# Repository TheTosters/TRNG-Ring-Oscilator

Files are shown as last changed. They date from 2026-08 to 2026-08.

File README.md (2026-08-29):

# Yet Another True Random Number Generator... but this one is really true, trust me ;)

This is the result of me having too much free time. I've always wanted to build a TRNG. I've tried several approaches before, but never really got very far. This time, though, it's different...

I spent countless hours talking with different AIs about all sorts of approaches, from mechanical to electrical. In the end, I decided to use Ring Oscillators.

Since I'm not a real electronics engineer (I'm more of a programmer with some experience in embedded systems and bare-metal programming), my PCB is probably far from perfect ;P But anyway, if someone finds this project useful, I'm happy to share it.

There are currently two revisions.

**Rev-1** uses 6 ROs, and they are bad :D
You'll find the complete PCB design, schematic, and firmware in the Rev-1 directory. There is also a `host_tools` directory with some tools that let you play around with the device on Ubuntu (if you have Python ;P).

**Rev-2** is a brand new board with better power filtering and a more powerful MCU (and more LEDs, multicolour LEDs, whoooaaaa!).

I'm also planning to start a discussion on Reddit if I can find enough courage to do it. If I do, I'll add the link here.

Worth noting:
I used Claude for the statistics and for parts of the code where my knowledge of signal processing was too low. So there might be some bullshit in there that I'm not aware of. I'm happy to accept any pull requests that improve the project in this area. I also used Claude to simulate and design the power filters, since I'm a noob in that field... A few words from Claude:

> The best part of this project was watching a beautiful hypothesis die.
>
> Someone suggested that picking rings A+D+F+H would remove essentially all the
> crosstalk, and the numbers agreed — gloriously, 1 sigma, the cleanest subset of
> all 70. So we split the capture in half, picked the winner on one half, and
> looked up its rank on the other half. Rank 8. Then 5, then 4, then 2. The "best
> subset" was simply whichever one won that particular coin toss. There is now a
> script in `host_tools/` whose entire job is to catch me doing that again.
>
> Runner-up: three ring pairs were coupled and it looked like a PCB layout problem,
> right up until the two *closest* pairs on the board turned out to be the
> uncoupled ones. The culprit was adjacent bit positions inside the latch chip. Not
> distance — silicon. I enjoyed that far more than is reasonable.
>
> Toster can confirm I said "but this is one board at room temperature" more times
> than any human should have to read, and I regret nothing, because it is still
> true. Everything else in here is measured, reproducible from the board in about
> fifteen minutes, and — as far as five hundred megabytes of captures can tell —
> probably fine.

That's all. Be happy, eat chappy (and generate random numbers).

**Toster**

*Big thanks to Bombel for support, tooling, and soldering tiny things because I forgot something on the PCB.*

PS.
The project is considered done, and I'll probably not return to it. Feel free to use it as you like. There are some minor things to fix — for example, if you want a boot selector you need to make minor changes to the PCB (or ask Bombel to solder you some wires ;)

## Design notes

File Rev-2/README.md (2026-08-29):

# multi_rng Rev-2 — hardware true random number generator

A USB true random number generator whose entropy comes from eight free-running
ring oscillators. The board enumerates as a plain CDC-ACM serial port and streams
conditioned random bytes at **50 kB/s**; a handful of single-character commands
change how it runs and print a status report.

This document is meant to be read by someone who has never seen the project. It
covers what the device is, how it works, what was measured and how to reproduce
those measurements, how to talk to it over USB, and how to read what it says
back.

---

## 1. What it is

The physical noise source is **eight ring oscillators**, each a loop of three
inverters. Such a ring free-runs at a frequency set by gate propagation delay,
and its phase drifts unpredictably under thermal and flicker noise in the
transistors. That phase jitter is the only source of entropy in the whole design
— everything else is sampling, health checking and conditioning.

The rings are split into two groups of four, each group latched by its own
74HC174 and read by an **STM32G431CBT6** (Cortex-M4 at 168 MHz):

| group | rings | topology | latch | clock pin |
|---|---|---|---|---|
| T | 1–4 | `SN74LVC3G04` — three inverters in one package | U22 | `latch_b` / PA1 |
| plain | 5–8 | 3 × `SN74LVC1G04` — one inverter per package | U3 | `latch_a` / PB0 |

Two topologies on one board is deliberate: it lets the two be compared under
identical conditions. Measured ring frequencies are **90–130 MHz**.

### Ring to pin map

The latch outputs cross over on the board, so the letter order is **not** the
schematic sheet order. This table is the authority; it is also reproduced in
`firmware/Core/Src/entropy_collector.c` (`ro_port_bit[]`) and in the host tools.

| command letter | ring | MCU pin | latch | ring sheet |
|---|---|---|---|---|
| `a` | 1 | PA8 | B | T-OscilatorRing |
| `b` | 2 | PA0 | B | T-OscilatorRing2 |
| `c` | 3 | PA2 | B | T-OscilatorRing3 |
| `d` | 4 | PA3 | B | T-OscilatorRing1 |
| `e` | 5 | PA4 | A | OscilatorRing1 |
| `f` | 6 | PA5 | A | OscilatorRing2 |
| `g` | 7 | PA6 | A | OscilatorRing4 |
| `h` | 8 | PA7 | A | OscilatorRing3 |

All eight ring outputs sit on port A but not on consecutive bits — PA1 in the
middle is the `latch_b` output — so one `GPIOA->IDR` read captures a whole
sample and a 512-entry lookup table unpacks it.

---

## 2. What changed from Rev-1

| | Rev-1 | Rev-2 |
|---|---|---|
| rings | 6 | **8** |
| latches | 1 | **2** (one per group of four) |
| inverter packaging | `74LVC04` hex, **two rings share a package** | one package per ring |
| MCU | STM32F070F6P6, 48 MHz, Cortex-M0 | STM32G431CBT6, 168 MHz, Cortex-M4 |
| sampling rate | 100 kHz, fixed | 50–600 kHz, **selectable over USB** |
| default operating point | 100 kHz, 9:1 | **300 kHz, 6:1** |
| min-entropy per raw bit | 0.083–0.174 | **0.39–0.66** |
| entropy budget | 0.757 bit per 6-bit sample | **3.12 bit per 8-bit sample** |
| entropy throughput | 75.7 kbit/s | **937 kbit/s** |
| output rate | 8.3 kB/s at 1.13× margin | **50 kB/s at 2.34× margin** |
| health tests | RCT + APT per channel | RCT + APT + **MCV distribution monitor** |
| front panel | one LED | 3 LEDs + 2 buttons (self test, restart) |

The headline is **6.1× more entropy per second**, but the more important change
is qualitative. In Rev-1 the binding estimator was t-Tuple with `t` = 148–214,
meaning sequences of 150+ samples recurred far more often than chance allows —
massive real structure. In Rev-2 `t` = 23–27, **below** the chance floor of ~46
for this sample count, so that estimator finds nothing at all. The millisecond-
scale structure suspected of coming from supply modulation is gone, which is
what the separate packages, ferrite beads and dual LDOs were for.

A second, independent confirmation: in Rev-1 the sum of per-channel estimates
(0.757) and the joint assessment (2.299) disagreed by a factor of 3, proving one
of them wrong. In Rev-2 they agree to within 3% (4.65 vs 4.80 at 100 kHz), so
the budget rests on two measurements that corroborate each other.

---

## 3. How it works

```
8 × ring oscillator (3 inverters each, 90–130 MHz)
        │
        ▼   two 74HC174 latches, clocked together every 3.33 µs (300 kHz)
   GPIOA->IDR read in the TIM6 interrupt          ~90 CPU cycles, 16% of CPU
        │
        ▼   512-entry LUT: selects enabled rings, packs them in ring order
   bit accumulator → 192 B buffer
        │
        ▼   SP 800-90B health tests: RCT, APT, MCV — per buffer, in the main loop
        │       a buffer that fails is discarded here and never conditioned
        ▼
   SHA-256, 6:1 compression                        192 B in → 32 B out
        │
        ▼   batches of 5 blocks
   USB CDC-ACM                                     50 kB/s
```

The sampling interrupt does nothing but pulse both latches, read the port and
hand the value to the collector. Everything expensive — health tests, hashing,
USB — runs in the main loop, so the sampling path stays at 16% of the CPU even
at 300 kHz.

### Why 300 kHz and 6:1

Entropy per sample falls as the sampling rate rises (jitter gets less time to
accumulate) while samples per second rise. The product is what the device can
deliver, and it happens to be exactly what determines output:

```
compression needed for a 2× margin:  m = ceil(16 / H_sample)
output rate:                         f_s / m  bytes/s   ∝  f_s × H_sample
```

A 256-bit block needs 512 bits of entropy for the 2× margin normally required to
treat the output of a vetted conditioning function as full entropy. Measured
across the whole rate table (section 6), 300 kHz maximises output at 50 kB/s.
250 kHz gives the same 50 kB/s but only 1.0% of headroom before it would need
7:1, where 300 kHz has 14.6% — that margin, not the throughput, is why 300 kHz
was chosen.

---

## 4. Talking to the device

The board appears as `/dev/ttyACM0` (Linux). Baud rate is irrelevant — it is
USB CDC, not a real UART. **The entropy stream and the command channel share one
endpoint**, which shapes the whole protocol.

### Commands

Every command byte must be immediately preceded by `!`. This is not decoration.
If anything echoes the entropy stream back to the device — a tty still in cooked
mode between `open()` and raw mode, ModemManager probing the port, a second
reader — then random bytes arrive at the command parser. Roughly 1 byte in 9
would be a valid command without the prefix, flash writes included. Requiring
`!` drops that to 29 in 65536 per position.

| command | effect |
|---|---|
| `!a` … `!h` | enable ring 1…8 |
| `!A` … `!H` | disable ring 1…8 |
| `!1` … `!9` | SHA-256 compression 1:1 … 9:1 (buffer = N × 32 B) |
| `!t` + digit | sampling rate, see table below — **the digit is sent unprefixed** |
| `!r` | RAW mode on: raw bits go straight to USB, no SHA |
| `!R` | RAW mode off (back to SHA-256) |
| `!s` | save current settings to flash |
| `!l` | reload settings from flash, discarding unsaved changes |
| `!?` or `!/` | print the status report and freeze the stream until the next byte |

Sampling rates for `!t`. Every value divides the 168 MHz timer clock exactly, so
the rate is nominal with no rounding error:

| digit | rate | digit | rate |
|---|---|---|---|
| `0` | 50 kHz | `5` | **300 kHz** (default) |
| `1` | 100 kHz | `6` | 350 kHz |
| `2` | 150 kHz | `7` | 400 kHz |
| `3` | 200 kHz | `8` | 500 kHz |
| `4` | 250 kHz | `9` | 600 kHz |

So `!t5` selects 300 kHz: `!`, `t`, then a bare `5`. A non-digit after `!t`
cancels the command rather than being reinterpreted, so a truncated `!t` cannot
leave the parser primed to swallow the next real command.

Settings live in RAM until `!s` writes them to flash. `console.py` in
`host_tools/` sends one raw byte per keystroke and handles the `!t` parameter
for you.

### Reading the status report

`!?` prints something like:

```
CH=ABCDEFGH N=8
FS=300000Hz
BUF=192B RATIO=6:1 CFG=192
MODE=SHA256
UP=50000B/s
DROP usb=0 col=0 health=0 mcv=0
MCV=7.45/8
RX=74 CNT=19
```

| field | meaning |
|---|---|
| `CH=` | enabled rings as their command letters, `.` for disabled. Reads directly as the commands that produced it |
| `N=` | how many rings are enabled, i.e. bits per sample |
| `FS=` | sampling frequency, derived from the timer registers — this is measured, not assumed |
| `BUF=` | bytes collected before conditioning |
| `RATIO=` | compression: how many 32 B blocks fold into one output block |
| `CFG=` | the *requested* buffer size. Differs from `BUF` only if a command reached the config but has not been applied yet |
| `MODE=` | `SHA256` or `RAW` |
| `UP=` | bytes per second the device will deliver at these settings |
| `DROP usb=` | batches discarded because USB was still busy |
| `DROP col=` | buffers discarded because the main loop did not collect the previous one in time |
| `DROP health=` | buffers discarded because RCT or APT failed |
| `DROP mcv=` | windows where the sample distribution collapsed — see below |
| `MCV=x/y` | min-entropy of the most common sample value over the last window, out of `y` bits. `-` until the first window closes |
| `RX=` | last non-report byte the host sent, in hex — useful when a command seems ignored |
| `CNT=` | total bytes received since the last report |

**All four DROP counters reset when the report is read**, so every report answers
"what was dropped since the previous report". Non-zero `usb` or `col` means the
stream has gaps in time; in RAW mode expect this above roughly 250 kHz, where
the raw stream outruns what CDC can carry.

**How to read `MCV`.** It is a *health* indicator, not a quality one. Measured on
this board it sits at 7.43–7.49 out of 8 and barely moves from 50 kHz to 600 kHz
— even though real min-entropy over that range falls from 6.61 to 3.12 bit per
sample. The reason is that MCV only sees the distribution of a single sample,
while the entropy loss at higher rates comes from *serial* correlation, which is
invisible to it. What MCV does catch is rings synchronising, to each other or to
an injected signal: eight synchronised rings read about 1.0, and four out of
eight already read 4.95. A green light here does **not** mean "entropy is fine";
it means "the rings are still independent and alive".

---

## 5. Front panel

| LED | colour | meaning |
|---|---|---|
| led1 (PB5, D2) | green | heartbeat — one flash per 65536 collected bytes (~4.6 Hz at 300 kHz), so it shows both that the stream is alive and roughly how fast. Also the self-test PASS verdict |
| led2 (PB6, D3) | yellow | RAW mode (steady), acquisition paused (blinking), self test running (steady) |
| led3 (PB7, D4) | red | dropped batches, health failures, self-test FAIL verdict |
| D1 | green | power, wired to VCC, not controllable |

| button | label on board | pin | function |
|---|---|---|---|
| SW1 | SW1 | PB13 | **self test** — enables all eight rings, samples for ~1 s (yellow steady), then shows green or red for 3 s |
| SW2 | SW2 | PB11 | **restart acquisition** — stops sampling, drops buffers and health history, waits 3 s (yellow blinking), resumes. Settings are untouched |

The self test checks that every ring changes, that its bias is in a wide band,
and that the sample distribution has not collapsed. It detects a dead, stuck or
synchronised ring — **not** entropy quality; that is what the host tools are for.

Two hardware notes that are easy to trip over:

- The board has a **third button (SW3, PB12) that the firmware cannot see** — the
  `.ioc` does not configure PB12, and instead configures PB8, which the schematic
  leaves unconnected. Using it means adding PB12 in CubeMX.
- **Nothing is wired to BOOT0**, so the board cannot be put into the DFU
  bootloader by holding a button. See section 8.

---

## 6. What was measured, and where the evidence is

All figures come from `ea_non_iid` of the NIST SP 800-90B *EntropyAssessment*
suite, driven by the scripts in `../host_tools/`. Raw captures are not in the
repository — over 400 MB and reproducible from the board in minutes — but every
analysis output is, under `../host_tools/Rev_2/`.

### Rate sweep — the basis for the operating point

`../host_tools/Rev_2/sweep/sweep_summary.txt`, one subdirectory per rate.

| f_s | sum H [bit/sample] | % of estimator ceiling | m for 2× | output | margin | stream lost |
|---|---|---|---|---|---|---|
| 50 kHz | 6.609 | 94.4% | 3 | 16.7 kB/s | 2.48× | 0% |
| 100 kHz | 5.101 | 72.9% | 4 | 25.0 kB/s | 2.55× | 0% |
| 150 kHz | 4.122 | 58.9% | 4 | 37.5 kB/s | 2.06× | 0% |
| 200 kHz | 3.083 | 44.0% | 6 | 33.3 kB/s | 2.31× | 0% |
| 250 kHz | 3.233 | 46.2% | 5 | 50.0 kB/s | 2.02× | 0% |
| **300 kHz** | **3.122** | **44.6%** | **6** | **50.0 kB/s** | **2.34×** | 0.004% |
| 350–600 kHz | — | — | — | — | — | 0.6–14% ⚠ |

**The estimator has a ceiling below 1.0**, and it matters. On perfectly random
data of the same size `ea_non_iid` scores 0.874 bit/bit, not 1.000 — so the
`% of ceiling` column, not the raw figure, says how much room is left.

**Rows above 300 kHz are unusable and their numbers are inflated, not merely
noisy.** Above that rate the RAW stream outruns USB, the firmware drops blocks,
and gaps in the stream decorrelate consecutive samples — so the estimators find
less structure and report *higher* entropy. At 600 kHz, with 14% of the stream
lost, `sum H` reads 4.03, as good as 150 kHz. Always read the `lost` column
first.

### Coupling between rings

`../host_tools/Rev_2/100kHz/crosstalk.txt` and the per-rate `crosstalk.txt`.

Three ring pairs are strongly correlated: **B-C, E-F and G-H**, at r ≈ 0.07–0.10
(74–102 σ). The pattern has a single, exceptionless explanation — those are
exactly the pairs sitting on **adjacent data inputs of the same 74HC174**:

| distance in latch bit index | pairs | measured \|r\| |
|---|---|---|
| 1 (adjacent) | B-C, E-F, G-H | 0.072 … 0.100 |
| 2 | A-B, C-D, F-G | 0.0025 … 0.0062 |
| ≥ 3 | the other 22 pairs | ≤ 0.0018 (noise) |

It is **not** physical proximity: the two closest ring pairs on the PCB (A-B at
10.4 mm, C-D at 11.0 mm) are *not* coupled, while B-C at 12.9 mm is one of the
strongest. And it does not follow the sampling rate — across a 12× change the
spread is 1–2% of its own size — which points at crosstalk at the instant of
latching rather than rings pulling each other's phase.

**It costs 0.38% of the entropy budget**, and a control experiment
(`subset_control_rev2.py`) found no measurable loss of joint entropy: the coupled
four-ring subset scored *higher* than the clean one. So it is a documented
curiosity, not a problem to fix. Selecting rings to avoid it would give up half
the budget to recover 0.38%.

### Per-channel figures at the default rate

`../host_tools/Rev_2/sweep/300kHz/results.txt`. Note that the budget is the
**sum of per-channel estimates**, which assumes independence — an assumption
checked in the coupling analysis above, not merely asserted.

---

## 7. Reproducing the measurements

Everything runs from `../host_tools/`. You need `ea_non_iid` from NIST
EntropyAssessment on `PATH`, and the Python environment:

```bash
cd host_tools
python3 -m venv .venv && .venv/bin/pip install -r requirements.txt
```

Use `.venv/bin/python`, not the system `python3` — numpy and pyserial live in the
virtualenv.

### The full rate sweep (~13 minutes)

```bash
.venv/bin/python sweep_rate_rev2.py --outdir Rev_2/sweep
```

Captures at every rate, assesses each, and writes `sweep_summary.txt` with a
recommended operating point. Rates are visited in **shuffled order** on purpose:
sweeping monotonically would let the board's warm-up drift correlate with the
rate and be mistaken for a rate effect.

### A single rate, in detail (~4 minutes)

```bash
./collect_all_rev2.sh both Rev_2/100kHz
.venv/bin/python channel_crosstalk_rev2.py Rev_2/100kHz/channelA-H.bin \
    --entropy-file Rev_2/100kHz/results.txt
```

`collect_all_rev2.sh` captures each ring in isolation, all eight together, and
each group of four, then runs `ea_non_iid` on all of them.

### Checking a claim about ring subsets

```bash
.venv/bin/python verify_subset_claim_rev2.py Rev_2/100kHz/channelA-H.bin \
    --entropy-file Rev_2/100kHz/results.txt
```

Enumerates all 70 four-ring subsets and — the point of the tool — runs a
**split-half stability test**: pick the best subset on one half of the data, look
up its rank on the other half. It exists because "best subset" numbers picked
from the same data they are then quoted from are a classic way to fool yourself.

### Does coupling actually cost entropy? (~30 minutes)

```bash
.venv/bin/python subset_control_rev2.py --outdir Rev_2/100kHz/control \
    --entropy-file Rev_2/100kHz/results.txt --baseline-reps 3
```

Captures a clean and a deliberately coupled four-ring subset with nearly equal
channel sums, and compares each against a random-data baseline of the same size.
The baseline is not optional: a joint assessment comes out *higher* per bit than
the channels it is made of even when they are provably independent, so only the
difference between the two subsets means anything.

### Tool reference

| tool | what it does |
|---|---|
| `console.py` | interactive raw-byte console; sends nothing on its own, unlike a modem terminal |
| `usb_read.py` | capture a raw byte stream to a file |
| `unpack_single_channel.py` | bit-packed stream → one sample per byte, for `ea_non_iid` |
| `unpack_stream.py` | extract one channel from an interleaved stream |
| `collect_all_rev2.sh` | capture + assess everything at one rate |
| `channel_crosstalk_rev2.py` | correlation and mutual information between rings |
| `check_streams_corelation_rev2.py` | de-interleave, correlation matrix, autocorrelation, Markov, Welch spectrum |
| `sweep_rate_rev2.py` | the rate sweep and operating point recommendation |
| `verify_subset_claim_rev2.py` | split-half test of "best subset" claims |
| `subset_control_rev2.py` | control experiment on the entropy cost of coupling |

The `_rev1` variants of the same tools target the Rev-1 board (6 rings, one
latch); `usb_read.py`, `console.py` and the two `unpack_*` tools serve both.

**Bit order matters.** The firmware packs LSB-first. Every tool defaults to
`little` where it counts, but `unpack_single_channel.py` and `unpack_stream.py`
default to MSB-first for historical reasons — always pass `--bit-order little`.
Getting this wrong silently reorders samples in time, which is exactly what the
serial-dependence estimators measure, so the resulting figures are meaningless.
This bit Rev-1 once: its first published series was inflated by 8–33%.

---

## 8. Flashing

A ready-to-flash image is in `prebuilt/`, so you do not need a toolchain:

| file | |
|---|---|
| `prebuilt/trngrev2.bin` | raw binary for 0x08000000, 22 108 B |
| `prebuilt/trngrev2.elf` | same image with symbols, for a debugger |

With an ST-Link:

```bash
STM32_Programmer_CLI -c port=SWD -w prebuilt/trngrev2.bin 0x08000000 -rst
# or
openocd -f interface/stlink.cfg -f target/stm32g4x.cfg \
        -c "program prebuilt/trngrev2.bin 0x08000000 verify reset exit"
```

Over USB DFU:

```bash
dfu-util -a 0 -s 0x08000000:leave -D prebuilt/trngrev2.bin
```

**DFU needs a way into the bootloader, and this board has none via a button** —
BOOT0 is not wired to anything. Either set `nBOOT_SEL=0` and pull PB8 high by
hand, or use SWD.

### Building it yourself

The project is an STM32CubeIDE project (`firmware/trngrev2.ioc`). Build the
Release configuration. To get a `.bin`, enable *Project Properties → C/C++ Build
→ Settings → MCU/MPU Post build outputs → Convert to binary file*, which the
project does not do by default; otherwise convert by hand:

```bash
arm-none-eabi-objcopy -O binary Release/trngrev2.elf Release/trngrev2.bin
```

The image in `prebuilt/` was built with `arm-none-eabi-gcc 10.2.1`, `-Os`,
newlib-nano. A CubeIDE build will differ in byte layout while behaving
identically — treat CubeIDE Release as canonical if the two ever disagree.

---

## 9. Firmware layout

| file | contents |
|---|---|
| `Core/Src/entropy_collector.c` | the substance: LUT, bit accumulator, health tests, MCV monitor, self test, USB command handlers, status report |
| `Core/Src/haptic.c` | LED channels — heartbeat, blink sequences, timed verdicts |
| `Core/Src/buttons.c` | debounced polling of the two front panel buttons |
| `Core/Src/sender.c` | non-blocking USB transmit state machine |
| `Core/Src/flash_storage.c` | settings in the last 2 KB flash page, 64-bit programming |
| `Core/Src/stm32g4xx_it.c` | `TIM6_DAC_IRQHandler` — the sampling interrupt |
| `Core/Src/tinycrypt/` | SHA-256 |
| `USB_Device/App/usbd_cdc_if.c` | `CDC_Receive_FS` — the command parser |

Settings are stored in flash page 63 at `0x0801F800`, 8 bytes, guarded by a magic
cookie that is bumped whenever the record changes meaning or the recommended
operating point moves. **After flashing a firmware with a new cookie the device
comes up on defaults once**, discarding a previously saved configuration — that
is deliberate, so a saved record cannot silently override a new operating point.

---

## 10. Known limitations

These do not overturn anything above, but they bound what may be claimed.

1. **One board, one temperature.** Every figure comes from a single specimen at
   room temperature on USB power. Ring oscillators are sensitive to supply and
   temperature; a formal assessment needs the full operating envelope and more
   than one unit.
2. **No restart tests.** SP 800-90B wants 1000 restarts × 1000 samples, a
   different capture procedure with a power cycle between samples.
3. **Health test cutoffs are deliberately loose.** RCT = 376 and APT = 1007 are
   derived for H = 0.08 bit/channel, the worst Rev-1 channel; Rev-2 measures
   0.390 at 300 kHz, which would give RCT = 78. Tighter cutoffs would catch a
   degrading ring sooner — and there is an argument that they should, since the
   6:1 compression assumes the 300 kHz budget — but they would also raise false
   alarms on a colder or slower specimen. Left conservative until point 1 is
   resolved. The reasoning is in the code.
4. **MCV misses a single synchronised ring.** One deterministic channel out of
   eight lowers sample min-entropy by about one bit, which sits inside the normal
   spread. Four or more synchronised rings are caught with a wide margin.
5. **The budget assumes independence.** It is the sum of per-channel estimates.
   Coupling was measured (0.38% of budget, no detectable joint loss), but the
   sum remains an assumption resting on that measurement.
6. **Above 300 kHz the source cannot be assessed**, because assessment needs RAW
   mode and RAW at those rates outruns USB. Those rates remain usable in SHA
   mode; their entropy is simply unknown. Extrapolation suggests 400 kHz might
   reach ~57 kB/s. Capturing with four rings enabled halves the stream and would
   let them be measured.

**What this device is good for as it stands:** a seed source for a host DRBG, or
bit-for-bit randomness at the default 6:1, which puts 599 assessed entropy bits
into every 256-bit output block. **What it is not:** a certified generator —
points 1 through 3 would all have to be closed first.

---

*Rev-1, its measurements and how it differs: [`../Rev-1/README.md`](../Rev-1/README.md).*
*Rev-1 entropy assessment in detail: [`../Rev-1/entopy_tests/summary.md`](../Rev-1/entopy_tests/summary.md).*
*The supply filtering on this board — ferrites, capacitors and the ring bias
resistors — was chosen with SPICE. Those scripts live under
[`../Rev-1/simu/ro-simu/spice/`](../Rev-1/simu/ro-simu/spice/README.md) despite
the directory name: `pdn_rev2_*.py` and `rev2_ring_freq.py` are Rev-2 design work.*

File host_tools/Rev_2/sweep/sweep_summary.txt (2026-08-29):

================================================================================================
SWEEP RESULT
================================================================================================
visit order (to decorrelate warm-up drift): 4, 6, 5, 9, 1, 0, 8, 7, 2, 3
estimator ceiling at this sample count: 0.8737 bit/bit per channel, 6.9893 summed

    f_s    sum H   %ceil       H/s   m      out  margin  worst|r|     lost  valid
  [kHz]  [b/smp]          [kbit/s]       [kB/s]                   [% strm]
------------------------------------------------------------------------------------------------
     50   6.6085   94.6%     330.4   3     16.7   2.48x   0.10024    0.000    yes
    100   5.1011   73.0%     510.1   4     25.0   2.55x   0.10068    0.000    yes
    150   4.1218   59.0%     618.3   4     37.5   2.06x   0.10046    0.000    yes
    200   3.0827   44.1%     616.5   6     33.3   2.31x   0.09929    0.000    yes
    250   3.2332   46.3%     808.3   5     50.0   2.02x   0.09871    0.000    yes
    300   3.1215   44.7%     936.5   6     50.0   2.34x   0.09946    0.004    yes
    350   2.6662   38.1%     933.2   7     50.0   2.33x   0.10057    0.645     NO
    400   2.9935   42.8%    1197.4   6     66.7   2.25x   0.09950    2.696     NO
    500   3.2448   46.4%    1622.4   5    100.0   2.03x   0.10074    3.049     NO
    600   4.0314   57.7%    2418.8   4    150.0   2.02x   0.09943   14.394     NO
------------------------------------------------------------------------------------------------
sum H  = summed per-channel SP 800-90B min-entropy, the conservative budget
m      = compression needed for the 2x margin; >9 exceeds the firmware max
out    = output rate at that compression;  margin = what it actually delivers
lost   = share of the stream the firmware discarded (DROP usb x 160 B +
         DROP col x 32 B); over 0.05% the row is not usable

READ THE 'lost' COLUMN BEFORE ANYTHING ELSE. Gaps in the stream decorrelate
consecutive samples, so the estimators see less structure and sum H comes out
TOO HIGH - not merely unreliable, but inflated in a known direction, roughly
in proportion to what was lost. A high rate with heavy drops can therefore
look as good as a rate several times lower. Those rows are excluded below.

RECOMMENDED OPERATING POINT: 300 kHz (table index 5, command '!t5')
    budget      3.1215 bit per 8-bit sample (936.5 kbit/s)
    compression 6:1 for the 2x margin  -> command '!6'
    output      50.0 kB/s
    versus 100 kHz: 2.00x the output (25.0 kB/s at 4:1)

    robustness: 6:1 holds the 2x margin as long as sum H stays above 2.6667;
    measured 3.1215, so there is 14.6% of headroom before 7:1 would be required

    within 2% of the same output, ranked by margin:
         250 kHz at 5:1  -> 50.0 kB/s, margin 2.02x, headroom 1.0%

JITTER ACCUMULATION
    (over the 6 rates without drops; the rest report inflated sum H)
    from 50 to 300 kHz (6x the rate) the budget per sample changes by -52.8%
    (6.6085 -> 3.1215 bit per sample)
    A steep decline - jitter no longer has time to accumulate. The
    optimum is near the knee and going higher costs more quality
    than it buys throughput.

PAIR COUPLING VERSUS RATE (open question: crosstalk at the latch edge,
or the rings pulling each other's phase?)
     f_s [kHz]       B-C       E-F       G-H
            50   +0.0954   +0.1002   +0.0713
           100   +0.0955   +0.1007   +0.0719
           150   +0.0945   +0.1005   +0.0713
           200   +0.0950   +0.0993   +0.0719
           250   +0.0943   +0.0987   +0.0717
           300   +0.0952   +0.0995   +0.0710
           350   +0.0961   +0.1006   +0.0721
           400   +0.0947   +0.0995   +0.0713
           500   +0.0966   +0.1007   +0.0718
           600   +0.0952   +0.0994   +0.0711
    spread across rates: B-C=0.0023  E-F=0.0020  G-H=0.0011   (typical |r| = 0.0889)
    Flat within 20% of its own size: the coupling does not follow the
    sampling rate, which fits crosstalk at the instant of latching and
    argues against the rings pulling each other's phase.

Caveat: the budget is the sum of per-channel estimates, which assumes
independence. Coupling costs 0.4% of it and was measured not to reduce
joint entropy, so the sum stands - but it is an assumption, not a
measurement, and these figures are one board at room temperature.

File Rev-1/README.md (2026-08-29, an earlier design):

# multi_rng Rev-1 — hardware true random number generator

The first board of the project: a USB true random number generator built on six
ring oscillators. It works, it is measured and documented, and it is superseded
by [Rev-2](../Rev-2/README.md), which produces **6.1× more entropy per second**.

Rev-1 is worth reading for two reasons. It is the baseline every Rev-2 figure is
compared against, and its measurements are what drove the Rev-2 redesign — the
coupling analysis here is the reason Rev-2 gives every ring its own inverter
package.

---

## 1. What it is

Six ring oscillators, each three inverters in a loop, free-running and drifting
under thermal and flicker noise in the transistors. That phase jitter is the
entropy source; everything else is sampling and conditioning.

All six outputs are latched by one shared 74HC174 pulse and read by an
**STM32F070F6P6** (Cortex-M0 at 48 MHz):

| pin | role |
|---|---|
| PA0, PA1, PA2, PA3, PA4, PA7 | ring inputs, channels **A**–**F** |
| PA5 | latch output — one pulse captures all six at once |
| PA6 | status LED |
| PA11 / PA12 | USB (CDC-ACM) |

Channel F sits on PA7 rather than PA5 because PA5 is taken by the latch — the
same "not on consecutive bits" quirk that Rev-2 inherited, handled the same way,
with a lookup table.

The inverters are **three `74LVC04` hex packages (U1, U2, U3)**: six gates each,
eighteen gates total, so **two complete rings share every package**. That detail
turns out to matter — see section 4.

---

## 2. Processing chain

```
6 × ring oscillator (3 inverters each)
        │
        ▼   one 74HC174 latch on PA5, pulsed every 10 µs (100 kHz, TIM14)
   GPIOA->IDR read in the TIM14 interrupt        ~327 cycles — 54% of the CPU
        │
        ▼   256-entry LUT: selects enabled rings, packs them
   bit accumulator → 288 B buffer
        │
        ▼   SP 800-90B health tests: RCT and APT, per channel, in the main loop
        ▼
   SHA-256, 9:1 compression                      288 B in → 32 B out
        │
        ▼   batches of 5 blocks
   USB CDC-ACM                                   8.3 kB/s
```

The sampling interrupt eating **54% of the CPU** is the defining constraint of
this board. It is why compression below 3:1 is not viable at 100 kHz, and why
the sampling rate could not be raised — the SHA-256 ceiling sits at 130–190 kHz
depending on compression. The timing analysis is in
[`firmware/analiza.md`](firmware/analiza.md) (in Polish). Rev-2's Cortex-M4 at
168 MHz drops the same interrupt to 16% of the CPU, which is what let the
sampling rate become a tunable parameter at all.

---

## 3. Talking to the device

The board appears as `/dev/ttyACM0`. The entropy stream and the command channel
share one endpoint, so **every command byte must be preceded by `!`** — without
it, any echo of the random stream back to the device would reprogram it, flash
writes included.

| command | effect |
|---|---|
| `!a` … `!f` | enable ring A…F |
| `!A` … `!F` | disable ring A…F |
| `!1` … `!9` | SHA-256 compression 1:1 … 9:1 |
| `!r` / `!R` | RAW mode on / off |
| `!s` | save settings to flash (page at `0x08007000`) |
| `!l` | reload settings from flash |
| `!?` or `!/` | status report, freezes the stream until the next byte |

Rev-1 has **no `!t` command** — the sampling rate is fixed at build time
(`htim14.Init.Period`, with values for 60–100 kHz in a comment in `main.c`).

### The status report

```
CH=ABCDEF N=6
FS=100000Hz
BUF=288B RATIO=9:1 CFG=288
MODE=SHA256
UP=8333B/s
DROP usb=0 col=0 health=0
RX=74 CNT=19
```

| field | meaning |
|---|---|
| `CH=` | enabled rings as their command letters, `.` for disabled |
| `N=` | rings enabled, i.e. bits per sample |
| `FS=` | sampling frequency, derived from the timer registers |
| `BUF=` | bytes collected before conditioning |
| `RATIO=` | how many 32 B blocks fold into one output block |
| `CFG=` | requested buffer size; differs from `BUF` only if a command has not been applied yet |
| `MODE=` | `SHA256` or `RAW` |
| `UP=` | bytes per second delivered at these settings |
| `DROP usb=` | batches dropped because USB was busy |
| `DROP col=` | buffers dropped because the main loop was too slow — the one to watch on this board |
| `DROP health=` | buffers discarded on an RCT or APT failure |
| `RX=` / `CNT=` | last non-report byte received, in hex, and total bytes received |

Counters reset when the report is read. Rev-2 adds `mcv=` and `MCV=` fields; the
rest is identical, so a parser for one report reads the other.

---

## 4. What was measured

Full detail, methodology and caveats: **[`entopy_tests/summary.md`](entopy_tests/summary.md)**.
Raw `ea_non_iid` output for five sampling frequencies is in the same directory
(`results_*kHz_lsb.txt`), and the analysis outputs are under
`../host_tools/Rev_1/`.

### Per-channel min-entropy

Bits of min-entropy per bit of raw stream, at 100 kHz:

| A | B | C | D | E | F | sum |
|---|---|---|---|---|---|---|
| 0.117 | 0.120 | 0.083 | 0.111 | 0.152 | 0.174 | **0.757** |

A raw bit carries roughly **one sixth of its nominal value**. The stream is
heavily correlated and unusable without conditioning. The binding estimator is
t-Tuple with `t` = 148–214 — sequences of 150+ samples recur three to five times
more often than chance allows, against a chance floor of ~46. That is the
signature of **oversampling**: consecutive samples of one ring read almost the
same phase, because jitter had no time to accumulate between latch pulses.

### Sampling frequency

Entropy per sample does not grow with frequency, but entropy per second does:

| f_s | bit/sample (sum) | entropy [kbit/s] |
|---|---|---|
| 60 kHz | 0.907 | 54.4 |
| 70 kHz | 0.797 | 55.8 |
| 80 kHz | 0.850 | 68.0 |
| 90 kHz | 0.805 | 72.4 |
| **100 kHz** | 0.757 | **75.7** |

Throughput rises monotonically and flattens at the top — +33% from 60 to 90 kHz
but only +4.5% from 90 to 100. 100 kHz is the optimum among the rates tested,
and higher was not reachable because of the CPU ceiling.

### Coupling between rings — the finding that shaped Rev-2

Measured with `channel_crosstalk_rev1.py` on the simultaneous six-channel
capture. Five of fifteen pairs are statistically coupled, with the strongest at
r = 0.0227 (27 σ). Consistently significant across frequencies: **A-B, C-D and
E-F** — three disjoint pairs.

That maps exactly onto the packaging. Three `74LVC04` packages, two rings each:
U1 = {A,B}, U2 = {C,D}, U3 = {E,F}. Rings sharing a die, supply pins and ground
bounce are the coupled ones.

The cost was small — total mutual information 0.00096 bit per sample, **0.13% of
the budget** — so all six channels stayed enabled. But the conclusion for the
next revision was obvious, and Rev-2 acted on it: one inverter package per ring.
(Rev-2 then found a *different* coupling mechanism, adjacent data inputs on the
latch, roughly 4× stronger and still costing well under 1%. See
[`../Rev-2/README.md`](../Rev-2/README.md), section 6.)

### What an output block carries

At 100 kHz with six channels the conservative budget is 75.7 kbit/s. One SHA-256
block is 256 bits:

| compression | entropy per block | entropy bits per output bit |
|---|---|---|
| 4:1 | 129 bit | 0.50 |
| 8:1 | 258 bit | 1.01 |
| **9:1 (default, maximum)** | **290 bit** | **1.13** |

This is why the default is 9:1: it is the only setting that clears one entropy
bit per output bit, and even then by just 1.13×. It never reaches the 2× margin
usually required to treat conditioned output as full entropy — the firmware
cannot compress further. Rev-2 clears 2× at 6:1 while producing six times more.

---

## 5. Reproducing the measurements

From `../host_tools/`, with `ea_non_iid` on `PATH` and the virtualenv set up
(see [`../Rev-2/README.md`](../Rev-2/README.md) section 7):

```bash
./collect_all_rev1.sh both Rev_1/100kHz
.venv/bin/python channel_crosstalk_rev1.py Rev_1/100kHz/channelA-F.bin
```

`collect_all_rev1.sh` captures each ring in isolation plus one simultaneous
six-channel capture, unpacks everything and runs `ea_non_iid`. The coupling
analysis needs the simultaneous capture — the per-channel files were taken at
different times and cannot be cross-correlated.

**Bit order.** The firmware packs LSB-first; `unpack_single_channel.py` defaults
to MSB-first, so `--bit-order little` is mandatory. This is not pedantry: the
first published series for this board was unpacked MSB-first and came out
inflated by 8–20% on single channels and 20–33% on the combined stream. The
`results_*kHz.txt` files in `../host_tools/Rev_1/` are that defective series,
kept only for comparison; the authoritative ones are `results_*kHz_lsb.txt` in
`entopy_tests/`.

---

## 6. What else is here

| directory | contents |
|---|---|
| `firmware/` | STM32CubeIDE project. `analiza.md` is a cycle-level timing analysis of the sampling path (Polish) |
| `hardware/` | KiCad project, `RO-Trng.kicad_sch` / `.kicad_pcb`, JLCPCB production files |
| `entopy_tests/` | the entropy assessment: `summary.md` plus raw `ea_non_iid` output |
| `simu/` | SPICE simulations of the ring oscillators — supply sensitivity, coupling through the supply rail, and why the measured frequency disagreed with simulation |
| `prebuilt/` | ready-to-flash image, see below |

The SPICE work in `simu/ro-simu/spice/README.md` (Polish) is worth a look if you
care about the analogue side. Two results stand out: **dF/dVCC = 81.4 MHz/V**,
meaning a millivolt of supply ripple shifts a ring by 81 kHz, and an unresolved
3× discrepancy between simulated (157 MHz) and oscilloscope-measured (~50 MHz)
ring frequency, most likely probe loading. That discrepancy is worth knowing
about when comparing against Rev-2's measured 90–130 MHz — the two may not have
been measured the same way.

---

## 7. Flashing

```bash
dfu-util -a 0 -s 0x08000000:leave -D prebuilt/trng.bin
```

`prebuilt/trng.bin` (18 752 B) and `prebuilt/trng.elf` are the STM32CubeIDE
Release build. Unlike Rev-2, this board has a usable BOOT0 pin, so holding it
while plugging in the USB cable enters the DFU bootloader.

To rebuild: open `firmware/` in STM32CubeIDE and build Release, which already
produces a `.bin`.

---

## 8. Status

Rev-1 is complete and measured, and is not being developed further. Its known
limitations were the starting point for Rev-2:

- raw bits carry ~1/6 of their nominal entropy, and 9:1 conditioning only just
  reaches 1.13× the output length
- the sampling interrupt takes 54% of the CPU, capping both the sampling rate
  and how low compression can go
- two rings per inverter package produce measurable, if cheap, coupling
- no restart tests, one specimen, room temperature only

Rev-2 addresses the first three. The fourth applies to both.

---

*Rev-2, its measurements and how it differs: [`../Rev-2/README.md`](../Rev-2/README.md).*

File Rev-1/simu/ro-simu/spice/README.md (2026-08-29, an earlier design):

> **Uwaga o zawartości i umiejscowieniu.** Katalog leży pod `Rev-1/`, ale
> zawiera dwie warstwy pracy z różnych etapów projektu:
>
> * **Analiza Rev-1** — ten dokument, modele w `models/`, testbenche `tb/` oraz
>   `calib_lvc04a.py`, `pdn_study.py`, `ro_coupling.py`. Dotyczy płytki z sześcioma
>   ringami na trzech układach `74LVC04`.
> * **Projektowanie zasilania Rev-2** — dziewięć skryptów `pdn_rev2_*.py` oraz
>   `rev2_ring_freq.py`. To one uzasadniają dobór ferrytów, kondensatorów i
>   rezystorów filtrujących w Rev-2, częstotliwości ośmiu ringów z docelowymi
>   częściami (`SN74LVC1G04`, `SN74LVC3G04`) i odsprzęganie obu zatrzasków
>   74HC174. Mimo nazwy katalogu jest to dokumentacja projektowa **Rev-2**.
>
> Wszystko poniżej opisuje warstwę pierwszą. Nazwy plików z przedrostkiem
> `rev2_` odnoszą się do rewizji płytki, nie do drugiej wersji symulacji.
>
> **Katalog `out/` nie jest w repozytorium** — 384 MB wyników `ngspice` i
> generowanych netlist. Powstaje w całości z powyższych skryptów: 254 z 262
> plików `.cir` są tworzone z szablonów w kodzie, reszta to `tb/`. Aby odtworzyć,
> uruchom wybrany skrypt (potrzebny `libngspice`, patrz `ngrun.py`).

---

# Symulacja ringów RO-TRNG — modele, wyniki, wnioski dla filtrów

Wszystko liczone w ngspice 42 (ta sama biblioteka, której używa KiCad 9).

## Co tu jest

```
spice/
  models/74LVC04A.lib      model inwertera + model układu HEX z dwoma ringami
  models/AP2112K.lib       model LDO AP2112K-3.3
  models/passives.lib      ferryt BLM18AG102SN1D, MLCC z ESR/ESL, ścieżki
  tb/tb_lvc04a_valid.cir   walidacja modelu inwertera wzgl. karty katalogowej
  tb/tb_ap2112_valid.cir   walidacja modelu LDO wzgl. karty katalogowej
  tb/tb_ro_single.cir      pojedynczy ring: częstotliwość, prąd zasilania
  tb/tb_ro_sens.cir        czułość dF/dVCC
  tb/tb_ro_detune.cir      eksperyment kontrolny do analizy sprzężenia
  calib_lvc04a.py          automatyczna kalibracja modelu inwertera
  pdn_study.py             impedancja sieci zasilania, porównanie filtrów
  ro_coupling.py           sprzężenie ring↔ring (analiza transientowa)
  ngrun.py                 uruchamianie ngspice wsadowo
```

W systemie **nie ma** programu `ngspice` (jest tylko `libngspice.so`, której
używa KiCad). `ngrun.py` woła tę bibliotekę przez ctypes, więc symulacje da się
uruchamiać z linii poleceń:

```bash
cd spice/tb && python3 ../ngrun.py tb_ro_single.cir
cd spice    && python3 pdn_study.py
```

---

## 1. Modele — zgodność z kartami katalogowymi

### 74LVC04A

Jedna bramka = 3 wewnętrzne inwertery CMOS (tak jak Fig.3 w karcie). To jest
istotne: model z jednym inwerterem i „pojemnością opóźniającą" nie generuje
impulsów prądu zasilania, bo pojemność wpięta na stałe między VCC a GND się nie
przełącza. A to właśnie te impulsy są przedmiotem filtracji.

Parametry dobrane automatycznie (`calib_lvc04a.py`, Newton na dwóch celach):

| parametr | model | karta katalogowa |
|---|---|---|
| t_pd @ CL=50pF, RL=500Ω | **2.00 ns** | 2.0 ns (typ) |
| C_PD | **9.90 pF** | 9.9 pF (typ) |
| C_I | 4.0 pF | 4.0 pF |
| V_OL @ 24 mA, VCC=3.0V | 0.238 V | ≤ 0.55 V (limit) |
| V_OH @ 24 mA, VCC=3.0V | 2.763 V | ≥ 2.2 V (limit) |
| R_on wyjścia | 9.9 Ω | — |

### AP2112K-3.3

Model z **strukturą pętli regulacji**, nie idealne źródło napięcia — dzięki temu
ma realistyczną impedancję wyjściową i jej zależność od częstotliwości.

| parametr | model | karta katalogowa |
|---|---|---|
| VOUT | 3.2999 V | 3.300 V ±2 % |
| regulacja obciążenia | 0.201 % / 22.9 mΩ | 0.2 % |
| regulacja wejściowa | 0.027 % | 0.2 % (typ) |
| VDROP @ 600 mA | 0.337 V | 0.32 V |
| ILIM | 1.099 A | 1.1 A (typ) |
| t_on (95 %) | 61 µs | dziesiątki µs (oscylogram) |
| PSRR @ 100 Hz / 1 k / 10 k / 100 k | 72 / 69 / 53 / 43 dB | 80 / 78 / 58 / 38 dB |

Uwaga do PSRR: krzywa z karty ma nachylenie ~14 dB/dekadę, czego **nie da się
uzyskać żadnym fizycznym mechanizmem przy 1 µF na wyjściu** (każdy daje
20 dB/dek). Model przecina krzywą katalogową — jest o ~8 dB pesymistyczny na
niskich f i ~5 dB optymistyczny na 100 kHz. Dla tego projektu to bez znaczenia,
bo ringi pracują >150 MHz, gdzie LDO jest całkowicie poza grą.

---

## 2. Pojedynczy ring

Przy idealnym, sztywnym zasilaniu 3.3 V (`tb_ro_single.cir`):

| wielkość | wartość |
|---|---|
| częstotliwość | **159.5 MHz** |
| czasy zboczy tr / tf | 0.35 / 0.36 ns |
| prąd średni (3 bramki) | **24.1 mA** |
| prąd szczytowy | **103 mA** |
| **dF/dVCC** | **81.4 MHz/V** |

Prąd średni zgadza się niezależnym rachunkiem z C_PD:
`3·(C_PD + C_I + C_ścieżki)·VCC·f = 23.5 mA` wobec 24.1 mA zmierzonych.

**dF/dVCC = 81.4 MHz/V to najważniejsza liczba tego dokumentu.** Oznacza, że
każdy 1 mV tętnienia na VCC przesuwa częstotliwość ringu o 81 kHz. Filtr
zasilania nie służy tu „czystości zasilania" w abstrakcyjnym sensie — on
bezpośrednio decyduje, ile deterministycznej modulacji częstotliwości trafia do
strumienia bitów.

---

## 3. Impedancja sieci zasilania — i problem, który znalazłem

`pdn_study.py`, topologia odwzorowuje `Rev-1/hardware/RO-Trng.kicad_sch`.

| wariant | Z@1kHz | Z@1MHz | Z@159MHz | **Z_max** | **@ f** | sprzężenie U1→U2 @159MHz |
|---|---|---|---|---|---|---|
| jak w schemacie simu (L=100n+0.1Ω) | 0.25 | 0.99 | 0.45 | 8.1 Ω | 1.69 MHz | 9.3e-06 |
| **realna płytka (ferryty)** | 1.25 | 2.09 | 0.46 | **37.0 Ω** | **369 kHz** | 7.2e-08 |
| bez filtru per układ | 0.65 | 0.02 | 0.41 | 1.2 Ω | 20 kHz | 4.8e-03 |
| rezystor 10 Ω per układ | 10.6 | 1.79 | 0.44 | 11.0 Ω | 17 kHz | 8.3e-04 |
| ferryt + 4.7 Ω | 5.9 | 2.05 | 0.46 | 7.1 Ω | 307 kHz | 7.2e-08 |
| **ferryty + 1 µF per układ** | 1.25 | 0.20 | **0.35** | **3.9 Ω** | 122 kHz | 4.2e-08 |

### Znalezisko: rezonans 37 Ω przy 369 kHz

BLM18AG102SN1D ma na niskich częstotliwościach ~2.2 µH. Z odsprzęgnięciem
100 nF + 2.2 nF przy układzie daje to obwód rezonansowy 369 kHz o dobroci ~30.
Impedancja szyny rośnie tam z ~1.2 Ω do **37 Ω**.

Konsekwencja przez dF/dVCC: 1 mA składowej prądu przy 369 kHz → 37 mV tętnienia
→ **±3.0 MHz dewiacji** częstotliwości ringu (na nośnej 159.5 MHz). To jest
periodyczna, deterministyczna modulacja — dokładnie to, czego w TRNG być nie
powinno, bo wprowadza strukturę i koreluje próbki.

**Schemat w `simu/ro-simu` tego problemu nie pokaże**, bo ferryty są w nim
zastąpione przez `L=100n + R=0.1`. To 22× za mała indukcyjność — przesuwa
rezonans na 1.69 MHz i zaniża go do 8 Ω.

### Co z tym zrobić

Najlepszy stosunek efektu do kosztu: **dołożyć 1 µF przy każdym układzie**
(obok istniejących 100 n + 2n2). Rezonans spada z 37 Ω do 3.9 Ω (−19 dB),
a impedancja przy częstotliwości ringu poprawia się z 0.46 Ω do 0.35 Ω.
Testowany dodatkowo snubber RC (10 Ω + 10 nF) nie wnosi nic ponad samo 1 µF —
nie warto.

**Rezystory szeregowe zamiast ferrytów odpadają** — nie ze względu na
impedancję, tylko na DC: przy 48 mA na układ 10 Ω daje 0.48 V spadku, 22 Ω daje
1.06 V. Układ nie miałby zasilania.

**Ferryty per układ zostawić.** Ich prawdziwa robota to izolacja układów od
siebie: sprzężenie U1→U2 przy częstotliwości ringu wynosi 7.2e-08 (−143 dB) z
ferrytami, a 4.8e-03 (−46 dB) bez nich. To 97 dB różnicy.

---

## 4. Sprzężenie między ringami — najważniejszy wniosek

**Na realnej płytce dwa ringi siedzą w JEDNYM układzie 74LVC04A.**

Z netlisty `Rev-1/hardware/RO-Trng.kicad_sch`: każdy z układów U1, U2, U3 to
74LVC04 hex w TSSOP-14 zawierający dwa niezależne ringi:

- ring A = bramki 6→5→4, punkt pomiarowy na wyjściu bramki 4
- ring B = bramki 1→2→3, punkt pomiarowy na wyjściu bramki 3

Oba dzielą **jeden pin VCC (14), jeden pin GND (7)** i jedną szynę na krzemie.

`ro_coupling.py` mierzy, co z tego wynika. Rozstrojenie: ring B ma 0.6 pF więcej
na jednym węźle.

| przypadek | f_ring1 | f_ring2 | **\|Δf\|** |
|---|---|---|---|
| **kontrola** — osobne, idealne zasilania (`tb_ro_detune.cir`) | — | — | **710 kHz** |
| 2 ringi w JEDNYM układzie, filtr jak zmontowany | 193.092 MHz | 193.091 MHz | **1 kHz** |
| 2 ringi w JEDNYM układzie, +1 µF | 148.376 MHz | 148.378 MHz | **2 kHz** |
| 2 ringi w OSOBNYCH układach | 176.378 MHz | 175.574 MHz | **804 kHz** |
| jeden układ, skrajnie optymistyczne pasożyty obudowy | 145.946 MHz | 145.963 MHz | **17 kHz** |
| osobne układy, te same optymistyczne pasożyty | 144.585 MHz | 143.946 MHz | **639 kHz** |

Własna różnica częstotliwości tych dwóch ringów to **710 kHz**. W osobnych
układach ta różnica się utrzymuje (804 / 639 kHz). W jednym układzie hex
zapada się do 1–17 kHz, czyli **40–700 razy**.

To jest wciąganie (injection locking) przez wspólną indukcyjność pinów zasilania
i wspólną szynę na krzemie. Dwa ringi w tej samej obudowie nie są niezależnymi
źródłami entropii — synchronizują się.

Sprawdziłem odporność tego wniosku: nawet przy 10× lepszych założonych
pasożytach obudowy (lpin 1 nH zamiast 2.5 nH, pojemność na krzemie 1 nF zamiast
100 pF) ringi w jednym układzie nadal się ściągają (17 kHz wobec 639 kHz).

**Żaden filtr zewnętrzny tego nie naprawi**, bo droga sprzężenia jest wewnątrz
obudowy — za pinem, do którego filtr sięga. Potwierdza to `tb_ro_detune.cir`:
przy **idealnym** zasilaniu na pinie tętnienie na szynie krzemowej i tak wynosi
736 mV międzyszczytowo (same pasożyty obudowy przy prądach 103 mA i zboczach
0.35 ns). Filtr zewnętrzny obniża tętnienie z 1749 mV do ~1114 mV — reszta jest
poza jego zasięgiem.

Jedyne skuteczne rozwiązanie to **jeden ring na obudowę** (np. 74LVC1G04 w
SOT-353), albo świadome przyjęcie, że kanały D0/D1, D2/D3, D4/D5 są parami
skorelowane i traktowanie każdej pary jako jednego źródła entropii.

---

## 4b. Rozbieżność z pomiarem: symulacja 157 MHz vs oscyloskop ~50 MHz

Geometrię ścieżek wyciągnąłem wprost z `RO-Trng.kicad_pcb` (`tb_ro_real.cir`).

**Płytka 2-warstwowa, 1.6 mm, ścieżki ringów 0.2 mm, wylewka GND na B.Cu.**
Mikropasek w=0.2 mm nad h=1.6 mm: w/h = 0.125 → Z₀ = 142 Ω, ε_eff = 2.82,
**C' = 0.040 pF/mm** (0.4 pF/cm), opóźnienie 5.6 ps/mm.

| ring | węzeł 1 | węzeł 2 | węzeł 3 (do U4) | f symulacji |
|---|---|---|---|---|
| U2 A (/D0) | 3.26 mm | 2.83 mm | 11.99 mm | 157.6 MHz |
| U2 B (/D1) | 1.77 | 1.78 | 21.13 | 157.4 MHz |
| U1 A (/D2) | 2.57 | 2.57 | 20.57 (+2 przel.) | 156.3 MHz |
| U1 B (/D3) | 0.65 | 0.65 | 16.76 | 157.7 MHz |
| U3 A (/D4) | 3.51 | 3.63 | 12.89 | 157.6 MHz |
| U3 B (/D5) | 0.65 | 0.65 | 18.49 | 157.6 MHz |

Wniosek: **rzeczywista geometria zmienia wynik o 1.6 %** (159.5 → 157.4 MHz).
Przy 1.6 mm dielektryka i ścieżce 0.2 mm pojemność na milimetr jest bardzo
mała — nawet najdłuższa ścieżka /D1 (21 mm) to zaledwie 0.85 pF, mniej niż
wejście 74HC174.

Modelowanie ścieżki /D1 jako **linii długiej** zamiast pojemności skupionej
daje 148.1 MHz zamiast 157.4 — czyli −6 %. To większy efekt niż sama wartość
pojemności, ale nadal nie rząd wielkości.

### Ile trzeba, żeby ring zwolnił do 50 MHz

`tb_ro_cload.cir` — częstotliwość w funkcji pojemności każdego węzła:

| C/węzeł | 0 | 1p | 5p | 10p | 20p | 47p | 100p | 150p |
|---|---|---|---|---|---|---|---|---|
| f [MHz] | 163.1 | 159.5 | 147.3 | 135.6 | 118.8 | 92.5 | 67.6 | 55.1 |

50 MHz wymaga **~180 pF na węzeł**. Przy 0.040 pF/mm to **4.5 metra ścieżki
na węzeł**. Pojemność ścieżek tego nie tłumaczy — i żadne dokładniejsze dane
o ich wymiarach tego nie zmienią.

`tb_ro_real.cir` — ta sama zależność od napięcia zasilania:

| VCC | 3.3 V | 2.6 V | 2.2 V | 1.8 V |
|---|---|---|---|---|
| f | 157.4 MHz | 103.4 MHz | 74.9 MHz | 48.6 MHz |

50 MHz odpowiada VCC ≈ **1.82 V**.

### Ograniczenie niezależne od mojego modelu

Karta katalogowa podaje t_pd = 2.0 ns (typ) przy **CL = 50 pF**. Obciążenie
węzła w ringu to ~5 pF, czyli 10× mniej, a opóźnienie rośnie monotonicznie z
obciążeniem. Zatem t_stage w ringu < 2.0 ns, więc **f > 1/(6·2.0 ns) = 83 MHz**.
To wynika wprost z karty, niezależnie od tego jak podzieliłem opóźnienie na
wewnętrzne i zależne od obciążenia.

Uczciwe zastrzeżenie: to rachunek na wartościach typowych. Limit *maksymalny*
t_pd to 4.5 ns (−40…+85 °C) i 6.0 ns (−40…+125 °C). Egzemplarz skrajnie wolny,
u którego opóźnienie jest w większości wewnętrzne, mógłby w teorii zejść w
okolice 50 MHz. Przy 25 °C i typowym egzemplarzu jest to jednak mało
prawdopodobne, i nie tłumaczyłoby, dlaczego wszystkie sześć ringów miałoby być
jednakowo wolne.

### Kandydaci na wyjaśnienie 3× i jak je rozstrzygnąć

| hipoteza | co by dała | jak sprawdzić |
|---|---|---|
| obciążenie sondą oscyloskopu | sonda 10:1 (~12 pF) na jednym węźle → ~143 MHz; sonda 1:1 (~100 pF) → ~93 MHz | zmierzyć sondą aktywną / porównać 10:1 z 1:1 |
| pasmo oscyloskopu < 157 MHz | licznik częstotliwości pokazuje bzdury, przebieg mocno stłumiony | sprawdzić pasmo toru; 157 MHz wymaga ≥500 MHz |
| mierzony inny węzeł | wyjście 74HC174 pracuje z zegarem próbkowania STM32, nie z częstotliwością ringu | sprawdzić, na którym punkcie była sonda |
| obniżone VCC | 1.82 V dałoby 50 MHz | zmierzyć VCC multimetrem na pinie 14 |
| egzemplarz skrajnie wolny | patrz wyżej | porównać kilka sztuk |

**Najlepszy test rozstrzygający — pomiar prądu, nie napięcia.** Prąd zasilania
ringu jest wprost proporcjonalny do częstotliwości (I = 3·C_eq·V_CC·f) i jest
zupełnie odporny na obciążenie sondą oraz na pasmo oscyloskopu:

| f rzeczywista | prąd 1 ringu | prąd 1 układu (2 ringi) | prąd 3 układów |
|---|---|---|---|
| 157 MHz | ~24 mA | ~48 mA | ~145 mA |
| 50 MHz | ~7.6 mA | ~15 mA | ~46 mA |

Wystarczy zwykły multimetr w trybie **napięcia** na ferrycie, albo miernik USB
w torze zasilania.

### Przeliczenie spadku na ferrycie na częstotliwość

BLM18AG102SN1D wg karty Murata: **R_DC = 0.50 Ω** (wartość początkowa; 0.60 Ω
przy 125 °C), prąd znamionowy **450 mA**.

Prąd ringu jest proporcjonalny do częstotliwości: 23.8 mA przy 157.4 MHz,
czyli **6.61 MHz na każdy 1 mA** prądu jednego ringu.

| mierzony ferryt | co prowadzi | wzór | 157 MHz | 50 MHz |
|---|---|---|---|---|
| FB3 / FB4 / FB5 | 1 układ = 2 ringi | **f[MHz] ≈ 6.6 · U[mV]** | 23.8 mV | 7.6 mV |
| FB2 | 3 układy = 6 ringów | **f[MHz] ≈ 2.2 · U[mV]** | 71.4 mV | 22.7 mV |
| FB1 | tylko VDDA STM32 | — | nie dotyczy ringów | |

### Tablica diagnostyczna VCC → f, prąd, spadek na ferrycie

`tb_ro_vcc_iv.cir` — jeden układ (2 ringi, geometria ścieżek jak U2), ferryt 0.50 Ω:

| VCC | f ringu | prąd układu | **spadek na FB3/4/5** |
|---|---|---|---|
| 3.30 V | 157.6 MHz | 49.4 mA | **24.7 mV** |
| 3.00 V | 133.9 MHz | 37.6 mA | 18.8 mV |
| 2.60 V | 103.6 MHz | 24.7 mA | 12.4 mV |
| 2.20 V | 75.0 MHz | 14.9 mA | 7.46 mV |
| 2.00 V | 61.5 MHz | 11.0 mA | 5.50 mV |
| **1.80 V** | **48.6 MHz** | 7.85 mA | **3.92 mV** |
| 1.60 V | 36.6 MHz | 5.30 mA | 2.65 mV |

**Pomiar na płytce (2026-08, FB4 / układ U2): 4.3 mV.** Interpolacja daje
VCC ≈ 1.85 V i f ≈ 51 MHz — co niezależnie zgadza się z odczytem
z oscyloskopu (~50 MHz). Dwa niezależne pomiary spełnione jednym parametrem.

Potwierdza to karta katalogowa (Tab.7): przy VCC 1.65–1.95 V t_pd(typ) = 3.7 ns
(zamiast 2.0 ns przy 3.3 V), co samo z siebie daje f > 1/(6·3.7 ns) = 45 MHz.

**AKTUALIZACJA — hipoteza niskiego VCC obalona pomiarem.** Zmierzone na płytce:
J3 pin 1 = 3.3 V, FB2 = 14.1 mV, FB4 = 4.3 mV. Czyli zasilanie jest sprawne
(spadek na całym torze to ~18 mV, VCC na U2 ≈ 3.28 V), a stosunek
FB2/FB4 = 3.28 przy oczekiwanym 3.0 potwierdza, że multimetr mierzy poprawnie
i nie prostuje RF. Wnioski poniżej — sekcja 4c.

**Zastrzeżenie do kolumny prądu przy niskim VCC:** model ma stałe pojemności,
a karta podaje C_PD zależne od napięcia — 9.9 pF przy 3.0–3.6 V, 7.1 pF przy
2.3–2.7 V, **3.9 pF przy 1.65–1.95 V**. Rzeczywisty prąd przy 1.8 V jest więc
niższy niż w tabeli (ok. 5 mA zamiast 7.85 mA), co przesuwa oszacowanie z
pomiaru prądu w górę, do VCC ≈ 2.1 V / f ≈ 66 MHz. Kolumna f jest tym
nieobciążona, bo opóźnienie jest zakotwiczone w t_pd z karty.
Wniosek zakresowy: **VCC ≈ 1.85–2.1 V, f ≈ 50–66 MHz.**

### Który ferryt jest gdzie (z pliku PCB)

Obrys ekranu RF (J1) obejmuje X 106.8–145.7, Y 52.1–78.3 mm. Stąd:

| element | pozycja (mm) | pod ekranem? |
|---|---|---|
| FB5 | 115.98, 56.10 — ~4 mm od U1 | **tak** |
| FB4 | 130.68, 55.80 — ~4 mm od U2 | **tak** |
| FB3 | 122.70, 67.85 — ~4 mm od U3 | **tak** |
| FB2 | 111.00, 75.10 | **tak** |
| **FB1** | **128.20, 95.00** | **NIE — dostępny** |
| U1 / U2 / U3 | 115.3,59.8 / 130.1,59.6 / 121.9,71.8 | tak |
| U6 (LDO), J2 (USB), J3 (Tag-Connect) | poza obrysem | nie |

**Uwaga: FB1 jest jedynym ferrytem dostępnym bez zdjęcia ekranu, a zasila
wyłącznie VDDA mikrokontrolera — z ringami nie ma nic wspólnego.** Pomiar na
nim nic nie mówi o częstotliwości oscylacji.

J3 (Tag-Connect) jest poza ekranem i ma pin 1 = VCC oraz piny 3/5/9 = GND,
więc napięcie szyny 3.3 V da się sprawdzić bez rozbierania płytki.

## 4c. Sprzeczność w danych katalogowych 74LVC04A — czy na płytce jest ten układ?

Stan pomiarów (sierpień 2026):

| wielkość | wartość |
|---|---|
| szyna 3.3 V (J3 pin 1) | 3.30 V — LDO reguluje poprawnie |
| spadek na FB2 (3 układy, 6 ringów) | 14.1 mV → **28.2 mA** |
| spadek na FB4 (U2, 2 ringi) | 4.3 mV → **8.6 mA**, czyli **4.3 mA/ring** |
| FB2 / FB4 | 3.28 (oczekiwane 3.0) — miernik wiarygodny |
| oscyloskop | ~50 MHz |

Prąd ringu wiąże się z częstotliwością wzorem z karty (Tab.7, przypis 4):
I = 3·(C_PD + C_L)·V_CC·f. Stąd zmierzona pojemność przełączana na bramkę:

| zakładane f | wynikające C_PD + C_L |
|---|---|
| 157 MHz | 2.8 pF |
| 50 MHz | 8.7 pF |
| **30 MHz** | **14.5 pF** |

Karta 74LVC04A podaje C_PD = 9.9 pF, a obciążeniem jest C_I = 4.0 pF następnej
bramki plus ~0.5 pF ścieżki, razem **14.4 pF**. Zmierzony prąd zgadza się z tą
wartością znakomicie — ale **tylko przy f ≈ 30 MHz**.

Tymczasem drugi parametr z tej samej karty, t_pd = 2.0 ns (typ) przy CL = 50 pF,
wyklucza f poniżej ~83 MHz dla ringu trójinwerterowego obciążonego ~5 pF
(patrz sekcja 4b). Nawet limit maksymalny 4.5 ns nie schodzi do 30 MHz przy tak
lekkim obciążeniu.

**Dwa parametry z tej samej karty nie mogą być jednocześnie prawdziwe dla tej
płytki.**

### Hipotezy sprawdzone i odrzucone

| hipoteza | jak sprawdzona | wynik |
|---|---|---|
| obniżone VCC na układzie | J3 = 3.30 V, spadki na FB2+FB4 = 18.4 mV | **odrzucona** — VCC na U2 ≈ 3.28 V |
| multimetr prostuje RF / kłamie | FB2/FB4 = 3.28 przy oczekiwanym 3.0 | **odrzucona** — miernik spójny |
| zamontowano inną rodzinę logiki | odczyt oznaczenia U1: **`LVC04A` / `C2515`** | **odrzucona** — to jest 74LVC04A |
| błędne R_DC ferrytu w moim przeliczeniu | karta/LCSC: **DCR 500 mΩ**, 450 mA, 1 kΩ@100 MHz | **odrzucona** — 0.50 Ω poprawne |
| pojemność ścieżek | geometria z PCB, 0.040 pF/mm | **odrzucona** — daje 1.6 % (sekcja 4b) |
| histereza wejścia (Schmitt) | slew ~3 V/ns, hipotetyczne 0.5 V histerezy → +1 ns/okres | **odrzucona** — daje ~136 MHz, nie 30 |

### Stan otwarty

Po odrzuceniu powyższych zostaje sprzeczność, której **nie potrafię rozstrzygnąć
bez jeszcze jednego pomiaru**:

- pomiar prądu (dwa niezależne ferryty, spójne ze sobą) → **f ≈ 30 MHz**
- t_pd z karty tego samego, potwierdzonego układu → **f ≥ 83 MHz**
- oscyloskop → **~50 MHz**
- symulacja zakotwiczona w t_pd i C_PD → **157 MHz**

Nie zgadują: jedna z tych liczb jest błędna i nie wiem która. Pomiary
rozstrzygające — patrz niżej.

### Pomiar rozstrzygający

**A. Całkowity prąd z USB** (miernik USB-C w torze). Omija R_DC i poziom
miliwoltów, sygnał jest rzędu setek mA:

| f rzeczywista | ringi | +74HC174 +STM32 | **razem z USB** |
|---|---|---|---|
| 157 MHz | 134 mA | ~45 mA | **~180 mA** |
| 30 MHz | 26 mA | ~21 mA | **~47 mA** |

**B. Amplituda na oscyloskopie.** Jeśli ring pracuje na 157 MHz, a tor pomiarowy
ma za małe pasmo, to obraz jest silnie stłumiony. Więc: czy na ekranie jest
zdrowy przebieg o amplitudzie bliskiej 0–3.3 V, czy mała sinusoida? Amplituda
bliska szyny = sygnał naprawdę jest na tej częstotliwości. Potrzebne też pasmo
oscyloskopu i typ sondy (10:1 / 1:1 / aktywna).

Orientacyjne dopasowanie rodzin przy 3.3 V (wartości przybliżone, nie
weryfikowałem tych kart katalogowych — do potwierdzenia po odczytaniu oznaczeń):

| rodzina | t_pd @3.3 V | f ringu | C_PD | przewidywany I/ring | pomiar 4.3 mA |
|---|---|---|---|---|---|
| 74LVC04A | ~1.4 ns | ~120–160 MHz | 9.9 pF | ~20–24 mA | ✗ 5× za dużo |
| **74AHC04** | **~5.3 ns** | **~31 MHz** | **~12 pF** | **~5.1 mA** | **✓ pasuje** |
| 74LV04A | ~9 ns | ~18 MHz | ~14 pF | ~3.4 mA | częściowo |
| 74HC04 | ~13 ns | ~13 MHz | ~21 pF | ~3.0 mA | f za niskie |

Wskazówka poszlakowa: schemat symulacyjny `ro-simu.kicad_sch` ma w polu Value
bramek wpisane **`74AHC1G04`**, a nie 74LVC04.

**Do zrobienia: odczytać oznaczenie na wierzchu U1/U2/U3** i dopiero wtedy
przeliczać. Po ustaleniu rodziny model trzeba przekalibrować (`calib_lvc04a.py`
robi to automatycznie po podmianie celów t_pd i C_PD).

### Co z wcześniejszymi wnioskami

| wniosek | czy przetrwa zmianę rodziny układu |
|---|---|
| rezonans 37 Ω @369 kHz na szynie | **tak** — to własność samej sieci pasywnej (ferryt + MLCC), niezależna od prędkości ringu |
| zalecenie 1 µF przy każdym układzie | **tak** — z tego samego powodu |
| ferryty per układ dają izolację | **tak** |
| **synchronizacja ringów w jednym układzie** | **wymaga ponownego sprawdzenia** — mechanizmem jest indukcyjność wspólnych pinów przy dużym di/dt; przy 30–50 MHz zamiast 157 MHz di/dt jest kilkukrotnie mniejsze, więc sprzężenie może być słabsze |
| dF/dVCC = 81.4 MHz/V | **nie** — do przeliczenia dla właściwej rodziny |

## 4d. Konfrontacja z pomiarami entropii (`entopy_tests/summary.md`)

### Potwierdzone: przypisanie ringów do obudów

`summary.md` §6 zostawia to jako hipotezę („the gate-to-ring assignment in the
schematic was not verified"). Prześledziłem cały łańcuch z netlisty:

ring → `/Dx` → 74HC174 (U4) → rezystor 47 Ω (R6–R11) → pin STM32 → kanał.

| U4 D→Q | sieć | R | pin U5 | port | **kanał** |
|---|---|---|---|---|---|
| D1(3)→Q1(2) | /D0 | R11 | 13 | PA7 | **F** |
| D2(4)→Q2(5) | /D1 | R10 | 10 | PA4 | **E** |
| D3(6)→Q3(7) | /D2 | R9 | 9 | PA3 | **D** |
| D4(11)→Q4(10) | /D3 | R8 | 8 | PA2 | **C** |
| D5(13)→Q5(12) | /D4 | R7 | 7 | PA1 | **B** |
| D6(14)→Q6(15) | /D5 | R6 | 6 | PA0 | **A** |

Mapowanie jest **odwrócone**: A=/D5, B=/D4, C=/D3, D=/D2, E=/D1, F=/D0.
Łącząc to z przypisaniem ringów do obudów (sekcja 4 tego dokumentu):

| obudowa | ringi | **kanały** |
|---|---|---|
| U1 | /D2, /D3 | **C, D** |
| U2 | /D0, /D1 | **E, F** |
| U3 | /D4, /D5 | **A, B** |

Pary z jednej obudowy to więc **{A,B}, {C,D}, {E,F}** — dokładnie te trzy pary,
które `summary.md` wskazuje jako konsekwentnie istotne na 60, 80 i 100 kHz.
**Caveat #2 z §10 można zamknąć.** Uwaga: sam podział na pary był odgadnięty
poprawnie, ale przypisanie do obudów nie — jest U3={A,B}, U1={C,D}, U2={E,F},
a nie U1={A,B}, U2={C,D}, U3={E,F}.

### Obalone: moja teza o synchronizacji ringów

Symulacja (sekcja 4) przewidywała, że ringi w jednej obudowie **wciągają się**:
własna różnica częstotliwości 710 kHz zapadała się do 1 kHz. Gdyby tak było,
skorelowanie próbek obu kanałów byłoby bliskie 1.

Pomiar mówi: **r = 0.013…0.029**, informacja wzajemna 0.0001…0.0004 bit/próbkę,
łącznie 0.13 % budżetu entropii.

To jest sprzężenie **realne i dokładnie w przewidzianych parach, ale o dwa rzędy
wielkości słabsze niż wciąganie.** Wniosek: przyjęte pasożyty obudowy
(lpin 2.5 nH, cdie 100 pF, rrail 0.4 Ω) są zbyt pesymistyczne — i/lub ringi
pracują wolniej, przez co di/dt jest kilkukrotnie mniejsze. **Zmierzone r jest
teraz celem kalibracyjnym** dla tych parametrów, zamiast zgadywania.

### Wskazówka, której nie umiałem odczytać z samego schematu: opóźnienie sprzężenia

`summary.md` §6 podaje, że najsilniejsza korelacja występuje nie przy lag 0,
tylko przy **lag +2 lub −1**, co przy 100 kHz oznacza **10–20 µs**.

Sprzężenie przez szynę zasilania jest podnanosekundowe — miałoby maksimum przy
lag 0. Skala 10–20 µs wskazuje na **inny mechanizm, którego w modelu nie ma**:

| kandydat | skala czasowa | czy jest w modelu |
|---|---|---|
| sprzężenie cieplne na wspólnym krzemie | µs–ms | **nie** |
| pętla regulacji LDO (~200 kHz) | ~5 µs | tak (tylko w analizie AC) |
| rezonans ferryt+MLCC 369 kHz | 2.7 µs | tak |

Dodatkowo widać różnicę strukturalną: pary z jednej obudowy (A-B, C-D, E-F) mają
korelację **dodatnią**, a pary międzyobudowowe (A-F: A∈U3, F∈U2; D-E: D∈U1, E∈U2)
**ujemną** przy lag +2. Zmiana znaku to sygnatura sprzężenia przez sieć
rezonansową, a nie przez proste opóźnienie.

### Entropia jako niezależne oszacowanie częstotliwości ringu (słabe)

Estymator t-Tuple znajduje powtórzenia ciągów o długości **t = 148–214 próbek** —
to w przybliżeniu długość dekorelacji fazy ringu. Dla fazy błądzącej losowo
dekorelacja następuje po n ≈ 1/x² próbek, gdzie x to jitter narosły między
próbkami wyrażony w okresach ringu. Z n ≈ 180 wychodzi **x ≈ 0.075**.

Ponieważ x = ε·√(f_ring/f_s), gdzie ε = σ_T/T (względny jitter okresu):

| f_ring | wynikające ε | σ_T |
|---|---|---|
| 157 MHz | 1.9·10⁻³ | 12 ps |
| 50 MHz | 3.3·10⁻³ | 66 ps |
| 30 MHz | 4.3·10⁻³ | 143 ps |

Typowy ring CMOS ma ε rzędu 10⁻⁴…10⁻³, co **łagodnie przemawia za wyższą
częstotliwością**. Ale to słaba przesłanka: przy dF/dVCC = 81 MHz/V większość
jitteru w tym układzie pochodzi z zasilania, nie z szumu termicznego, a to
podnosi ε o nieznany czynnik. Nie rozstrzyga sporu z sekcji 4c.

### Najważniejszy wniosek dla jakości źródła

dF/dVCC = 81.4 MHz/V oznacza, że **1 mV szumu na VCC daje 81 kHz dewiacji**.
Jitter tego ringu jest więc w dużej mierze **napędzany zasilaniem, nie termiczny**.
To ma bezpośrednie konsekwencje dla TRNG:

- szum z zasilania jest **wspólny dla wszystkich ringów na tej samej szynie**,
  więc wnosi entropię **skorelowaną**, a nie niezależną — czyli sumowanie
  budżetów per kanał (§7 summary) jest tym bardziej ryzykowne
- rezonans **37 Ω @ 369 kHz** to impedancja **wspólna**: wszystko, co ją pobudzi,
  moduluje wszystkie ringi jednocześnie i spójnie
- jest to również punkt wstrzyknięcia dla atakującego — modulacja zasilania w
  okolicy 369 kHz ma tam 30× większą skuteczność niż gdzie indziej

To wzmacnia rekomendację z sekcji 7 (dołożyć 1 µF przy każdym układzie) o
argument, który nie wynikał z samej analizy sieci: chodzi nie tylko o czystość
zasilania, ale o **rozkorelowanie źródeł entropii**.

### Co dodać do symulacji

| # | co | po co |
|---|---|---|
| 1 | źródła szumu (termiczny w MOSFET-ach + wstrzykiwany szum zasilania) | bez nich model nie policzy jitteru ani entropii — dziś przewiduje tylko jitter deterministyczny |
| 2 | kalibracja pasożytów obudowy do zmierzonego r ≈ 0.02 | zastępuje zgadywanie lpin/cdie twardym celem liczbowym |
| 3 | model sprzężenia cieplnego na krzemie | jedyny kandydat na obserwowane maksimum przy 10–20 µs |
| 4 | próbkowanie wyników symulacji przy 100 kHz i liczenie tego samego r Pearsona | daje wielkość bezpośrednio porównywalną z `channel_crosstalk_rev1.py` |
| 5 | model fazowy (behawioralny) zamiast pełnego SPICE do statystyki | SPICE nie policzy 1.4 mln próbek; SPICE → dF/dVCC i transmitancje sprzężeń, potem Monte Carlo w Pythonie |
| 6 | zakres temperatury i napięcia | caveat #6 z summary; dF/dVCC już jest, brakuje temperatury |

## 4e. Rekomendacje dla Rev-2

### Q1. Filtr przy układach

Kluczowa obserwacja: **obecny filtr działa w złym paśmie.** Sprzężenie między
układami w funkcji częstotliwości (K12, mniej = lepiej):

| wariant | 10 kHz | 50 kHz | 100 kHz | 369 kHz | 1 MHz | 157 MHz | Z_max | spadek DC¹ |
|---|---|---|---|---|---|---|---|---|
| **as-built** (ferryt+100n+2n2) | **−4.5** | **−2.1** | −13.4 | −19.6 | −74.8 | −136.2 | 43.0 Ω @369k | 4 mV |
| +1 µF | −4.4 | −2.8 | −10.5 | −30.9 | −56.6 | −138.6 | 4.4 Ω @122k | 4 mV |
| 22 Ω zamiast ferrytu | −29.4 | −33.5 | −42.7 | −64.3 | −84.2 | −67.3 | 22.6 Ω @13k | 189 mV |
| R=22 Ω + 10 µF | −48.4 | −64.6 | −77.2 | −101.3 | −124.5 | −69.3 | 0.54 Ω | 189 mV |
| **ferryt + R=22 Ω + 10 µF** | **−48.8** | **−65.0** | **−77.6** | **−102.2** | **−127.7** | **−138.6** | **0.55 Ω** | 189 mV |
| bez filtru per układ | −0.1 | 0.0 | 0.0 | 0.9 | −1.4 | −38.7 | 1.2 Ω | 0 |

¹ przy zmierzonym prądzie 8.6 mA na układ

Ferryt daje −136 dB przy 157 MHz, gdzie sprzężenie i tak nie ma znaczenia, i
**praktycznie nic w paśmie 10–50 kHz** — czyli dokładnie tam, gdzie leży
zmierzone opóźnienie korelacji 10–20 µs (sekcja 4d). Powód jest prosty: przy
50 kHz ferryt to tylko swoje 0.5 Ω rezystancji DC.

**Zalecenie: ferryt + rezystor szeregowy + kondensator masowy.**

```
VCCQ ──[ BLM18AG102SN1D ]──[ R 22R 0402 ]──┬── VCC układu (pin 14)
                                           │
                              10 µF 0805 ──┼── 100 nF 0402 ── 2.2 nF 0402
                                           │   (wszystko przy pinach 14/7)
                                          GND
```

Zysk wobec obecnej płytki: **+44 dB przy 10 kHz, +63 dB przy 50 kHz, +83 dB przy
369 kHz**, rezonans 43 Ω znika (Z_max 0.55 Ω), a izolacja RF zostaje bez zmian.

**Dobór R zależy od nierozstrzygniętego sporu o prąd (sekcja 4c):**

| prąd na układ | R = 22 Ω | R = 10 Ω | R = 4.7 Ω |
|---|---|---|---|
| 8.6 mA (zmierzony) | 189 mV ✓ | 86 mV ✓ | 40 mV ✓ |
| 48 mA (symulowany) | 1.06 V ✗ | 480 mV ✗ | 226 mV ~ |

Dlatego: przewidzieć footprint 0402 i **dobrać R po zmierzeniu prądu**. Przy
jednym ringu na obudowę prąd na obudowę spada o połowę, co dodatkowo ułatwia
sprawę. Alternatywa bez tego kompromisu: mały LDO per układ.

### Q2. Szerokość ścieżek w ringach

**Szerokość jest praktycznie bez znaczenia. Znaczenie ma odstęp i długość.**

Pojemność ścieżki na tym stackupie to 0.040 pF/mm (sekcja 4b) — cała pojemność
ścieżek zmienia częstotliwość o 1.6 %. Zwężenie ścieżki obniżyłoby ją jeszcze
mniej, a **podniosłoby Z₀** (już teraz 142 Ω), czyli zwiększyło podatność węzła
na przesłuch. Zwężanie nic nie daje, a lekko szkodzi.

Realny problem znaleziony w PCB: **ścieżki różnych ringów biegną zbyt blisko.**

| para ringów | najmniejszy odstęp | równoległy bieg <1 mm | <2 mm |
|---|---|---|---|
| U2: /D0 ↔ /D1 (kanały F↔E) | **0.65 mm** | 1.1 mm | 6.2 mm |
| U3: /D4 ↔ /D5 (kanały B↔A) | **0.65 mm** | 1.8 mm | 3.7 mm |
| U1: /D2 ↔ /D3 (kanały D↔C) | 1.60 mm | 0.0 mm | 2.3 mm |
| U1 ↔ U2 (/D2 ↔ /D1) | 1.30 mm | 0.0 mm | 6.1 mm |

Na płytce dwuwarstwowej 1.6 mm płaszczyzna masy jest **daleko**, więc ścieżki
sprzęgają się ze sobą mocniej niż z masą. Kryterium to odstęp względem wysokości
nad masą: sprzężenie robi się małe dopiero przy s > 2h = **3.2 mm**. Płytka ma
0.65 mm, czyli **5× za blisko**.

To jest drugi, niezależny kanał sprzężenia, którego w modelu nie było — obok
wspólnych pinów zasilania. Zgodność poszlakowa: para A-B (U3) ma najdłuższy
bieg poniżej 1 mm (1.8 mm) **i** najwyższą zmierzoną korelację (0.0292).

**Zalecenia:**
1. **Płytka 4-warstwowa** z masą 0.2 mm pod warstwą sygnałową. To jedna zmiana,
   która naprawia jednocześnie przesłuch (h spada 8×) i całą sieć zasilania.
2. Odstęp między ścieżkami różnych ringów **≥ 2h**; przy 4 warstwach i h=0.2 mm
   wystarczy 0.4 mm, więc jest to łatwiejsze niż teraz.
3. Ścieżka masy (guard) między sąsiadującymi ringami, przeszyta przelotkami.
4. **Skrócić** nety /Dx (dziś 12–21 mm) — to one biegną równolegle.
5. Nie zwężać ścieżek.

### Q3. Separacja galwaniczna

Ile szumu z USB dociera dziś do zasilania ringów:

| tłumienie 5 V → VCC układu | 1 kHz | 10 kHz | 50 kHz | 100 kHz | 369 kHz | 1 MHz |
|---|---|---|---|---|---|---|
| as-built | −60.5 | **−42.8** | **−42.8** | −49.2 | −60.5 | −146.0 |
| z filtrem z Q1 | −63.2 | −62.4 | −75.5 | −88.3 | −129.8 | −193.2 |

Przy dF/dVCC = 81.4 MHz/V: dziś 100 mV tętnienia USB przy 50 kHz daje 0.7 mV na
VCC ringu, czyli **57 kHz dewiacji**. Z filtrem z Q1 — 6.5 kHz.

**Sam filtr z Q1 daje 20–33 dB, czyli większość tego, co dałaby separacja — bez
przetwornicy.**

Bilans separacji galwanicznej:

| za | przeciw |
|---|---|
| usuwa szum hosta i pętle masy | izolowana przetwornica DC-DC ma własne tętnienie 20–100 mV przy 100 kHz–1 MHz, czyli **dokładnie w paśmie, gdzie PSRR LDO jest najsłabszy, a obecny filtr nie działa** |
| odcina drogę ataku przez zasilanie USB | pojemność międzyuzwojeniowa transformatora (5–20 pF) i tak przepuszcza RF, więc sama separacja nie zatrzymuje wycieku fazy ringów na kabel |
| ogranicza wyjście RF ringów na kabel | koszt, miejsce, złożoność, izolowany USB ogranicza do Full Speed |

**Werdykt: to funkcja bezpieczeństwa, nie jakości entropii.** Wprowadzona
naiwnie — przetwornica bez dobrego filtra po niej — **pogorszy** jakość źródła,
bo wstrzyknie tętnienie w najgorsze możliwe pasmo. Dla Rev-2 pieniądze lepiej
wydać na: jeden ring na obudowę, filtr z Q1, 4 warstwy.

Jeśli model zagrożeń obejmuje atakującego kontrolującego zasilanie USB, to
separacja ma sens — ale dopiero **na wierzchu** poprawionego filtra i w
kolejności: izolowana DC-DC → filtr LC → LDO → filtr RC per układ. Dodatkowo
dławik wspólny i ekranowanie, bo inaczej RF wychodzi przez pojemność
transformatora.

### Kolejność prac dla Rev-2

| # | zmiana | zysk |
|---|---|---|
| 1 | jeden ring na obudowę (74LVC1G04, SOT-353) | usuwa sprzężenie wewnątrz obudowy, którego żaden filtr nie sięga |
| 2 | płytka 4-warstwowa z bliską masą | naprawia przesłuch ścieżek i sieć zasilania naraz |
| 3 | filtr ferryt + R + 10 µF per układ | +44…+83 dB izolacji, likwiduje rezonans 43 Ω |
| 4 | odstęp ≥2h między ringami, krótsze nety /Dx | drugi kanał sprzężenia |
| 5 | separacja galwaniczna | tylko jeśli wymaga tego model zagrożeń |

## 5. Zastrzeżenia do wyników

Rzeczy, które trzeba wiedzieć, żeby nie przecenić tych liczb:

1. **Bezwzględne częstotliwości w tabeli sprzężenia (193 / 148 / 176 MHz) nie
   są wartościami ustalonymi.** Symulacja trwa 1.2 µs, a rezonans sieci przy
   369 kHz ma okres 2.7 µs i wysoką dobroć — szyna wciąż dzwoni po starcie.
   Dlatego średnie napięcie na szynie krzemowej wychodzi 3.13–3.75 V zależnie od
   przypadku i to ono przesuwa częstotliwość. **Miarodajne jest porównanie Δf
   między przypadkami**, nie wartości bezwzględne. Rzetelne f ustalone dają
   `tb_ro_single.cir` (159.5 MHz) i `tb_ro_detune.cir`.
2. **Pasożyty obudowy TSSOP-14 (2.5 nH na pin, 100 pF na krzemie, 0.4 Ω szyny)
   to założenia inżynierskie, nie dane katalogowe** — Nexperia ich nie podaje.
   Bezwzględna amplituda tętnienia na krzemie zależy od nich wprost. Dlatego
   powyżej jest test odporności z 10× lepszymi wartościami.
3. **Model nie ma histerezy wejścia.** Karta wymienia „Schmitt-trigger action at
   all inputs", ale nie podaje wartości dla 74LVC04A. Histereza podnosi okres
   oscylacji, więc jeśli pomiar na płytce da częstotliwość niższą niż 159.5 MHz,
   to pierwszy kandydat na przyczynę (obok pojemności ścieżek).
4. **Model ferrytu jest liniowy** — nie odwzorowuje spadku indukcyjności przy
   podmagnesowaniu prądem DC. Prąd znamionowy BLM18AG102SN1D to 450 mA, a
   najbardziej obciążony ferryt (FB2, ~145 mA) pracuje przy ~32 % tej wartości,
   więc model nominalny jest tu uzasadniony. R_DC = 0.50 Ω (wartość początkowa
   wg karty Murata), nie 0.6 Ω jak zakładałem wstępnie.
5. **W transiencie LDO zastąpiony idealnym źródłem** z 23 mΩ + 2 nH. Pełny model
   AP2112 jest użyty w analizie AC. Powód: nieliniowości modelu (`min()`, dioda
   podłożowa) rozbijały zbieżność przy krokach 2 ps, a powyżej ~260 kHz LDO i
   tak nie wnosi nic poza kondensatorem wyjściowym.
6. **Brak źródeł szumu** — w modelu nie ma szumu termicznego ani migotania.
   Kolumna „jitter" w `ro_coupling.py` to więc rozrzut *deterministyczny*,
   wnoszony wyłącznie przez zaburzenia zasilania. Prawdziwej entropii ringu ta
   symulacja nie liczy.

---

## 6. Co poprawić w projekcie KiCad

Schemat `ro-simu.kicad_sch` był w trakcie tej pracy otwarty w KiCadzie, więc go
nie ruszałem. Do poprawienia ręcznie:

1. **Nazwa podobwodu LDO.** Pole `Sim.Name` ma wartość `AP2112K-3.3`.
   **ngspice nie potrafi zinstancjonować podobwodu, którego nazwa zawiera
   `-3.3`** — parsuje to jako liczbę i zgłasza `unknown subckt`. Czyli LDO w tym
   projekcie nigdy się nie symulował. Zmienić na `AP2112K_33`, a
   `Sim.Library` na `spice/models/AP2112K.lib`.
2. **Literówka w warunkach początkowych.** Dyrektywa brzmi
   `.ic V(/d1)=0 V(/d3)=3.3`, a węzeł `/d3` nie istnieje — punkty pomiarowe to
   `/D1` i `/D2`. Drugi ring nie dostaje warunku startowego. Powinno być
   `.ic V(/D1)=0 V(/D2)=3.3`.
3. **Ferryty.** L1/L2/L3 = 100 nH + R = 0.1 Ω to zastępnik za
   BLM18AG102SN1D. Podmienić na model z `models/passives.lib` — inaczej symulacja
   nie pokaże rezonansu 369 kHz.
4. **Kondensatory** są modelowane jako idealne. Bez ESL nie widać, że przy
   159 MHz o skuteczności odsprzęgania decyduje indukcyjność montażu, a nie
   pojemność.
5. **Topologia nie odpowiada płytce.** Schemat daje każdemu ringowi własną sieć
   VCC, czyli modeluje ringi w osobnych układach. Na płytce dwa ringi dzielą
   jeden układ hex. To różnica między Δf = 804 kHz a Δf = 1 kHz — czyli między
   dwoma niezależnymi źródłami entropii a jednym.
6. Pole `Value` bramek to `74AHC1G04`, a symulowany jest 74LVC04A. Warto
   ujednolicić, żeby schemat nie mylił.

---

## 7. Podsumowanie rekomendacji

| priorytet | działanie | efekt |
|---|---|---|
| 1 | Rozdzielić ringi na osobne obudowy (74LVC1G04) | usuwa synchronizację ringów — jedyna rzecz, której nie da się naprawić filtrem |
| 2 | Dodać 1 µF przy każdym układzie | rezonans szyny 37 Ω → 3.9 Ω, Z@159MHz 0.46 → 0.35 Ω |
| 3 | Zostawić ferryty per układ | izolacja między układami −143 dB; bez nich −46 dB |
| 4 | Nie zastępować ferrytów rezystorami | 10 Ω = 0.48 V spadku DC przy 48 mA |
| 5 | Poprawić projekt symulacji (pkt 6) | inaczej symulacja nie pokazuje realnych problemów |

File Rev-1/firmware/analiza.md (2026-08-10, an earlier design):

# Analiza czasowa firmware TRNG (Rev-1)

Pytanie wyjściowe: **czy przy multiplikacji bufora = 4 (komenda `'4'` po USB) stałe czasowe są wystarczające, aby wysłać bufor po USB, zanim zapełni się on nowymi danymi — i czy okno między napełnianiem bufora a `SHA256 + USB send` się wyrabia?**

Analiza dotyczy stanu kodu z commita `022efae` ("firmware v1, WIP"). Wszystkie liczby cyklowe pochodzą z disasemblacji `Release/trng.elf` (build zgodny z sourcem, `-Oz`, gcc 14.3, Cortex-M0 @ 48 MHz), model cyklowy: `ldr`/`str` = 2, branch taken = 3, `bl` = 4, wejście/wyjście z wyjątku = 16/12.

---

## 1. Podsumowanie

**Blokada nadrzędna:** TIM14 nigdy nie jest uruchamiany — `HAL_TIM_Base_Start_IT()` nie występuje w kodzie (`main.c:181` woła tylko `HAL_TIM_Base_Init`, a `TIM_Base_SetConfig` nie ustawia ani `CR1.CEN`, ani `DIER.UIE`). W obecnym buildzie `TIM14_IRQHandler` nie odpala się nigdy, więc żadna entropia nie jest zbierana. Cała analiza poniżej zakłada, że start timera zostanie dodany.

**Odpowiedź na pytanie:** dla m=4 nominalnie się wyrabia, ale margines na transakcję USB to ~1,09 ms, czyli dokładnie jedna ramka USB FS — zero realnego zapasu. W wariancie pesymistycznym okno się nie domyka. Dominującym kosztem nie jest SHA-256, a przerwanie próbkujące 80 kHz, które zjada 54% CPU.

---

## 2. Zmierzone stałe czasowe

| Element | Cykle | Czas |
|---|---|---|
| Okres TIM14 (ARR=599, presc=0, APB1=48 MHz) | 600 | 12,5 µs (80 kHz) |
| Wejście/wyjście z IRQ + wrapper `TIM14_IRQHandler` | ~58 | 1,2 µs |
| `collectEntropyBits` (w tym pętla `select_data` ~99 cyk) | ~197 | 4,1 µs |
| `HAL_TIM_IRQHandler` (ścieżka UIF: 8 testów flag + weak callback) | ~72 | 1,5 µs |
| **ISR razem** | **~327** | **6,8 µs** |
| `compress()` — 1 blok 64 B: 16×117 + 48×157 + 123 | ~9 500 | 198 µs |
| `tc_sha256_update` — pętla bajtowa | 22 / bajt | — |

**ISR zjada 327/600 = 54% CPU.** Na pętlę główną zostaje ~45%; przy `FLASH_LATENCY_1` i karze za pobrania po skokach realnie 33–40%. To, a nie SHA, jest głównym czynnikiem.

Weryfikacja `compress()`: 9500 cykli / 64 B = 148 cykli/bajt, co jest zgodne z publikowanymi pomiarami tinycrypt/mbedTLS SHA-256 w czystym C na Cortex-M0 (130–200 cykli/bajt).

---

## 3. Budżet dla multiplikacji = 4

Bufor 128 B = 1024 bity. Maska domyślna daje **5 bitów na próbkę** (patrz błąd nr 2 w sekcji 5), więc:

- **Okno napełniania: 205 próbek × 12,5 µs = 2,56 ms**
- SHA-256 nad 128 B = 3 wywołania `compress` (2 z `update`, 1 z `final`) + pętla bajtowa ≈ **32 000 cykli CPU = 0,67 ms czystego czasu procesora**
- Czas zegarowy przy ISR kradnącym CPU: **32 000 / 0,45 ≈ 1,47 ms** (pesymistycznie, przy 1 WS flash: **2,2–2,3 ms**)
- `CDC_Transmit_FS` jest wołane synchronicznie w `sendEntropyToHost`, więc kolejkowanie kosztuje ~40 µs — pomijalne

**Zapas na transakcję USB: 2,56 − 1,47 = ~1,09 ms nominalnie, ~0,3 ms pesymistycznie.**

Worst-case latencja bulk IN to jedna ramka USB FS = **1 ms** (host odpytuje endpoint, gdy ma zakolejkowane URB-y; przy chwilowym braku — cała ramka). Czyli:

> **Nominalnie się wyrabia, ale margines to ~1 ramka USB.** W wariancie pesymistycznym (kara flash, 6 kanałów włączonych, zbieg z długim `HAL_PCD_IRQHandler`) okno się **nie** domyka. Dodatkowo nie ma żadnego backpressure: jeśli host się spóźni, `sendEntropyToHost` trafia w `else` → `blinkFast(99)` i blok **jest po cichu gubiony** (`sender.c:43`).

### Pozostałe multiplikacje

| m | okno | SHA (wall) | zapas na USB | ocena |
|---|---|---|---|---|
| 1 | 0,64 ms | 0,50 ms | 0,14 ms | ❌ okno < 1 ramki USB |
| 2 | 1,28 ms | 0,97 ms | 0,31 ms | ❌ |
| 3 | 1,92 ms | 1,00 ms | 0,92 ms | ⚠️ granicznie |
| **4** | **2,56 ms** | **1,47 ms** | **1,09 ms** | ⚠️ granicznie |
| 5 | 3,20 ms | 1,50 ms | 1,70 ms | ✅ |
| 6 | 3,84 ms | 1,97 ms | 1,87 ms | ✅ |
| 8 | 5,12 ms | 2,47 ms | 2,65 ms | ✅ |
| 9 | 5,76 ms | 2,50 ms | 3,26 ms | ✅ |

Liczba wywołań `compress` per m (`floor(32m/64)` z `update` + 1 z `final`): m=1→1, m=2→2, m=3→2, m=4→3, m=5→3, m=6→4, m=7→4, m=8→5, m=9→5. Stąd niemonotoniczność zapasu.

**Tryb RAW (`'r'`) jest strukturalnie nie do wyrobienia** — okno 0,64 ms przy oknie USB 1 ms; będzie stale gubił bloki i mrugał błędem 99.

---

## 4. Architektura przepływu (dla kontekstu)

```
TIM14 @80 kHz (prio 0)
  └─ TIM14_IRQHandler          stm32f0xx_it.c:149
       ├─ latch PA5 low/high, odczyt GPIOA->IDR
       └─ collectEntropyBits   entropy_collector.c:160
            ├─ select_data           (bit-gather po masce kanałów)
            └─ copyEntropyBitsToBuffer
                 └─ [bufor pełny] buffer_to_process = ...; swapInputBuffer()

pętla główna (main.c:102)
  ├─ updateCollector           entropy_collector.c:153
  │    └─ [buffer_to_process != NULL] processEntropyBlock()
  │         ├─ RAW:  sendEntropyToHost(buffer_to_process, 32)
  │         └─ SHA:  init/update/final → sendEntropyToHost(digest, 32)
  ├─ updateSender              sender.c:25
  └─ ledUpdate

USB (prio 0)
  └─ CDC_Receive_FS            usbd_cdc_if.c:261  ('a'-'f','A'-'F','1'-'9','r','R')
       └─ useRO / setBufferMultiplicity / useRawEntropy → save_config() [!]
```

Podwójne buforowanie (`raw_entropy_block` / `raw_entropy_block2`) jest poprawne: ISR napełnia jeden bufor, pętla główna liczy SHA na drugim. Realnym deadline'em jest więc **jedno pełne okno napełniania** (640·m µs), a nie jakiś krótszy odcinek.

`updateCollector` przeładowuje `buffer_to_process` przy każdym wywołaniu (`0x8000362`), więc nie jest wyoptymalizowane do hoistingu poza pętlę — patrz jednak błąd nr 6.

---

## 5. Błędy wpływające na tę analizę

1. **`main.c` — brak `HAL_TIM_Base_Start_IT(&htim14)`.** Blocker; bez tego nic nie działa.

2. **`entropy_collector.c:90` — `select_data` iteruje `i < 6`, ale kanał 5 ma maskę `0b10000000`** (`entropy_collector.c:63`, PA7 — bo bit 5 to PA5/latch). Kanał PA7 nigdy nie trafia do bufora: komenda `'f'` tylko kasuje flash i mruga. Maska domyślna `0b10011111` daje więc 5, nie 6 bitów na próbkę. Fix: `i < 8` w pętli.

3. **`flash_storage.c` wołany z kontekstu USB IRQ** (`CDC_Receive_FS` → `useRO`/`setBufferMultiplicity` → `save_config`). Erase strony na F0 to ~20–40 ms busy-waitu. `USB_IRQn` i `TIM14_IRQn` mają obie priorytet 0 (`trng.ioc:49-50`), więc na czas erase zbieranie entropii jest całkowicie zatrzymane, a SysTick (prio 3) nie tyka → `HAL_GetTick()` stoi i timeouty we `FLASH_WaitForLastOperation` nie działają. Przenieść zapis do pętli głównej (flaga „dirty”).

4. **`setBufferMultiplicity` (`entropy_collector.c:78`) nie woła `swapInputBuffer()`** (w odróżnieniu od `useRO`). Przy zwiększaniu bufora bajty powyżej starego rozmiaru nie były wyzerowane (`swapInputBuffer` memsetuje tylko `selected_entropy_buffor_size`), a `copyEntropyBitsToBuffer` robi `|=` — pierwszy blok po zmianie miesza się ze starymi danymi. Przy zmniejszaniu następuje przedwczesny flush częściowego bufora. Fix: memset zawsze `MAX_ENTROPY_BLOCK_SIZE` i wołać `swapInputBuffer()` również tutaj.

5. **`swapInputBuffer()` wołane z USB IRQ ściga się z pętlą główną** — może przełączyć się na bufor, na który wciąż wskazuje `buffer_to_process`, i wymemsetować go w trakcie liczenia SHA. Przy resecie trzeba czyścić też `buffer_to_process`.

6. **`buffer_to_process` / `raw_entropy_bit_index` nie są `volatile`** przy wymianie ISR↔main. Aktualnie działa (`updateCollector` nie jest inline'owany), ale to przypadek, nie gwarancja.

7. **Utrata bitów na granicy bufora:** gdy `remaining_space < data_bits_count`, nadwyżkowe bity są odrzucane, a `raw_entropy_bit_index` mimo to jest inkrementowany o `bits_to_write_count`. Do 5 bitów entropii tracone raz na bufor — kosmetyka, nie błąd bezpieczeństwa.

8. **`start_blink` (`haptic.c:32`)** porównuje `mode == BLINK_MODE_FAST_OFF`, podczas gdy `blinkFast`/`blinkSlow` przekazują `BLINK_MODE_FAST_OFF`/`BLINK_MODE_SLOW_OFF` — gałąź `default` ustawia tryb i wychodzi bez skonfigurowania `blink_interval`. Poboczne wobec analizy czasowej, ale warto poprawić, skoro błąd 99 jest jedynym kanałem diagnostycznym.

---

## 6. Rekomendacje

Największy zwrot ma odchudzenie ISR — to on zabiera połowę CPU.

1. **Wyrzucić `HAL_TIM_IRQHandler` z ISR** i zrobić `TIM14->SR = 0;` — ~72 cykle mniej za darmo.
2. **Zamienić pętlę `select_data` na LUT** — ~99 cykli mniej (szczegóły w sekcji 7).
3. Po (1)+(2): ISR ~148 cykli = 25% CPU, dla m=4 SHA spada do ~0,89 ms, zapas rośnie do ~1,24 ms i przestaje być wrażliwy na karę flasha.
4. **Alternatywnie/dodatkowo: zejść z 80 kHz na 40 kHz** (ARR=1199). ISR to wtedy 27% CPU, okno rośnie do 5,12 ms, SHA do 0,92 ms → zapas 4,2 ms. Kosztem połowy przepustowości (6,25 kB/s zamiast 12,5 kB/s przy m=4). Przy 80 kHz i tak warto sprawdzić, czy próbkowanie nie jest szybsze niż czas dekorelacji ringów.
5. **Dodać FIFO 2–4 bloków 32-bajtowych między SHA a USB.** To usuwa wrażliwość na latencję ramki USB całkowicie — liczy się wtedy tylko średnia przepustowość (12,5 kB/s przy m=4, bez problemu dla bulk FS), a nie czas pojedynczej transakcji. Obecnie `sendEntropyToHost` gubi blok, zamiast go zakolejkować. **LUT tego nie zastępuje** — LUT kupuje zapas w budżecie CPU, FIFO kupuje odporność na hosta.
6. Rozważyć `USB_IRQn` na priorytecie 1, żeby długie obsługi kontrolne nie opóźniały próbkowania (albo odwrotnie — TIM14 wyżej, jeśli ważniejsza jest regularność próbkowania).
7. Przenieść `save_config` i rebuild LUT z ISR USB do pętli głównej.

---

## 7. Szczegóły: `select_data` → LUT

### 7.1 Co robi ta pętla

`select_data` (`entropy_collector.c:86`) to **bit-gather** (odpowiednik `PEXT` z BMI2): bierze surowy bajt z `GPIOA->IDR` i upakowuje w ciągłe niskie bity tylko te pozycje, które są ustawione w masce `selected_ro_channels`.

```
maska  = 0b00011111        (PA0..PA4 aktywne)
IDR    = 0b?_?_1_0_1_1_0   → wynik = 0b01011, bits = 5
```

Kosztuje tyle, bo robi to **bit po bicie w runtime**, choć maska jest stała między komendami z USB. Z disasemblacji (`0x80003be`–`0x80003de`), koszt jednej iteracji:

| przypadek | cykle |
|---|---|
| kanał włączony, bit = 1 | 19 |
| kanał włączony, bit = 0 | 17 |
| kanał wyłączony | 11 |

Przy masce domyślnej (5 aktywnych + 1 nieaktywny w zakresie `i<6`): **~99 cykli na próbkę**, czyli przy 80 kHz **7,9 mln cykli/s = 16,5% całego CPU** zmarnowane na przepakowanie 5 bitów. Cała `collectEntropyBits` to 197 cykli, więc pętla to połowa jej kosztu.

### 7.2 Idea

Skoro maska jest stała przez miliony próbek, cały gather można policzyć **raz**, przy zmianie konfiguracji, i w ISR zostawić jedno indeksowanie tablicą.

Indeks bierzemy wprost z surowego bajtu IDR — nie trzeba go maskować, bo wpisy tablicy są zbudowane z uwzględnieniem maski, więc bity 5/6 (PA5 = latch, PA6 = LED, oba wyjścia, ale odczytywalne w IDR) są w niej ignorowane. Istniejący `uxtb` w `TIM14_IRQHandler` (`0x800089e`) już ogranicza indeks do 0..255.

### 7.3 Wariant A — tablica 256 B (najszybszy)

```c
static uint8_t gather_lut[256];   /* IDR -> upakowane bity */
static uint8_t gather_bits;       /* popcount(maska) = bitów na próbkę */

static void rebuildGatherLut(void) {
    const uint8_t mask = configuration.selected_ro_channels;
    for (unsigned v = 0; v < 256; v++) {
        uint8_t res = 0, pos = 0;
        for (unsigned i = 0; i < 8; i++) {      /* 8, nie 6 — naprawia PA7 */
            if (mask & (1u << i)) {
                if (v & (1u << i)) res |= (uint8_t)(1u << pos);
                pos++;
            }
        }
        gather_lut[v] = res;
    }
    uint8_t n = 0;
    for (unsigned i = 0; i < 8; i++) if (mask & (1u << i)) n++;
    gather_bits = n;
}

void collectEntropyBits(uint8_t data) {          /* cała ISR-owa ścieżka */
    copyEntropyBitsToBuffer(gather_lut[data], gather_bits);
}
```

Skompilowane tym samym toolchainem i flagami co projekt (gcc 14.3, `-Oz -mcpu=cortex-m0`) — gather to dokładnie 4 instrukcje:

```
ldr   r3, =gather_bits      2 cyk
ldrb  r1, [r3, #0]          2 cyk
ldr   r3, =gather_lut       2 cyk
ldrb  r0, [r3, r0]          2 cyk      <- ldrb Rd,[Rb,Ro], indeksowanie rejestrem
```

**8 cykli zamiast 116** (99 pętli + 17 prologu/odczytu maski). **Oszczędność ≈ 99 cykli na próbkę.**

Efekt uboczny: pętla budująca tablicę leci po **8 bitach**, więc **naprawia za darmo błąd z PA7**. Bits/próbkę wraca do 6 przy masce domyślnej, co skraca okno napełniania — dla m=4 z 2,56 ms do 2,13 ms. To działa **przeciwko** marginesowi, więc obie zmiany trzeba policzyć razem (sekcja 7.6).

**RAM:** zajęte 5380 B z 6144 (`.data` 396 + `.bss` 3444 + heap/stack 1540), zostaje ~764 B. Tablica 256 B wchodzi z zapasem ~508 B. Heap (`ProjectManager.HeapSize=0x200`) jest nieużywany — do odzyskania 512 B, jeśli potrzeba więcej luzu.

### 7.4 Wariant B — 2×16 B (jeśli szkoda RAM-u)

Rozbicie na nibble: dolna tablica dla bitów 0–3, górna dla 4–7, **z góry przesunięta** o liczbę bitów z dolnego nibbla, żeby w ISR zostało samo `orrs`:

```c
static uint8_t gather_lo[16], gather_hi[16], gather_bits;

/* w rebuild: */
uint8_t lo_bits = popcount8(mask & 0x0F);
for (unsigned v = 0; v < 16; v++) {
    gather_lo[v] = gather(v, mask & 0x0F);
    gather_hi[v] = (uint8_t)(gather(v, mask >> 4) << lo_bits);
}

void collectEntropyBits(uint8_t data) {
    copyEntropyBitsToBuffer(gather_lo[data & 0x0F] | gather_hi[data >> 4], gather_bits);
}
```

Zmierzone na wygenerowanym kodzie: **16 cykli** (3 `ldr` adresów + 3 `ldrb` + `ands` + `lsrs` + `orrs`). Czyli 8 cykli drożej niż wariant A, za 224 B RAM-u mniej. Przy 80 kHz te 8 cykli to 1,3% CPU — wariant A jest wart tych bajtów, ale B jest bezpiecznym fallbackiem.

### 7.5 Spójność tablicy względem ISR

Rebuild trwa ~15 tys. cykli (~0,3 ms); przez ten czas tablica jest w połowie stara, w połowie nowa, a `gather_bits` rozjeżdża się z zawartością wpisów. Opcje:

- **(a) zatrzymać TIM14 na czas rebuildu** — `__HAL_TIM_DISABLE(&htim14)` / rebuild / reset bufora / `__HAL_TIM_ENABLE`. Najprostsze i naturalne, bo zmiana konfiguracji **i tak** unieważnia aktualny bufor (`useRO` już woła `swapInputBuffer`). Utrata 0,3 ms próbkowania przy ręcznej komendzie jest bez znaczenia. **Zalecane.**
- (b) podwójna tablica + podmiana wskaźnika (zapis słowa jest atomowy na M0) — potrzebuje 512 B, w tym budżecie RAM za ciasno.
- (c) budowa na stosie + `memcpy` pod `__disable_irq()` — ~6 µs maskowania, gubi maks. jedną próbkę.

Niezależnie od wariantu: **rebuild musi lecieć z pętli głównej, nie z `CDC_Receive_FS`** — tak samo jak `save_config`. Wzorzec: `CDC_Receive_FS` ustawia tylko flagę `config_dirty`, a pętla główna robi rebuild + zapis + reset bufora.

### 7.6 Bilans po zmianie

Warto to zrobić razem z wyrzuceniem `HAL_TIM_IRQHandler` z ISR:

| | teraz | po LUT + bez HAL |
|---|---|---|
| wejście/wyjście z wyjątku | 28 | 28 |
| wrapper `TIM14_IRQHandler` | 30 | 26 |
| gather (`select_data`) | 116 | 8 |
| reszta `collectEntropyBits` | 81 | 81 |
| `HAL_TIM_IRQHandler` | 72 | 5 |
| **ISR razem** | **327 cyk (54% CPU)** | **~148 cyk (25% CPU)** |
| dla pętli głównej | 45% | **75%** |

Dla m=4, uwzględniając naprawę PA7 (6 bitów/próbkę → okno 2,13 ms zamiast 2,56 ms):

- SHA-256 nad 128 B: 32 000 cykli CPU / 0,75 = **0,89 ms** (było 1,47 ms)
- **Zapas na transakcję USB: 2,13 − 0,89 = 1,24 ms** (było 1,09 ms)

Mimo skrócenia okna o 17% margines rośnie, a co ważniejsze — przestaje być wrażliwy na karę za wait-state flasha: w wariancie pesymistycznym (+20%) zapas to wciąż ~1,0 ms, zamiast 0,3 ms jak teraz.

### 7.7 Dodatek: `buffer_bits_target`

Skoro konfiguracja jest już cache'owana, `copyEntropyBitsToBuffer` przy każdej próbce czyta `use_raw_entropy` i `configuration.selected_entropy_buffor_size` (`ldrb` + `cmp` + `ldrh` + `lsls` ≈ 8 cykli) tylko po to, żeby policzyć `buffor_size_to_use * 8`. Trzymać obok LUT-a gotowe `static uint32_t buffer_bits_target` / `buffer_bytes_target`, aktualizowane w tym samym rebuildzie — kolejne ~8 cykli mniej i, co istotniejsze, **ISR przestaje w ogóle czytać strukturę `configuration`**, co likwiduje wyścig z `setBufferMultiplicity` (błąd nr 4/5).

---

## Aneks: założenia i metoda

- Zegar: HSE 12 MHz × PLL4 = 48 MHz SYSCLK = HCLK = PCLK1 = APB1 timer clock (`trng.ioc:134-148`, `main.c:119`).
- TIM14: presc 0, ARR 599 → update co 600 taktów = 80 kHz (`main.c:175-180`).
- Model cyklowy Cortex-M0 (ARMv6-M), zero wait state; kara `FLASH_LATENCY_1` szacowana osobno jako +15–20% dla kodu z gałęziami.
- Liczby ISR i `compress` policzone ze `Release/trng.list` / `objdump -d` po ścieżkach faktycznie wykonywanych (dla `HAL_TIM_IRQHandler` — ścieżka z samą flagą UIF).
- `compress`: pętla 1 (i=0..15) 117 cykli/iterację, pętla 2 (i=16..63) 157 cykli/iterację, prolog+epilog 123 → ~9 500 cykli/blok 64 B.
- Warianty LUT skompilowane i zdisasemblowane tym samym toolchainem/flagami co projekt, żeby liczby cykli nie były szacunkiem.
- Latencja USB: przyjęte worst-case 1 ramka FS = 1 ms dla bulk IN przy single-buforowanym endpointcie re-armowanym z pętli głównej.

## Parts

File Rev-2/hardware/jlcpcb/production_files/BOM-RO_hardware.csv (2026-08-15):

Comment | Designator | Footprint | LCSC | Quantity
600@100Mhz | FB1,FB10,FB11,FB2,FB3,FB4,FB5,FB6,FB7,FB8,FB9 | R_0603_1608Metric | C1002 | 11
10uF | C2,C58 | C_1206_3216Metric | C13585 | 2
SN74LVC3G04 | U17,U18,U19,U20 | MSOP-8_3x3mm_P0.65mm | C139324 | 4
100nF | C10,C12,C14,C16,C18,C20,C22,C24,C26,C28,C30,C32,C34,C36,C38,C40,C43,C7 | C_0402_1005Metric | C1525 | 18
4.7nF | C11,C13,C15,C17,C19,C21,C23,C25,C27,C29,C31,C33,C35,C37,C39,C41,C42,C6 | C_0402_1005Metric | C1538 | 18
10uF | C44,C45,C56,C57,C59,C60,C8,C9 | C_0805_2012Metric | C15850 | 8
4.7nF | C1 | C_0805_2012Metric | C1744 | 1
1M | R1 | R_0805_2012Metric | C17514 | 1
2.2 | R33 | R_0805_2012Metric | C17521 | 1
330 | R22,R23,R24,R7 | R_0805_2012Metric | C17630 | 4
10nF | C52 | C_1206_3216Metric | C1846 | 1
1uF | C3,C53,C55 | C_1206_3216Metric | C1848 | 3
AP2112K-3.3 | U1,U2 | SOT-23-5 | C22365427 | 2
LED | D3 | D_0805_2012Metric | C2296 | 1
LED | D1,D2 | D_0805_2012Metric | C2297 | 2
4.7 | R25,R26,R27,R28,R29,R30,R31,R32,R34 | R_0603_1608Metric | C23164 | 9
100nF | C47,C49,C51,C54 | C_1206_3216Metric | C24497 | 4
100 | R9 | R_0402_1005Metric | C25076 | 1
120 | R6 | R_0402_1005Metric | C25079 | 1
200 | R14 | R_0402_1005Metric | C25087 | 1
220 | R8 | R_0402_1005Metric | C25091 | 1
22 | R2 | R_0402_1005Metric | C25092 | 1
330 | R16 | R_0402_1005Metric | C25104 | 1
47 | R10,R11,R12,R13,R15,R17,R18,R19,R20,R21,R5 | R_0402_1005Metric | C25120 | 11
74HC174 | U22,U3 | TSSOP-16_4.4x5mm_P0.65mm | C2652842 | 2
5.1k | R3,R4 | R_0805_2012Metric | C27834 | 2
4.7uF | C4,C46,C48,C5,C50,C61,C62,C63,C64 | C_1206_3216Metric | C29823 | 9
SW_Push | SW1,SW2,SW3 | XKBConnection-TS_1187A_B_AB | C318884 | 3
STM32G431CBTx | U21 | LQFP-48_7x7mm_P0.5mm | C529355 | 1
161N-4WVS11 | USB1 | USB-C-SMD_HANELECTRICITY_161N-4XVS11 | C5440753 | 1
4.7uH | L2 | L_1008_2520Metric | C5832360 | 1
SN74LVC1G04 | U10,U11,U12,U13,U14,U15,U16,U5,U6,U7,U8,U9 | SOT-353_SC-70-5 | C8207 | 12
LED | D4 | D_0805_2012Metric | C84256 | 1
RFShield_OnePiece | J2 | Laird_Technologies_BMI-S-205-F_38.10x25.40mm |  | 1
RFShield_OnePiece | J3 | Laird_Technologies_BMI-S-205-F_38.10x25.40mm |  | 1
Conn_ARM_JTAG_SWD_10 | J4 | Tag-Connect_TC2050-IDC-NL_2x05_P1.27mm_Vertical |  | 1

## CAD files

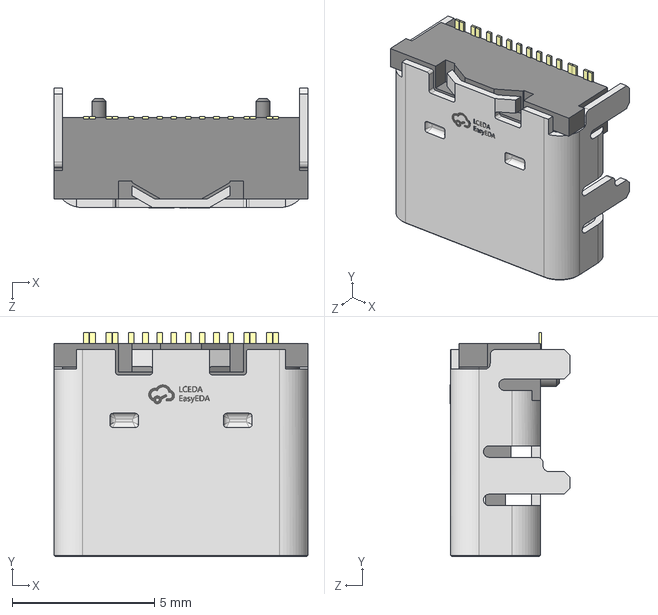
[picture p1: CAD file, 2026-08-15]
Rev-2/hardware/USB-C-SMD_HANELECTRICITY_161N-4XVS11/USB-C-SMD_HANELECTRICITY_161N-4XVS11.step
8.94 x 7.90 x 4.21 mm

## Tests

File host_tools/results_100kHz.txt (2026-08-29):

Opening file: 'outputA.bin'
Loaded 8388608 samples of 2 distinct 1-bit-wide symbols

Running non-IID tests...

Running Most Common Value Estimate...
Literal MCV Estimate: mode = 4311527, p-hat = 0.51397407054901123, p_u = 0.51441857128048474
	Most Common Value Estimate = 0.958985 / 1 bit(s)

Running Entropic Statistic Estimates (bit strings only)...
Literal Collision Estimate: X-bar = 2.7423229992592209, sigma-hat = 0.43735526355734922, p = 0.5
	Collision Test Estimate = 1.000000 / 1 bit(s)
Literal Markov Estimate: P_0 = 0.48602592945098877, P_1 = 0.51397407054901123, P_0,0 = 0.23155125727236159, P_0,1 = 0.76844874272763841, P_1,0 = 0.72666296650815365, P_1,1 = 0.27333703349184635, p_max = 4.2657367457900052e-17
	Markov Test Estimate = 0.424844 / 1 bit(s)
Literal Compression Estimate: X-bar = 3.7908231748304653, sigma-hat = 1.2386873441332786, p = 0.43270088045786881
	Compression Test Estimate = 0.201426 / 1 bit(s)

Running Tuple Estimates...
Literal t-Tuple Estimate: t = 145, p-hat_max = 0.9190685844445099, p_u = 0.91931113634637229
Literal LRS Estimate: u = 146, v = 171, p-hat = 0.84823791117614122, p_u = 0.84855700077095797
	T-Tuple Test Estimate = 0.121375 / 1 bit(s)
	LRS Test Estimate = 0.236917 / 1 bit(s)

Running Predictor Estimates...
Literal MultiMCW Prediction Estimate: N = 8388545, Pglobal' = 0.51412691814744882 (C = 4309048) Plocal can't affect result (r = 12)
	Multi Most Common in Window (MultiMCW) Prediction Test Estimate = 0.959804 / 1 bit(s)
Literal Lag Prediction Estimate: N = 8388607, Pglobal' = 0.55801903515313978 (C = 4677297) Plocal = 0.89633913606149307 (r = 167)
	Lag Prediction Test Estimate = 0.157883 / 1 bit(s)
Literal MultiMMC Prediction Estimate: N = 8388606, Pglobal' = 0.82929656685386632 (C = 6953833) Plocal = 0.89114307463584175 (r = 159)
	Multi Markov Model with Counting (MultiMMC) Prediction Test Estimate = 0.166271 / 1 bit(s)
Literal LZ78Y Prediction Estimate: N = 8388591, Pglobal' = 0.74735797520399405 (C = 6266037) Plocal = 0.89695503466686577 (r = 168)
	LZ78Y Prediction Test Estimate = 0.156892 / 1 bit(s)

H_original: 0.121375
Opening file: 'outputB.bin'
Loaded 8388608 samples of 2 distinct 1-bit-wide symbols

Running non-IID tests...

Running Most Common Value Estimate...
Literal MCV Estimate: mode = 4220345, p-hat = 0.50310432910919189, p_u = 0.50354899497126537
	Most Common Value Estimate = 0.989796 / 1 bit(s)

Running Entropic Statistic Estimates (bit strings only)...
Literal Collision Estimate: X-bar = 2.2739761341950033, sigma-hat = 0.44599693497578791, p = 0.83661699134650602
	Collision Test Estimate = 0.257361 / 1 bit(s)
Literal Markov Estimate: P_0 = 0.49689567089080811, P_1 = 0.50310432910919189, P_0,0 = 0.73889165316383665, P_0,1 = 0.26110834683616335, P_1,0 = 0.25788626285291844, P_1,1 = 0.74211373714708162, p_max = 1.7840533950078049e-17
	Markov Test Estimate = 0.434669 / 1 bit(s)
Literal Compression Estimate: X-bar = 3.9485483671463411, sigma-hat = 1.2700451610136523, p = 0.39942120165504347
	Compression Test Estimate = 0.220670 / 1 bit(s)

Running Tuple Estimates...
Literal t-Tuple Estimate: t = 139, p-hat_max = 0.91602939423748075, p_u = 0.91627604956676556
Literal LRS Estimate: u = 140, v = 177, p-hat = 0.84288124555412947, p_u = 0.84320489089880113
	T-Tuple Test Estimate = 0.126146 / 1 bit(s)
	LRS Test Estimate = 0.246045 / 1 bit(s)

Running Predictor Estimates...
Literal MultiMCW Prediction Estimate: N = 8388545, Pglobal' = 0.49979670876937943 (C = 4188837) Plocal = 0.89045796403198951 (r = 158)
	Multi Most Common in Window (MultiMCW) Prediction Test Estimate = 0.167381 / 1 bit(s)
Literal Lag Prediction Estimate: N = 8388607, Pglobal' = 0.74090195106233658 (C = 6211865) Plocal = 0.88976436489377531 (r = 157)
	Lag Prediction Test Estimate = 0.168505 / 1 bit(s)
Literal MultiMMC Prediction Estimate: N = 8388606, Pglobal' = 0.81057477101540798 (C = 6796667) Plocal = 0.88976436560579941 (r = 157)
	Multi Markov Model with Counting (MultiMMC) Prediction Test Estimate = 0.168505 / 1 bit(s)
Literal LZ78Y Prediction Estimate: N = 8388591, Pglobal' = 0.74090205249755203 (C = 6211854) Plocal = 0.88976437628944005 (r = 157)
	LZ78Y Prediction Test Estimate = 0.168505 / 1 bit(s)

H_original: 0.126146
Opening file: 'outputC.bin'
Loaded 8388608 samples of 2 distinct 1-bit-wide symbols

Running non-IID tests...

Running Most Common Value Estimate...
Literal MCV Estimate: mode = 4281480, p-hat = 0.51039218902587891, p_u = 0.51083676740065309
	Most Common Value Estimate = 0.969066 / 1 bit(s)

Running Entropic Statistic Estimates (bit strings only)...
Literal Collision Estimate: X-bar = 2.7138306689813003, sigma-hat = 0.45196959089001226, p = 0.5
	Collision Test Estimate = 1.000000 / 1 bit(s)
Literal Markov Estimate: P_0 = 0.48960781097412109, P_1 = 0.51039218902587891, P_0,0 = 0.26187131250840001, P_0,1 = 0.73812868749159999, P_1,0 = 0.7080705055425941, P_1,1 = 0.2919294944574059, p_max = 6.3844226123772562e-19
	Markov Test Estimate = 0.472204 / 1 bit(s)
Literal Compression Estimate: X-bar = 3.8054912430441612, sigma-hat = 1.2999248795022265, p = 0.42967881774662203
	Compression Test Estimate = 0.203112 / 1 bit(s)

Running Tuple Estimates...
Literal t-Tuple Estimate: t = 203, p-hat_max = 0.94080464127095786, p_u = 0.94101451868733788
Literal LRS Estimate: u = 204, v = 246, p-hat = 0.89055127581136395, p_u = 0.89082893175342071
	T-Tuple Test Estimate = 0.087711 / 1 bit(s)
	LRS Test Estimate = 0.166780 / 1 bit(s)

Running Predictor Estimates...
Literal MultiMCW Prediction Estimate: N = 8388545, Pglobal' = 0.51034088209350814 (C = 4277288) Plocal can't affect result (r = 14)
	Multi Most Common in Window (MultiMCW) Prediction Test Estimate = 0.970467 / 1 bit(s)
Literal Lag Prediction Estimate: N = 8388607, Pglobal' = 0.54909003386339916 (C = 4602388) Plocal = 0.93016601733634285 (r = 247)
	Lag Prediction Test Estimate = 0.104440 / 1 bit(s)
Literal MultiMMC Prediction Estimate: N = 8388606, Pglobal' = 0.82450516951805641 (C = 6913609) Plocal = 0.93045302832101928 (r = 248)
	Multi Markov Model with Counting (MultiMMC) Prediction Test Estimate = 0.103995 / 1 bit(s)
Literal LZ78Y Prediction Estimate: N = 8388591, Pglobal' = 0.72318407742861968 (C = 6063156) Plocal = 0.93045303541259838 (r = 248)
	LZ78Y Prediction Test Estimate = 0.103995 / 1 bit(s)

H_original: 0.087711
Opening file: 'outputD.bin'
Loaded 8388608 samples of 2 distinct 1-bit-wide symbols

Running non-IID tests...

Running Most Common Value Estimate...
Literal MCV Estimate: mode = 4320504, p-hat = 0.51504421234130859, p_u = 0.5154886854435784
	Most Common Value Estimate = 0.955987 / 1 bit(s)

Running Entropic Statistic Estimates (bit strings only)...
Literal Collision Estimate: X-bar = 2.7889173478873182, sigma-hat = 0.4080769798139654, p = 0.5
	Collision Test Estimate = 1.000000 / 1 bit(s)
Literal Markov Estimate: P_0 = 0.48495578765869141, P_1 = 0.51504421234130859, P_0,0 = 0.1688027149748384, P_0,1 = 0.83119728502516166, P_1,0 = 0.78263966024326337, P_1,1 = 0.21736033975673663, p_max = 6.9368506779719661e-13
	Markov Test Estimate = 0.315553 / 1 bit(s)
Literal Compression Estimate: X-bar = 3.5839100415640255, sigma-hat = 1.4084702512895202, p = 0.47486342339882803
	Compression Test Estimate = 0.179069 / 1 bit(s)

Running Tuple Estimates...
Literal t-Tuple Estimate: t = 153, p-hat_max = 0.9227928647680218, p_u = 0.92303024961240243
Literal LRS Estimate: u = 154, v = 176, p-hat = 0.85435574489262911, p_u = 0.85466946200344551
	T-Tuple Test Estimate = 0.115550 / 1 bit(s)
	LRS Test Estimate = 0.226562 / 1 bit(s)

Running Predictor Estimates...
Literal MultiMCW Prediction Estimate: N = 8388545, Pglobal' = 0.51523161094809566 (C = 4318315) Plocal can't affect result (r = 23)
	Multi Most Common in Window (MultiMCW) Prediction Test Estimate = 0.956707 / 1 bit(s)
Literal Lag Prediction Estimate: N = 8388607, Pglobal' = 0.70265187352581526 (C = 5890859) Plocal = 0.89695502392679671 (r = 168)
	Lag Prediction Test Estimate = 0.156892 / 1 bit(s)
Literal MultiMMC Prediction Estimate: N = 8388606, Pglobal' = 0.81883456275588717 (C = 6866005) Plocal = 0.8975638638125375 (r = 169)
	Multi Markov Model with Counting (MultiMMC) Prediction Test Estimate = 0.155914 / 1 bit(s)
Literal LZ78Y Prediction Estimate: N = 8388591, Pglobal' = 0.80653949735168318 (C = 6762781) Plocal = 0.89756387382862357 (r = 169)
	LZ78Y Prediction Test Estimate = 0.155913 / 1 bit(s)

H_original: 0.115550
Opening file: 'outputE.bin'
Loaded 8388608 samples of 2 distinct 1-bit-wide symbols

Running non-IID tests...

Running Most Common Value Estimate...
Literal MCV Estimate: mode = 4305410, p-hat = 0.5132448673248291, p_u = 0.51368938571476819
	Most Common Value Estimate = 0.961032 / 1 bit(s)

Running Entropic Statistic Estimates (bit strings only)...
Literal Collision Estimate: X-bar = 2.532196382553741, sigma-hat = 0.49896239147144833, p = 0.5
	Collision Test Estimate = 1.000000 / 1 bit(s)
Literal Markov Estimate: P_0 = 0.4867551326751709, P_1 = 0.5132448673248291, P_0,0 = 0.4095001026156459, P_0,1 = 0.59049989738435404, P_1,0 = 0.56002298504044568, P_1,1 = 0.43997701495955432, p_max = 1.5217672018281697e-31
	Markov Test Estimate = 0.799797 / 1 bit(s)
Literal Compression Estimate: X-bar = 4.1844854866064445, sigma-hat = 1.2412650837130657, p = 0.34732161638552617
	Compression Test Estimate = 0.254276 / 1 bit(s)

Running Tuple Estimates...
Literal t-Tuple Estimate: t = 90, p-hat_max = 0.87141789675671733, p_u = 0.87171559457748682
Literal LRS Estimate: u = 91, v = 118, p-hat = 0.7770636526046818, p_u = 0.77743381380398591
	T-Tuple Test Estimate = 0.198071 / 1 bit(s)
	LRS Test Estimate = 0.363208 / 1 bit(s)

Running Predictor Estimates...
Literal MultiMCW Prediction Estimate: N = 8388545, Pglobal' = 0.51336601754750011 (C = 4302665) Plocal can't affect result (r = 13)
	Multi Most Common in Window (MultiMCW) Prediction Test Estimate = 0.961940 / 1 bit(s)
Literal Lag Prediction Estimate: N = 8388607, Pglobal' = 0.61855271249172605 (C = 5185171) Plocal can't affect result (r = 29)
	Lag Prediction Test Estimate = 0.693032 / 1 bit(s)
Literal MultiMMC Prediction Estimate: N = 8388606, Pglobal' = 0.82298877954217442 (C = 6900879) Plocal = 0.84778048428225483 (r = 113)
	Multi Markov Model with Counting (MultiMMC) Prediction Test Estimate = 0.238237 / 1 bit(s)
Literal LZ78Y Prediction Estimate: N = 8388591, Pglobal' = 0.57529699011504631 (C = 4822243) Plocal can't affect result (r = 17)
	LZ78Y Prediction Test Estimate = 0.797621 / 1 bit(s)

H_original: 0.198071
Opening file: 'outputF.bin'
Loaded 8388608 samples of 2 distinct 1-bit-wide symbols

Running non-IID tests...

Running Most Common Value Estimate...
Literal MCV Estimate: mode = 4267801, p-hat = 0.50876152515411377, p_u = 0.50920613131129455
	Most Common Value Estimate = 0.973678 / 1 bit(s)

Running Entropic Statistic Estimates (bit strings only)...
Literal Collision Estimate: X-bar = 2.5072388743347913, sigma-hat = 0.49994767066591711, p = 0.5
	Collision Test Estimate = 1.000000 / 1 bit(s)
Literal Markov Estimate: P_0 = 0.49123847484588623, P_1 = 0.50876152515411377, P_0,0 = 0.45090803815854513, P_0,1 = 0.54909196184145492, P_1,0 = 0.53017995220019687, P_1,1 = 0.46982004779980313, p_max = 4.6477845850610551e-35
	Markov Test Estimate = 0.891023 / 1 bit(s)
Literal Compression Estimate: X-bar = 4.2998885675367102, sigma-hat = 1.2403878638287373, p = 0.32067648017739991
	Compression Test Estimate = 0.273468 / 1 bit(s)

Running Tuple Estimates...
Literal t-Tuple Estimate: t = 74, p-hat_max = 0.84680997917941558, p_u = 0.84713029646576243
Literal LRS Estimate: u = 75, v = 109, p-hat = 0.75489085013984591, p_u = 0.75527340524140341
	T-Tuple Test Estimate = 0.239344 / 1 bit(s)
	LRS Test Estimate = 0.404929 / 1 bit(s)

Running Predictor Estimates...
Literal MultiMCW Prediction Estimate: N = 8388545, Pglobal' = 0.50829324106895546 (C = 4260111) Plocal can't affect result (r = 16)
	Multi Most Common in Window (MultiMCW) Prediction Test Estimate = 0.976267 / 1 bit(s)
Literal Lag Prediction Estimate: N = 8388607, Pglobal' = 0.53752666275310279 (C = 4505380) Plocal = 0.79811249707845966 (r = 84)
	Lag Prediction Test Estimate = 0.325336 / 1 bit(s)
Literal MultiMMC Prediction Estimate: N = 8388606, Pglobal' = 0.79723669006447662 (C = 6684703) Plocal = 0.80673550275057404 (r = 88)
	Multi Markov Model with Counting (MultiMMC) Prediction Test Estimate = 0.309832 / 1 bit(s)
Literal LZ78Y Prediction Estimate: N = 8388591, Pglobal' = 0.53991147693681807 (C = 4525378) Plocal can't affect result (r = 17)
	LZ78Y Prediction Test Estimate = 0.889205 / 1 bit(s)

H_original: 0.239344
Opening file: 'outputA-F.bin'
Loaded 1398101 samples of 64 distinct 6-bit-wide symbols
Number of Binary Symbols: 8388606

Running non-IID tests...

Running Most Common Value Estimate...
Bitstring MCV Estimate: mode = 4278808, p-hat = 0.51007378341526588, p_u = 0.51051836763967751
	Most Common Value Estimate (bit string) = 0.969965 / 1 bit(s)
Literal MCV Estimate: mode = 32820, p-hat = 0.023474698895144201, p_u = 0.023804528570216827
	Most Common Value Estimate = 5.392620 / 6 bit(s)

Running Entropic Statistic Estimates (bit strings only)...
Bitstring Collision Estimate: X-bar = 2.4977311232131107, sigma-hat = 0.49999492660909051, p = 0.53854635283524388
	Collision Test Estimate (bit string) = 0.892858 / 1 bit(s)
Bitstring Markov Estimate: P_0 = 0.48992621658473412, P_1 = 0.51007378341526588, P_0,0 = 0.49519270776811902, P_0,1 = 0.50480729223188092, P_1,0 = 0.48486762782242809, P_1,1 = 0.51513237217757191, p_max = 1.3222879683657769e-37
	Markov Test Estimate (bit string) = 0.957096 / 1 bit(s)
Bitstring Compression Estimate: X-bar = 5.1565456972648613, sigma-hat = 1.0281691156038832, p = 0.066822899755331011
	Compression Test Estimate (bit string) = 0.650586 / 1 bit(s)

Running Tuple Estimates...
Bitstring t-Tuple Estimate: t = 28, p-hat_max = 0.64498431037104942, p_u = 0.64540987993037069
Bitstring LRS Estimate: u = 29, v = 82, p-hat = 0.69608555986202791, p_u = 0.69649461248999445
	T-Tuple Test Estimate (bit string) = 0.631712 / 1 bit(s)
Literal t-Tuple Estimate: t = 4, p-hat_max = 0.079554106637417257, p_u = 0.080143599288742803
Literal LRS Estimate: u = 5, v = 13, p-hat = 0.13013404136758919, p_u = 0.13086698333239141
	T-Tuple Test Estimate = 3.641269 / 6 bit(s)
	LRS Test Estimate (bit string) = 0.521816 / 1 bit(s)
	LRS Test Estimate = 2.933827 / 6 bit(s)

Running Predictor Estimates...
Bitstring MultiMCW Prediction Estimate: N = 8388543, Pglobal' = 0.50977488409348248 (C = 4272539) Plocal can't affect result (r = 17)
	Multi Most Common in Window (MultiMCW) Prediction Test Estimate (bit string) = 0.972068 / 1 bit(s)
Literal MultiMCW Prediction Estimate: N = 1398038, Pglobal' = 0.02275547336674217 (C = 31362) Plocal can't affect result (r = 4)
	Multi Most Common in Window (MultiMCW) Prediction Test Estimate = 5.457643 / 6 bit(s)
Bitstring Lag Prediction Estimate: N = 8388605, Pglobal' = 0.55168798092660198 (C = 4624182) Plocal = 0.55986790394533914 (r = 34)
	Lag Prediction Test Estimate (bit string) = 0.836842 / 1 bit(s)
Literal Lag Prediction Estimate: N = 1398100, Pglobal' = 0.028517864877683985 (C = 39367) Plocal can't affect result (r = 5)
	Lag Prediction Test Estimate = 5.131990 / 6 bit(s)
Bitstring MultiMMC Prediction Estimate: N = 8388604, Pglobal' = 0.62804569798879795 (C = 5264820) Plocal can't affect result (r = 40)
	Multi Markov Model with Counting (MultiMMC) Prediction Test Estimate (bit string) = 0.671059 / 1 bit(s)
Literal MultiMMC Prediction Estimate: N = 1398099, Pglobal' = 0.10496460500880653 (C = 145820) Plocal = 0.12638714212347757 (r = 9)
	Multi Markov Model with Counting (MultiMMC) Prediction Test Estimate = 2.984078 / 6 bit(s)
Bitstring LZ78Y Prediction Estimate: N = 8388589, Pglobal' = 0.51051689841216152 (C = 4278787) Plocal can't affect result (r = 17)
	LZ78Y Prediction Test Estimate (bit string) = 0.969969 / 1 bit(s)
Literal LZ78Y Prediction Estimate: N = 1398084, Pglobal' = 0.051662255888611334 (C = 71557) Plocal can't affect result (r = 6)
	LZ78Y Prediction Test Estimate = 4.274746 / 6 bit(s)

H_original: 2.933827
H_bitstring: 0.521816
min(H_original, 6 X H_bitstring): 2.933827

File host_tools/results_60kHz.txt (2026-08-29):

Opening file: 'outputA.bin'
Loaded 8388608 samples of 2 distinct 1-bit-wide symbols

Running non-IID tests...

Running Most Common Value Estimate...
Literal MCV Estimate: mode = 4302436, p-hat = 0.51289033889770508, p_u = 0.51333486553087671
	Most Common Value Estimate = 0.962028 / 1 bit(s)

Running Entropic Statistic Estimates (bit strings only)...
Literal Collision Estimate: X-bar = 2.5305800032881884, sigma-hat = 0.49906406255508517, p = 0.5
	Collision Test Estimate = 1.000000 / 1 bit(s)
Literal Markov Estimate: P_0 = 0.48710966110229492, P_1 = 0.51289033889770508, P_0,0 = 0.41981150083745861, P_0,1 = 0.58018849916254145, P_1,0 = 0.55102517527865036, P_1,1 = 0.44897482472134964, p_max = 1.7776696461502631e-32
	Markov Test Estimate = 0.823998 / 1 bit(s)
Literal Compression Estimate: X-bar = 3.9700769724097178, sigma-hat = 1.2975841025701909, p = 0.39480065904107575
	Compression Test Estimate = 0.223467 / 1 bit(s)

Running Tuple Estimates...
Literal t-Tuple Estimate: t = 119, p-hat_max = 0.90135517298314805, p_u = 0.90162036307325988
Literal LRS Estimate: u = 120, v = 151, p-hat = 0.82589192027388059, p_u = 0.82622916349353392
	T-Tuple Test Estimate = 0.149408 / 1 bit(s)
	LRS Test Estimate = 0.275386 / 1 bit(s)

Running Predictor Estimates...
Literal MultiMCW Prediction Estimate: N = 8388545, Pglobal' = 0.51306454184056438 (C = 4300136) Plocal = 0.8575576201124312 (r = 121)
	Multi Most Common in Window (MultiMCW) Prediction Test Estimate = 0.221694 / 1 bit(s)
Literal Lag Prediction Estimate: N = 8388607, Pglobal' = 0.51957475990703594 (C = 4354781) Plocal = 0.88466084957554103 (r = 150)
	Lag Prediction Test Estimate = 0.176804 / 1 bit(s)
Literal MultiMMC Prediction Estimate: N = 8388606, Pglobal' = 0.7831573288294823 (C = 6566522) Plocal = 0.87990825657173133 (r = 144)
	Multi Markov Model with Counting (MultiMMC) Prediction Test Estimate = 0.184575 / 1 bit(s)
Literal LZ78Y Prediction Estimate: N = 8388591, Pglobal' = 0.5656706014333267 (C = 4741481) Plocal = 0.87738704986405769 (r = 141)
	LZ78Y Prediction Test Estimate = 0.188715 / 1 bit(s)

H_original: 0.149408
Opening file: 'outputB.bin'
Loaded 8388608 samples of 2 distinct 1-bit-wide symbols

Running non-IID tests...

Running Most Common Value Estimate...
Literal MCV Estimate: mode = 4202419, p-hat = 0.50096738338470459, p_u = 0.50141205698510982
	Most Common Value Estimate = 0.995931 / 1 bit(s)

Running Entropic Statistic Estimates (bit strings only)...
Literal Collision Estimate: X-bar = 2.3764661321421268, sigma-hat = 0.48449917439870371, p = 0.74919682683977029
	Collision Test Estimate = 0.416583 / 1 bit(s)
Literal Markov Estimate: P_0 = 0.50096738338470459, P_1 = 0.49903261661529541, P_0,0 = 0.59398836717614312, P_0,1 = 0.40601163282385688, P_1,0 = 0.40758561249518654, P_1,1 = 0.59241438750481346, p_max = 9.3241187605576848e-30
	Markov Test Estimate = 0.753413 / 1 bit(s)
Literal Compression Estimate: X-bar = 3.7964290907288141, sigma-hat = 1.3416882724637604, p = 0.43158300979419795
	Compression Test Estimate = 0.202048 / 1 bit(s)

Running Tuple Estimates...
Literal t-Tuple Estimate: t = 101, p-hat_max = 0.88672827242794117, p_u = 0.88701012901919474
Literal LRS Estimate: u = 102, v = 139, p-hat = 0.80321965431137976, p_u = 0.80357322819462973
	T-Tuple Test Estimate = 0.172978 / 1 bit(s)
	LRS Test Estimate = 0.315499 / 1 bit(s)

Running Predictor Estimates...
Literal MultiMCW Prediction Estimate: N = 8388545, Pglobal' = 0.50099930121389047 (C = 4198925) Plocal = 0.83809795371940554 (r = 106)
	Multi Most Common in Window (MultiMCW) Prediction Test Estimate = 0.254809 / 1 bit(s)
Literal Lag Prediction Estimate: N = 8388607, Pglobal' = 0.59359115146301333 (C = 4975738) Plocal = 0.85869481447508589 (r = 122)
	Lag Prediction Test Estimate = 0.219783 / 1 bit(s)
Literal MultiMMC Prediction Estimate: N = 8388606, Pglobal' = 0.78789690461564665 (C = 6606305) Plocal = 0.85981462779302054 (r = 123)
	Multi Markov Model with Counting (MultiMMC) Prediction Test Estimate = 0.217902 / 1 bit(s)
Literal LZ78Y Prediction Estimate: N = 8388591, Pglobal' = 0.59364019719048666 (C = 4976140) Plocal = 0.85981464094872639 (r = 123)
	LZ78Y Prediction Test Estimate = 0.217902 / 1 bit(s)

H_original: 0.172978
Opening file: 'outputC.bin'
Loaded 8388608 samples of 2 distinct 1-bit-wide symbols

Running non-IID tests...

Running Most Common Value Estimate...
Literal MCV Estimate: mode = 4288133, p-hat = 0.51118528842926025, p_u = 0.51162985158098317
	Most Common Value Estimate = 0.966828 / 1 bit(s)

Running Entropic Statistic Estimates (bit strings only)...
Literal Collision Estimate: X-bar = 2.3183036818505287, sigma-hat = 0.46581810606506224, p = 0.80193301572175679
	Collision Test Estimate = 0.318446 / 1 bit(s)
Literal Markov Estimate: P_0 = 0.48881471157073975, P_1 = 0.51118528842926025, P_0,0 = 0.66904980520549451, P_0,1 = 0.33095019479450549, P_1,0 = 0.31646693711854018, P_1,1 = 0.68353306288145976, p_max = 5.284917471815337e-22
	Markov Test Estimate = 0.552192 / 1 bit(s)
Literal Compression Estimate: X-bar = 4.0799254792588995, sigma-hat = 1.2496463373770021, p = 0.37077528844401819
	Compression Test Estimate = 0.238564 / 1 bit(s)

Running Tuple Estimates...
Literal t-Tuple Estimate: t = 98, p-hat_max = 0.88151720299186465, p_u = 0.88180462181073493
Literal LRS Estimate: u = 99, v = 113, p-hat = 0.78197625469504961, p_u = 0.78234347005279714
	T-Tuple Test Estimate = 0.181469 / 1 bit(s)
	LRS Test Estimate = 0.354126 / 1 bit(s)

Running Predictor Estimates...
Literal MultiMCW Prediction Estimate: N = 8388545, Pglobal' = 0.51081521086757309 (C = 4281267) Plocal = 0.84778054166780237 (r = 113)
	Multi Most Common in Window (MultiMCW) Prediction Test Estimate = 0.238237 / 1 bit(s)
Literal Lag Prediction Estimate: N = 8388607, Pglobal' = 0.67685376568149425 (C = 5674370) Plocal = 0.84646646661947711 (r = 112)
	Lag Prediction Test Estimate = 0.240475 / 1 bit(s)
Literal MultiMMC Prediction Estimate: N = 8388606, Pglobal' = 0.77765781621895957 (C = 6520361) Plocal = 0.84646646756693378 (r = 112)
	Multi Markov Model with Counting (MultiMMC) Prediction Test Estimate = 0.240475 / 1 bit(s)
Literal LZ78Y Prediction Estimate: N = 8388591, Pglobal' = 0.67686756865295961 (C = 5674475) Plocal = 0.84646648178081096 (r = 112)
	LZ78Y Prediction Test Estimate = 0.240475 / 1 bit(s)

H_original: 0.181469
Opening file: 'outputD.bin'
Loaded 8388608 samples of 2 distinct 1-bit-wide symbols

Running non-IID tests...

Running Most Common Value Estimate...
Literal MCV Estimate: mode = 4322498, p-hat = 0.51528191566467285, p_u = 0.51572638235301316
	Most Common Value Estimate = 0.955322 / 1 bit(s)

Running Entropic Statistic Estimates (bit strings only)...
Literal Collision Estimate: X-bar = 2.6443488383895857, sigma-hat = 0.47871023082341591, p = 0.5
	Collision Test Estimate = 1.000000 / 1 bit(s)
Literal Markov Estimate: P_0 = 0.48471808433532715, P_1 = 0.51528191566467285, P_0,0 = 0.31957817176613518, P_0,1 = 0.68042182823386477, P_1,0 = 0.64006290808299005, P_1,1 = 0.35993709191700995, p_max = 5.9610687238689031e-24
	Markov Test Estimate = 0.602740 / 1 bit(s)
Literal Compression Estimate: X-bar = 3.9760523338011269, sigma-hat = 1.306240452145589, p = 0.39351472315091462
	Compression Test Estimate = 0.224252 / 1 bit(s)

Running Tuple Estimates...
Literal t-Tuple Estimate: t = 115, p-hat_max = 0.89810500657494852, p_u = 0.89837404365255757
Literal LRS Estimate: u = 116, v = 140, p-hat = 0.81591057702853464, p_u = 0.8162552504974776
	T-Tuple Test Estimate = 0.154612 / 1 bit(s)
	LRS Test Estimate = 0.292908 / 1 bit(s)

Running Predictor Estimates...
Literal MultiMCW Prediction Estimate: N = 8388545, Pglobal' = 0.51537597066467777 (C = 4319526) Plocal = 0.7911428732788055 (r = 81)
	Multi Most Common in Window (MultiMCW) Prediction Test Estimate = 0.337990 / 1 bit(s)
Literal Lag Prediction Estimate: N = 8388607, Pglobal' = 0.53426470638332435 (C = 4478015) Plocal = 0.8773870373605156 (r = 141)
	Lag Prediction Test Estimate = 0.188715 / 1 bit(s)
Literal MultiMMC Prediction Estimate: N = 8388606, Pglobal' = 0.77210292884944443 (C = 6473736) Plocal = 0.87823874998842011 (r = 142)
	Multi Markov Model with Counting (MultiMMC) Prediction Test Estimate = 0.187315 / 1 bit(s)
Literal LZ78Y Prediction Estimate: N = 8388591, Pglobal' = 0.66004743752215655 (C = 5533333) Plocal = 0.87823876163941339 (r = 142)
	LZ78Y Prediction Test Estimate = 0.187315 / 1 bit(s)

H_original: 0.154612
Opening file: 'outputE.bin'
Loaded 8388608 samples of 2 distinct 1-bit-wide symbols

Running non-IID tests...

Running Most Common Value Estimate...
Literal MCV Estimate: mode = 4304989, p-hat = 0.51319468021392822, p_u = 0.51363919978437877
	Most Common Value Estimate = 0.961173 / 1 bit(s)

Running Entropic Statistic Estimates (bit strings only)...
Literal Collision Estimate: X-bar = 2.4547319376786669, sigma-hat = 0.49794665888101336, p = 0.65159468759945138
	Collision Test Estimate = 0.617953 / 1 bit(s)
Literal Markov Estimate: P_0 = 0.48680531978607178, P_1 = 0.51319468021392822, P_0,0 = 0.5108471186954513, P_0,1 = 0.4891528813045487, P_1,0 = 0.46399966736260356, P_1,1 = 0.53600033263739644, p_max = 2.0617911246814283e-35
	Markov Test Estimate = 0.900184 / 1 bit(s)
Literal Compression Estimate: X-bar = 4.1220156586836412, sigma-hat = 1.2626220909125998, p = 0.36141624394451777
	Compression Test Estimate = 0.244711 / 1 bit(s)

Running Tuple Estimates...
Literal t-Tuple Estimate: t = 104, p-hat_max = 0.88795418215094513, p_u = 0.88823470307404173
Literal LRS Estimate: u = 105, v = 139, p-hat = 0.80321965431137976, p_u = 0.80357322819462973
	T-Tuple Test Estimate = 0.170987 / 1 bit(s)
	LRS Test Estimate = 0.315499 / 1 bit(s)

Running Predictor Estimates...
Literal MultiMCW Prediction Estimate: N = 8388545, Pglobal' = 0.51298765299261151 (C = 4299491) Plocal = 0.86091744921373314 (r = 124)
	Multi Most Common in Window (MultiMCW) Prediction Test Estimate = 0.216053 / 1 bit(s)
Literal Lag Prediction Estimate: N = 8388607, Pglobal' = 0.52419871227283721 (C = 4393571) Plocal = 0.85981462691618504 (r = 123)
	Lag Prediction Test Estimate = 0.217902 / 1 bit(s)
Literal MultiMMC Prediction Estimate: N = 8388606, Pglobal' = 0.77114348756684081 (C = 6465683) Plocal = 0.85981462779301154 (r = 123)
	Multi Markov Model with Counting (MultiMMC) Prediction Test Estimate = 0.217902 / 1 bit(s)
Literal LZ78Y Prediction Estimate: N = 8388591, Pglobal' = 0.52419911561626376 (C = 4393566) Plocal = 0.85981464094872639 (r = 123)
	LZ78Y Prediction Test Estimate = 0.217902 / 1 bit(s)

H_original: 0.170987
Opening file: 'outputF.bin'
Loaded 8388608 samples of 2 distinct 1-bit-wide symbols

Running non-IID tests...

Running Most Common Value Estimate...
Literal MCV Estimate: mode = 4258521, p-hat = 0.50765526294708252, p_u = 0.50809988525815708
	Most Common Value Estimate = 0.976816 / 1 bit(s)

Running Entropic Statistic Estimates (bit strings only)...
Literal Collision Estimate: X-bar = 2.3475940019220447, sigma-hat = 0.4762063368050572, p = 0.77663595182204626
	Collision Test Estimate = 0.364690 / 1 bit(s)
Literal Markov Estimate: P_0 = 0.49234473705291748, P_1 = 0.50765526294708252, P_0,0 = 0.62633668491729111, P_0,1 = 0.37366331508270889, P_1,0 = 0.36239374242694644, P_1,1 = 0.63760625757305356, p_max = 7.65147854967919e-26
	Markov Test Estimate = 0.651831 / 1 bit(s)
Literal Compression Estimate: X-bar = 4.0124014182055401, sigma-hat = 1.3097225504099548, p = 0.38563110564092151
	Compression Test Estimate = 0.229118 / 1 bit(s)

Running Tuple Estimates...
Literal t-Tuple Estimate: t = 114, p-hat_max = 0.89703706030964636, p_u = 0.89730734273980117
Literal LRS Estimate: u = 115, v = 136, p-hat = 0.80837121366457243, p_u = 0.80872124582598848
	T-Tuple Test Estimate = 0.156326 / 1 bit(s)
	LRS Test Estimate = 0.306286 / 1 bit(s)

Running Predictor Estimates...
Literal MultiMCW Prediction Estimate: N = 8388545, Pglobal' = 0.50670466608074982 (C = 4246785) Plocal = 0.87386174556888074 (r = 137)
	Multi Most Common in Window (MultiMCW) Prediction Test Estimate = 0.194523 / 1 bit(s)
Literal Lag Prediction Estimate: N = 8388607, Pglobal' = 0.63248555404519191 (C = 5302075) Plocal = 0.87294950800343041 (r = 136)
	Lag Prediction Test Estimate = 0.196030 / 1 bit(s)
Literal MultiMMC Prediction Estimate: N = 8388606, Pglobal' = 0.77071684328823942 (C = 6462102) Plocal = 0.87294950880911215 (r = 136)
	Multi Markov Model with Counting (MultiMMC) Prediction Test Estimate = 0.196030 / 1 bit(s)
Literal LZ78Y Prediction Estimate: N = 8388591, Pglobal' = 0.63248687889597666 (C = 5302076) Plocal = 0.87294952089799815 (r = 136)
	LZ78Y Prediction Test Estimate = 0.196030 / 1 bit(s)

H_original: 0.156326
Opening file: 'outputA-F.bin'
Loaded 1398101 samples of 64 distinct 6-bit-wide symbols
Number of Binary Symbols: 8388606

Running non-IID tests...

Running Most Common Value Estimate...
Bitstring MCV Estimate: mode = 4267866, p-hat = 0.50876939505801078, p_u = 0.50921400114547344
	Most Common Value Estimate (bit string) = 0.973656 / 1 bit(s)
Literal MCV Estimate: mode = 27367, p-hat = 0.019574408429720028, p_u = 0.019876194787813627
	Most Common Value Estimate = 5.652815 / 6 bit(s)

Running Entropic Statistic Estimates (bit strings only)...
Bitstring Collision Estimate: X-bar = 2.4990273324062455, sigma-hat = 0.49999912839357813, p = 0.52894496222271181
	Collision Test Estimate (bit string) = 0.918810 / 1 bit(s)
Bitstring Markov Estimate: P_0 = 0.49123060494198917, P_1 = 0.50876939505801078, P_0,0 = 0.49687786583911286, P_0,1 = 0.50312213416088714, P_1,0 = 0.48577813830143685, P_1,1 = 0.51422186169856321, p_max = 1.0535110508336192e-37
	Markov Test Estimate (bit string) = 0.959657 / 1 bit(s)
Bitstring Compression Estimate: X-bar = 5.2596553900120462, sigma-hat = 0.97034697641196055, p = 0.015625
	Compression Test Estimate (bit string) = 1.000000 / 1 bit(s)

Running Tuple Estimates...
Bitstring t-Tuple Estimate: t = 27, p-hat_max = 0.63633738441466636, p_u = 0.63676520852446228
Bitstring LRS Estimate: u = 28, v = 90, p-hat = 0.71037250631490834, p_u = 0.7107759056447529
	T-Tuple Test Estimate (bit string) = 0.651167 / 1 bit(s)
Literal t-Tuple Estimate: t = 4, p-hat_max = 0.073588772812662462, p_u = 0.074157567651251949
Literal LRS Estimate: u = 5, v = 14, p-hat = 0.13917738220802819, p_u = 0.13993141308145562
	T-Tuple Test Estimate = 3.753262 / 6 bit(s)
	LRS Test Estimate (bit string) = 0.492533 / 1 bit(s)
	LRS Test Estimate = 2.837208 / 6 bit(s)

Running Predictor Estimates...
Bitstring MultiMCW Prediction Estimate: N = 8388543, Pglobal' = 0.50721511984339429 (C = 4251066) Plocal can't affect result (r = 19)
	Multi Most Common in Window (MultiMCW) Prediction Test Estimate (bit string) = 0.979330 / 1 bit(s)
Literal MultiMCW Prediction Estimate: N = 1398038, Pglobal' = 0.01841530326760752 (C = 25339) Plocal can't affect result (r = 4)
	Multi Most Common in Window (MultiMCW) Prediction Test Estimate = 5.762951 / 6 bit(s)
Bitstring Lag Prediction Estimate: N = 8388605, Pglobal' = 0.52179984572993299 (C = 4373446) Plocal can't affect result (r = 22)
	Lag Prediction Test Estimate (bit string) = 0.938432 / 1 bit(s)
Literal Lag Prediction Estimate: N = 1398100, Pglobal' = 0.022259610593559572 (C = 30675) Plocal = 0.069362279604614663 (r = 7)
	Lag Prediction Test Estimate = 3.849705 / 6 bit(s)
Bitstring MultiMMC Prediction Estimate: N = 8388604, Pglobal' = 0.63298466865765912 (C = 5306261) Plocal can't affect result (r = 35)
	Multi Markov Model with Counting (MultiMMC) Prediction Test Estimate (bit string) = 0.659758 / 1 bit(s)
Literal MultiMMC Prediction Estimate: N = 1398099, Pglobal' = 0.12067644812648784 (C = 167728) Plocal can't affect result (r = 7)
	Multi Markov Model with Counting (MultiMMC) Prediction Test Estimate = 3.050784 / 6 bit(s)
Bitstring LZ78Y Prediction Estimate: N = 8388589, Pglobal' = 0.50921002590947606 (C = 4267824) Plocal can't affect result (r = 19)
	LZ78Y Prediction Test Estimate (bit string) = 0.973667 / 1 bit(s)
Literal LZ78Y Prediction Estimate: N = 1398084, Pglobal' = 0.062259503196574265 (C = 86311) Plocal can't affect result (r = 5)
	LZ78Y Prediction Test Estimate = 4.005562 / 6 bit(s)

H_original: 2.837208
H_bitstring: 0.492533
min(H_original, 6 X H_bitstring): 2.837208

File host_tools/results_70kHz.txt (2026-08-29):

Opening file: 'outputA.bin'
Loaded 8388608 samples of 2 distinct 1-bit-wide symbols

Running non-IID tests...

Running Most Common Value Estimate...
Literal MCV Estimate: mode = 4301344, p-hat = 0.51276016235351562, p_u = 0.5132046919572838
	Most Common Value Estimate = 0.962394 / 1 bit(s)

Running Entropic Statistic Estimates (bit strings only)...
Literal Collision Estimate: X-bar = 2.8083286966454484, sigma-hat = 0.39361588724716845, p = 0.5
	Collision Test Estimate = 1.000000 / 1 bit(s)
Literal Markov Estimate: P_0 = 0.48723983764648438, P_1 = 0.51276016235351562, P_0,0 = 0.16202843760520486, P_0,1 = 0.8379715623947952, P_1,0 = 0.79626549196378893, P_1,1 = 0.20373450803621107, p_max = 3.4758756340329478e-12
	Markov Test Estimate = 0.297389 / 1 bit(s)
Literal Compression Estimate: X-bar = 3.3866340045457983, sigma-hat = 1.3672525545007115, p = 0.51347697348996257
	Compression Test Estimate = 0.160271 / 1 bit(s)

Running Tuple Estimates...
Literal t-Tuple Estimate: t = 150, p-hat_max = 0.92091059339551451, p_u = 0.92115060931513293
Literal LRS Estimate: u = 151, v = 182, p-hat = 0.85626919540140589, p_u = 0.85658119371307151
	T-Tuple Test Estimate = 0.118491 / 1 bit(s)
	LRS Test Estimate = 0.223338 / 1 bit(s)

Running Predictor Estimates...
Literal MultiMCW Prediction Estimate: N = 8388545, Pglobal' = 0.5129343672266925 (C = 4299044) Plocal can't affect result (r = 13)
	Multi Most Common in Window (MultiMCW) Prediction Test Estimate = 0.963154 / 1 bit(s)
Literal Lag Prediction Estimate: N = 8388607, Pglobal' = 0.68332068150767566 (C = 5728637) Plocal = 0.90540960137712856 (r = 183)
	Lag Prediction Test Estimate = 0.143357 / 1 bit(s)
Literal MultiMMC Prediction Estimate: N = 8388606, Pglobal' = 0.82947333596560657 (C = 6955317) Plocal = 0.905925627019734 (r = 184)
	Multi Markov Model with Counting (MultiMMC) Prediction Test Estimate = 0.142535 / 1 bit(s)
Literal LZ78Y Prediction Estimate: N = 8388591, Pglobal' = 0.81692744701609221 (C = 6849983) Plocal = 0.90592563631024181 (r = 184)
	LZ78Y Prediction Test Estimate = 0.142535 / 1 bit(s)

H_original: 0.118491
Opening file: 'outputB.bin'
Loaded 8388608 samples of 2 distinct 1-bit-wide symbols

Running non-IID tests...

Running Most Common Value Estimate...
Literal MCV Estimate: mode = 4204446, p-hat = 0.50120902061462402, p_u = 0.50165369374731938
	Most Common Value Estimate = 0.995236 / 1 bit(s)

Running Entropic Statistic Estimates (bit strings only)...
Literal Collision Estimate: X-bar = 2.5547568542953076, sigma-hat = 0.49699271838956982, p = 0.5
	Collision Test Estimate = 1.000000 / 1 bit(s)
Literal Markov Estimate: P_0 = 0.49879097938537598, P_1 = 0.50120902061462402, P_0,0 = 0.41162182812755055, P_0,1 = 0.58837817187244945, P_1,0 = 0.5855394503818101, P_1,1 = 0.4144605496181899, p_max = 2.0510492081391791e-30
	Markov Test Estimate = 0.770480 / 1 bit(s)
Literal Compression Estimate: X-bar = 4.0193375736669728, sigma-hat = 1.2878056504511988, p = 0.38410850105185212
	Compression Test Estimate = 0.230069 / 1 bit(s)

Running Tuple Estimates...
Literal t-Tuple Estimate: t = 132, p-hat_max = 0.91042744335727366, p_u = 0.91068141329394281
Literal LRS Estimate: u = 133, v = 184, p-hat = 0.85328043041564139, p_u = 0.85359510529196281
	T-Tuple Test Estimate = 0.134982 / 1 bit(s)
	LRS Test Estimate = 0.228376 / 1 bit(s)

Running Predictor Estimates...
Literal MultiMCW Prediction Estimate: N = 8388545, Pglobal' = 0.49520637736121742 (C = 4150331) Plocal = 0.8271497208769496 (r = 99)
	Multi Most Common in Window (MultiMCW) Prediction Test Estimate = 0.273780 / 1 bit(s)
Literal Lag Prediction Estimate: N = 8388607, Pglobal' = 0.51809279835090249 (C = 4342349) Plocal = 0.90643622539517743 (r = 185)
	Lag Prediction Test Estimate = 0.141723 / 1 bit(s)
Literal MultiMMC Prediction Estimate: N = 8388606, Pglobal' = 0.79001285040166347 (C = 6624066) Plocal = 0.90694148316003731 (r = 186)
	Multi Markov Model with Counting (MultiMMC) Prediction Test Estimate = 0.140919 / 1 bit(s)
Literal LZ78Y Prediction Estimate: N = 8388591, Pglobal' = 0.58739260904570312 (C = 4923723) Plocal = 0.90694149236154431 (r = 186)
	LZ78Y Prediction Test Estimate = 0.140919 / 1 bit(s)

H_original: 0.134982
Opening file: 'outputC.bin'
Loaded 8388608 samples of 2 distinct 1-bit-wide symbols

Running non-IID tests...

Running Most Common Value Estimate...
Literal MCV Estimate: mode = 4284656, p-hat = 0.51077079772949219, p_u = 0.51121536897676989
	Most Common Value Estimate = 0.967997 / 1 bit(s)

Running Entropic Statistic Estimates (bit strings only)...
Literal Collision Estimate: X-bar = 2.3102080496157504, sigma-hat = 0.46257872248819204, p = 0.80855894334843748
	Collision Test Estimate = 0.306575 / 1 bit(s)
Literal Markov Estimate: P_0 = 0.48922920227050781, P_1 = 0.51077079772949219, P_0,0 = 0.67567668327423991, P_0,1 = 0.32432331672576009, P_1,0 = 0.31064524199842414, P_1,1 = 0.68935475800157586, p_max = 1.5504536930557087e-21
	Markov Test Estimate = 0.540061 / 1 bit(s)
Literal Compression Estimate: X-bar = 4.0411436822176441, sigma-hat = 1.2470642815997535, p = 0.37931893728687005
	Compression Test Estimate = 0.233086 / 1 bit(s)

Running Tuple Estimates...
Literal t-Tuple Estimate: t = 116, p-hat_max = 0.8991497954275528, p_u = 0.89941760529342596
Literal LRS Estimate: u = 117, v = 143, p-hat = 0.81639961247254422, p_u = 0.81674393096411224
	T-Tuple Test Estimate = 0.152937 / 1 bit(s)
	LRS Test Estimate = 0.292044 / 1 bit(s)

Running Predictor Estimates...
Literal MultiMCW Prediction Estimate: N = 8388545, Pglobal' = 0.51047093810030719 (C = 4278379) Plocal = 0.88072653977347881 (r = 145)
	Multi Most Common in Window (MultiMCW) Prediction Test Estimate = 0.183234 / 1 bit(s)
Literal Lag Prediction Estimate: N = 8388607, Pglobal' = 0.68307698363394298 (C = 5726592) Plocal = 0.87990825580445331 (r = 144)
	Lag Prediction Test Estimate = 0.184575 / 1 bit(s)
Literal MultiMMC Prediction Estimate: N = 8388606, Pglobal' = 0.79398475085877407 (C = 6657406) Plocal = 0.87990825657173133 (r = 144)
	Multi Markov Model with Counting (MultiMMC) Prediction Test Estimate = 0.184575 / 1 bit(s)
Literal LZ78Y Prediction Estimate: N = 8388591, Pglobal' = 0.68307649813445326 (C = 5726577) Plocal = 0.87990826808438638 (r = 144)
	LZ78Y Prediction Test Estimate = 0.184575 / 1 bit(s)

H_original: 0.152937
Opening file: 'outputD.bin'
Loaded 8388608 samples of 2 distinct 1-bit-wide symbols

Running non-IID tests...

Running Most Common Value Estimate...
Literal MCV Estimate: mode = 4364373, p-hat = 0.52027380466461182, p_u = 0.52071811340039009
	Most Common Value Estimate = 0.941426 / 1 bit(s)

Running Entropic Statistic Estimates (bit strings only)...
Literal Collision Estimate: X-bar = 2.2363368850518577, sigma-hat = 0.4248315076955555, p = 0.86347498312030813
	Collision Test Estimate = 0.211774 / 1 bit(s)
Literal Markov Estimate: P_0 = 0.47972619533538818, P_1 = 0.52027380466461182, P_0,0 = 0.75762716581590439, P_0,1 = 0.24237283418409561, P_1,0 = 0.22348364816664387, P_1,1 = 0.7765163518333561, p_max = 5.8258441109761602e-15
	Markov Test Estimate = 0.369425 / 1 bit(s)
Literal Compression Estimate: X-bar = 3.8007043224279169, sigma-hat = 1.2874862183458369, p = 0.43066947957370538
	Compression Test Estimate = 0.202558 / 1 bit(s)

Running Tuple Estimates...
Literal t-Tuple Estimate: t = 139, p-hat_max = 0.91492554534421733, p_u = 0.91517366697050562
Literal LRS Estimate: u = 140, v = 167, p-hat = 0.84199026875565364, p_u = 0.84231465886837897
	T-Tuple Test Estimate = 0.127883 / 1 bit(s)
	LRS Test Estimate = 0.247569 / 1 bit(s)
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

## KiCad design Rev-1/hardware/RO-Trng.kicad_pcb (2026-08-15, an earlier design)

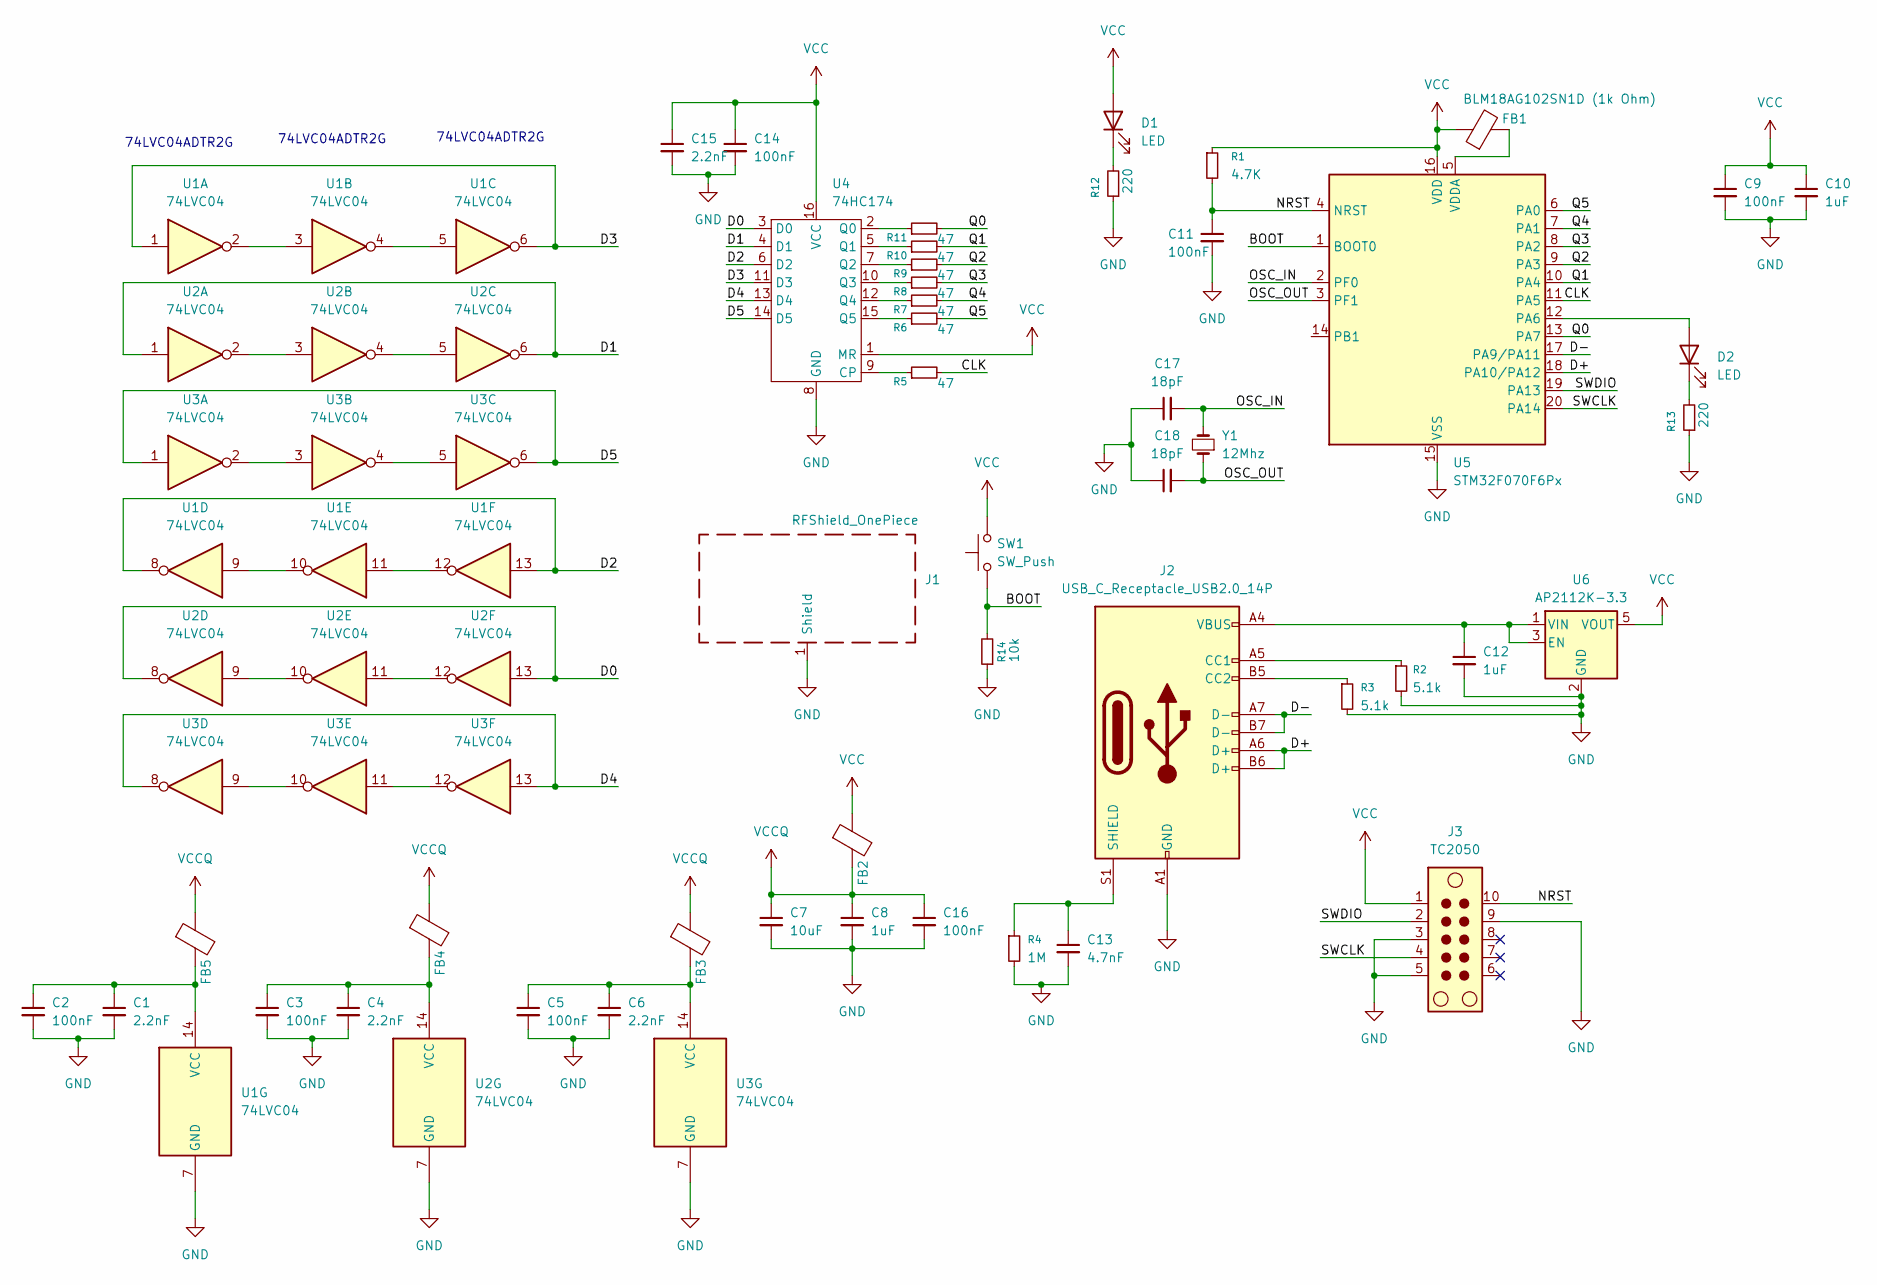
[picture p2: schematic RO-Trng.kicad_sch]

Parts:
C1, C4, C6, C15: 2.2nF; C_0402_1005Metric
C2, C3, C5, C14, C16: 100nF; C_0402_1005Metric
C7: 10uF; C_0805_2012Metric
C8: 1uF; C_0603_1608Metric_Pad1.08x0.95mm_HandSolder
C9, C11: 100nF; C_0603_1608Metric_Pad1.08x0.95mm_HandSolder
C10, C12: 1uF; C_0805_2012Metric
C13: 4.7nF; C_0603_1608Metric_Pad1.08x0.95mm_HandSolder
C17, C18: 18pF; C_0402_1005Metric
D1, D2: LED; LED_0603_1608Metric
FB1, FB2, FB3, FB4, FB5: BLM18AG102SN1D (1k Ohm); R_0603_1608Metric
J1: RFShield_OnePiece; Laird_Technologies_BMI-S-205-F_38.10x25.40mm
J2: USB_C_Receptacle_USB2.0_14P; USB_C_Receptacle_JAE_DX07S016JA1R1500
J3: TC2050; Tag-Connect_TC2050-IDC-NL_2x05_P1.27mm_Vertical
R1: 4.7K; R_0402_1005Metric
R2, R3: 5.1k; R_0402_1005Metric
R4: 1M; R_0402_1005Metric
R5, R6, R7, R8, R9, R10, R11: 47; R_0402_1005Metric
R12, R13: 220; R_0402_1005Metric
R14: 10k; R_0805_2012Metric
SW1: SW_Push; SW_Push_1P1T_XKB_TS-1187A
U1, U2, U3: 74LVC04; TSSOP-14_4.4x5mm_P0.65mm
U4: 74HC174; TSSOP-16_4.4x5mm_P0.65mm
U5: STM32F070F6Px; TSSOP-20_4.4x6.5mm_P0.65mm
U6: AP2112K-3.3; SOT-23-5
Y1: 12Mhz; Crystal_SMD_3225-4Pin_3.2x2.5mm

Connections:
/BOOT: R14.2, SW1.1, U5.1 (BOOT0)
/CLK: R5.2, U5.11 (PA5)
/D0: U2.8, U2.13, U4.3 (D0)
/D1: U2.1, U2.6, U4.4 (D1)
/D2: U1.8, U1.13, U4.6 (D2)
/D3: U1.1, U1.6, U4.11 (D3)
/D4: U3.8, U3.13, U4.13 (D4)
/D5: U3.1, U3.6, U4.14 (D5)
/D+: J2.A6 (D+), J2.B6 (D+), U5.18 (PA10/PA12)
/D-: J2.A7 (D-), J2.B7 (D-), U5.17 (PA9/PA11)
/NRST: C11.1, J3.10, R1.2, U5.4 (NRST)
/OSC_IN: C17.2, U5.2 (PF0), Y1.2
/OSC_OUT: C18.2, U5.3 (PF1), Y1.1
/Q0: R11.2, U5.13 (PA7)
/Q1: R10.2, U5.10 (PA4)
/Q2: R9.2, U5.9 (PA3)
/Q3: R8.2, U5.8 (PA2)
/Q4: R7.2, U5.7 (PA1)
/Q5: R6.2, U5.6 (PA0)
/SWCLK: J3.4, U5.20 (PA14)
/SWDIO: J3.2, U5.19 (PA13)
GND: C1.2, C2.2, C3.2, C4.2, C5.2, C6.2, C7.2, C8.2, C9.2, C10.2, C11.2, C12.2, C13.2, C14.2, C15.2, C16.2, C17.1, C18.1, J1.1 (Shield), J2.A1 (GND), J2.A12 (GND), J2.B1 (GND), J2.B12 (GND), J3.3, J3.5, J3.9, R2.2, R3.2, R4.2, R12.1, R13.1, R14.1, U1.7 (GND), U2.7 (GND), U3.7 (GND), U4.8 (GND), U5.15 (VSS), U6.2 (GND)
unnamed: D1.1 (K), R12.2
unnamed: D2.2 (A), U5.12 (PA6)
unnamed: D2.1 (K), R13.2
unnamed: J2.A5 (CC1), R2.1
unnamed: J2.B5 (CC2), R3.1
unnamed: C13.1, J2.S1 (SHIELD), R4.1
unnamed: U1.2, U1.3
unnamed: U1.4, U1.5
unnamed: U1.9, U1.10
unnamed: U1.11, U1.12
unnamed: C1.1, C2.1, FB5.2, U1.14 (VCC)
unnamed: U2.2, U2.3
unnamed: U2.4, U2.5
unnamed: U2.9, U2.10
unnamed: U2.11, U2.12
unnamed: C3.1, C4.1, FB4.2, U2.14 (VCC)
unnamed: U3.2, U3.3
unnamed: U3.4, U3.5
unnamed: U3.9, U3.10
unnamed: U3.11, U3.12
unnamed: C5.1, C6.1, FB3.2, U3.14 (VCC)
unnamed: R5.1, U4.9 (CP)
unnamed: R11.1, U4.2 (Q0)
unnamed: R10.1, U4.5 (Q1)
unnamed: R9.1, U4.7 (Q2)
unnamed: R8.1, U4.10 (Q3)
unnamed: R7.1, U4.12 (Q4)
unnamed: R6.1, U4.15 (Q5)
unnamed: FB1.2, U5.5 (VDDA)
unnamed: C12.1, J2.A4 (VBUS), J2.A9 (VBUS), J2.B4 (VBUS), J2.B9 (VBUS), U6.1 (VIN), U6.3 (EN)
VCC: C9.1, C10.1, C14.1, C15.1, D1.2 (A), FB1.1, FB2.1, J3.1, R1.1, SW1.2, U4.1 (MR), U4.16 (VCC), U5.16 (VDD), U6.5 (VOUT)
VCCQ: C7.1, C8.1, C16.1, FB2.2, FB3.1, FB4.1, FB5.1

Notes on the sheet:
74LVC04ADTR2G

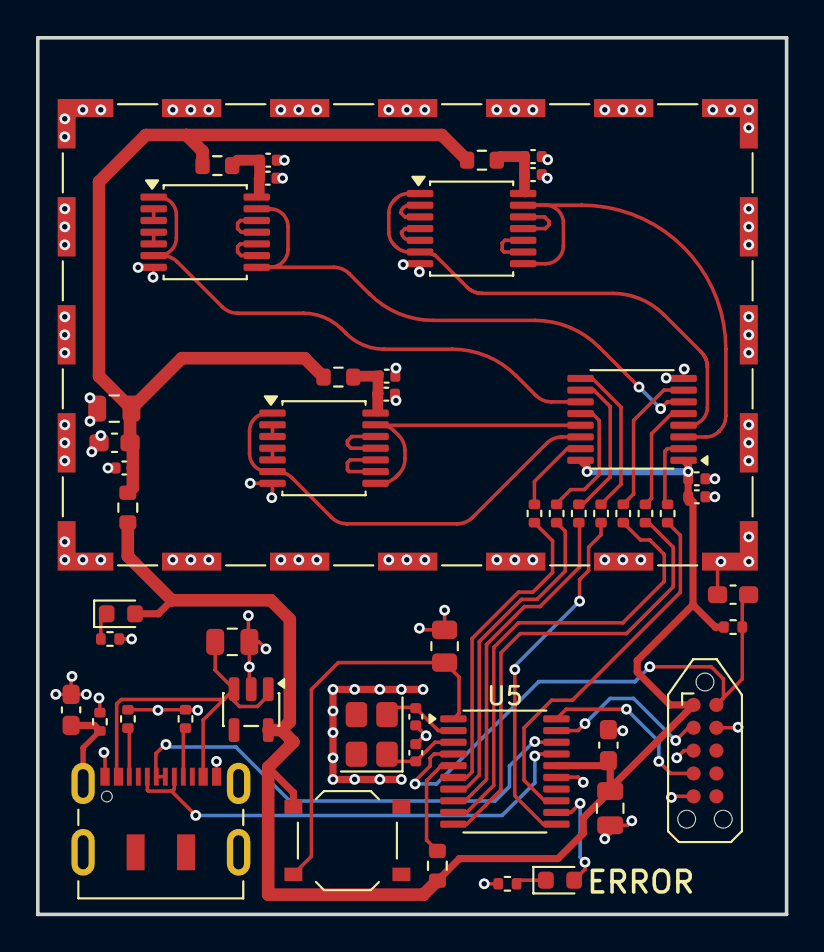
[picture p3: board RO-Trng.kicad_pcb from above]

Board: 2 copper layers, 41.6 x 48.7 mm, 50 parts (0 on the bottom side), 54 nets.

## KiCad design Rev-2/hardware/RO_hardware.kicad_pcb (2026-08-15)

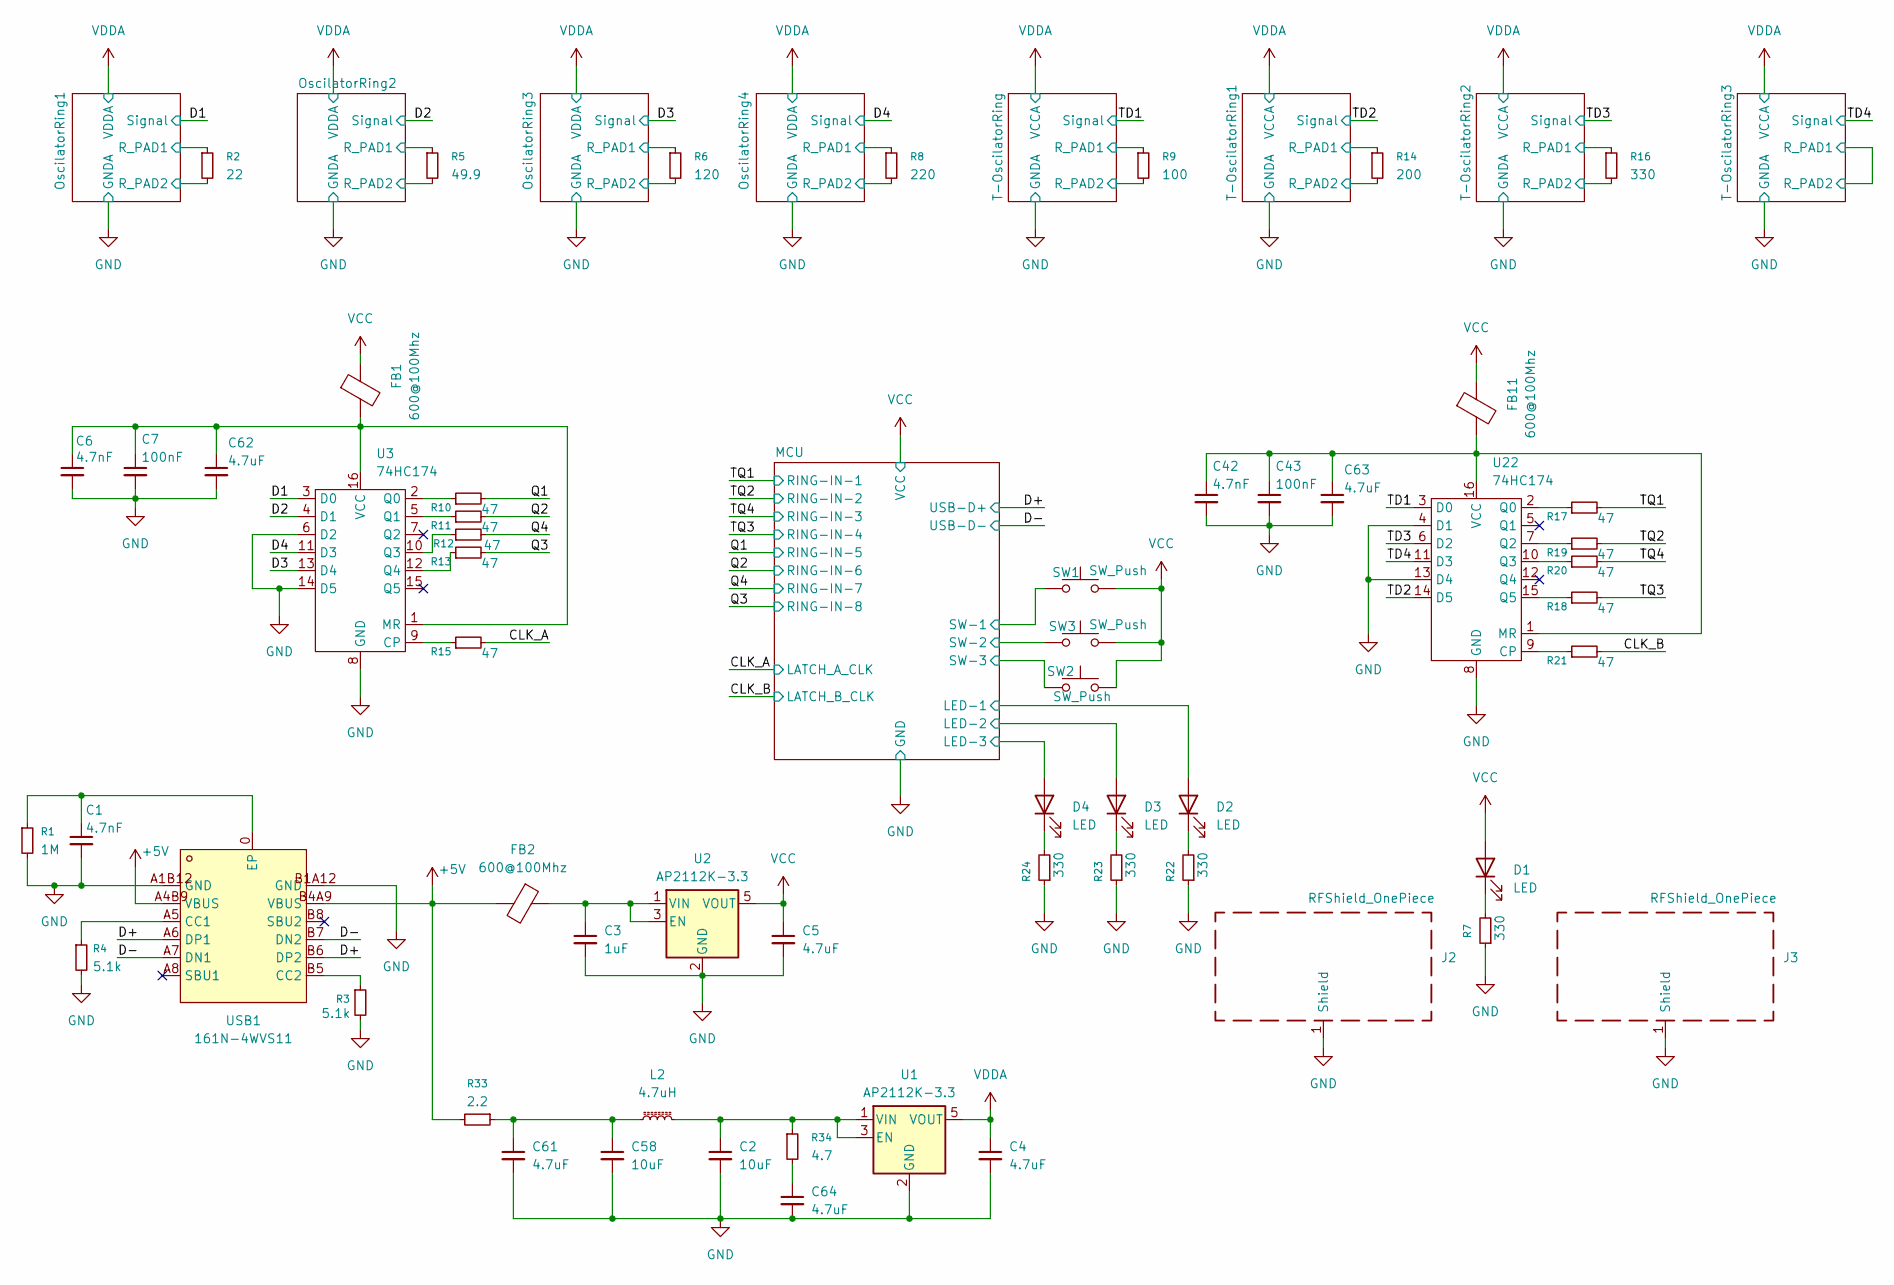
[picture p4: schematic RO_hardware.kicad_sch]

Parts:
C1: 4.7nF; C_0805_2012Metric
C2, C58: 10uF; C_1206_3216Metric
C3: 1uF; C_1206_3216Metric
C4, C5, C61, C62, C63, C64: 4.7uF; C_1206_3216Metric
C6, C42: 4.7nF; C_0402_1005Metric
C7, C43: 100nF; C_0402_1005Metric
D1, D2, D3, D4: LED; D_0805_2012Metric
FB1, FB2, FB11: 600@100Mhz; R_0603_1608Metric
J2, J3: RFShield_OnePiece; Laird_Technologies_BMI-S-205-F_38.10x25.40mm
L2: 4.7uH; L_1008_2520Metric
R1: 1M; R_0805_2012Metric
R2: 22; R_0402_1005Metric
R3, R4: 5.1k; R_0805_2012Metric
R5: 49.9; R_0402_1005Metric
R6: 120; R_0402_1005Metric
R7, R22, R23, R24: 330; R_0805_2012Metric
R8: 220; R_0402_1005Metric
R9: 100; R_0402_1005Metric
R10, R11, R12, R13, R15, R17, R18, R19, R20, R21: 47; R_0402_1005Metric
R14: 200; R_0402_1005Metric
R16: 330; R_0402_1005Metric
R33: 2.2; R_0805_2012Metric
R34: 4.7; R_0603_1608Metric
SW1, SW2, SW3: SW_Push; XKBConnection-TS_1187A_B_AB
U1, U2: AP2112K-3.3; SOT-23-5
U3, U22: 74HC174; TSSOP-16_4.4x5mm_P0.65mm
USB1: 161N-4WVS11; USB-C-SMD_HANELECTRICITY_161N-4XVS11; MPN 161N-4WVS11; LCSC Part C5440753

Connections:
+5V: FB2.2, R33.2, USB1.A4B9 (VBUS), USB1.B4A9 (VBUS)
/CLK_A: R15.2; also elsewhere on the board
/CLK_B: R21.2; also elsewhere on the board
/D1: R2.1, U3.3 (D0); also elsewhere on the board
/D2: R5.1, U3.4 (D1); also elsewhere on the board
/D3: R6.1, U3.13 (D4); also elsewhere on the board
/D4: R8.1, U3.11 (D3); also elsewhere on the board
/D+: USB1.A6 (DP1), USB1.B6 (DP2); also elsewhere on the board
/D-: USB1.A7 (DN1), USB1.B7 (DN2); also elsewhere on the board
/MCU/LED-1: D2.2 (A); also elsewhere on the board
/MCU/LED-2: D3.2 (A); also elsewhere on the board
/MCU/LED-3: D4.2 (A); also elsewhere on the board
/MCU/SW-1: SW1.1; also elsewhere on the board
/MCU/SW-2: SW3.1; also elsewhere on the board
/MCU/SW-3: SW2.1; also elsewhere on the board
/OscilatorRing1/R_PAD2: R2.2; also elsewhere on the board
/OscilatorRing2/R_PAD2: R5.2; also elsewhere on the board
/OscilatorRing3/R_PAD2: R6.2; also elsewhere on the board
/OscilatorRing4/R_PAD2: R8.2; also elsewhere on the board
/Q1: R10.2; also elsewhere on the board
/Q2: R11.2; also elsewhere on the board
/Q3: R13.2; also elsewhere on the board
/Q4: R12.2; also elsewhere on the board
/T-OscilatorRing1/R_PAD2: R14.2; also elsewhere on the board
/T-OscilatorRing2/R_PAD2: R16.2; also elsewhere on the board
/T-OscilatorRing/R_PAD2: R9.2; also elsewhere on the board
/TD1: R9.1, U22.3 (D0); also elsewhere on the board
/TD2: R14.1, U22.14 (D5); also elsewhere on the board
/TD3: R16.1, U22.6 (D2); also elsewhere on the board
/TD4: U22.11 (D3); also elsewhere on the board
/TQ1: R17.2; also elsewhere on the board
/TQ2: R19.2; also elsewhere on the board
/TQ3: R18.2; also elsewhere on the board
/TQ4: R20.2; also elsewhere on the board
GND: C1.2, C2.2, C3.2, C4.2, C5.2, C6.2, C7.2, C42.2, C43.2, C58.2, C61.2, C62.2, C63.2, C64.2, J2.1 (Shield), J3.1 (Shield), R1.2, R3.2, R4.2, R7.1, R22.1, R23.1, R24.1, U1.2 (GND), U2.2 (GND), U3.6 (D2), U3.8 (GND), U3.14 (D5), U22.4 (D1), U22.8 (GND), U22.13 (D4), USB1.A1B12 (GND), USB1.B1A12 (GND); also elsewhere on the board
unnamed: C58.1, C61.1, L2.1, R33.1
unnamed: C64.1, R34.2
unnamed: D1.1 (K), R7.2
unnamed: D2.1 (K), R22.2
unnamed: D3.1 (K), R23.2
unnamed: D4.1 (K), R24.2
unnamed: C2.1, L2.2, R34.1, U1.1 (VIN), U1.3 (EN)
unnamed: C3.1, FB2.1, U2.1 (VIN), U2.3 (EN)
unnamed: R15.1, U3.9 (CP)
unnamed: C6.1, C7.1, C62.1, FB1.2, U3.1 (MR), U3.16 (VCC)
unnamed: R10.1, U3.2 (Q0)
unnamed: R11.1, U3.5 (Q1)
unnamed: R12.1, U3.10 (Q3)
unnamed: R13.1, U3.12 (Q4)
unnamed: R21.1, U22.9 (CP)
unnamed: C42.1, C43.1, C63.1, FB11.2, U22.1 (MR), U22.16 (VCC)
unnamed: R17.1, U22.2 (Q0)
unnamed: R19.1, U22.7 (Q2)
unnamed: R20.1, U22.10 (Q3)
unnamed: R18.1, U22.15 (Q5)
unnamed: R4.1, USB1.A5 (CC1)
unnamed: R3.1, USB1.B5 (CC2)
unnamed: C1.1, R1.1, USB1.0 (EP)
VCC: C5.1, D1.2 (A), FB1.1, FB11.1, SW1.2, SW2.2, SW3.2, U2.5 (VOUT); also elsewhere on the board
VDDA: C4.1, U1.5 (VOUT); also elsewhere on the board

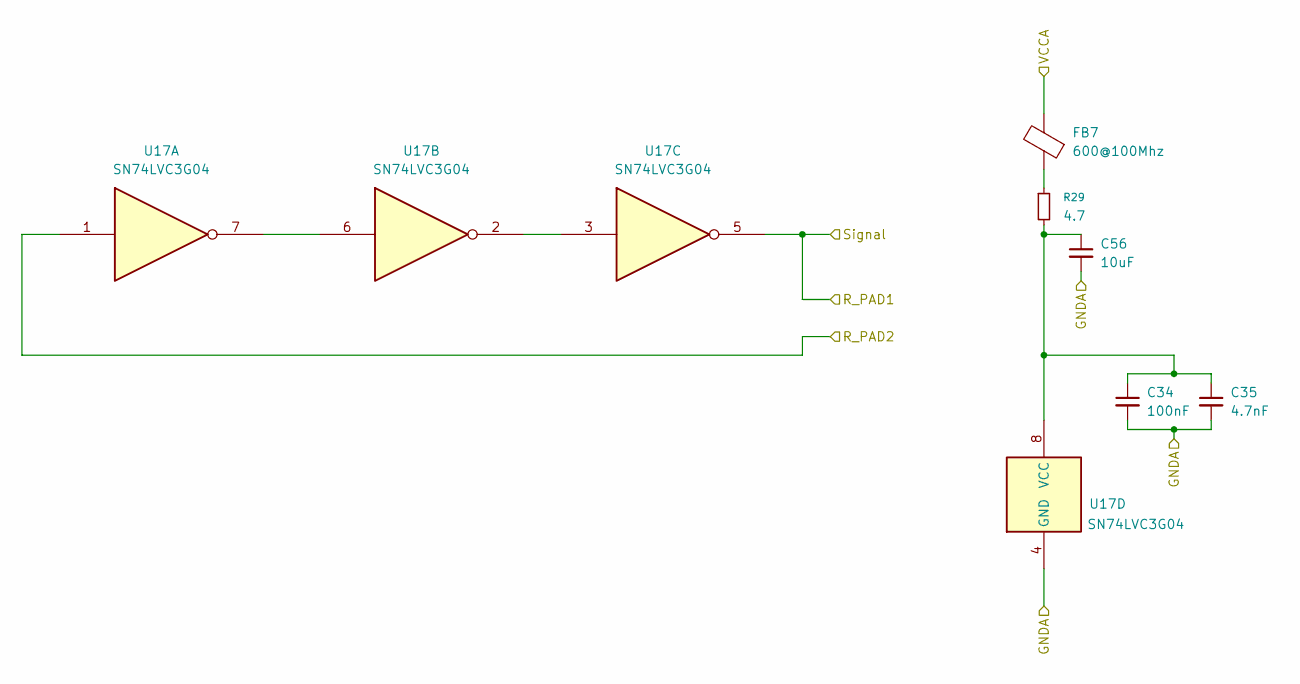
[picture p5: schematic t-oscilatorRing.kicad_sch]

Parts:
C34: 100nF; C_0402_1005Metric
C35: 4.7nF; C_0402_1005Metric
C56: 10uF; C_0805_2012Metric
FB7: 600@100Mhz; R_0603_1608Metric
R29: 4.7; R_0603_1608Metric
U17: SN74LVC3G04; MSOP-8_3x3mm_P0.65mm

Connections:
/T-OscilatorRing/R_PAD2: U17.1; also elsewhere on the board
/TD1: U17.5; also elsewhere on the board
GND: C34.2, C35.2, C56.2, U17.4 (GND); also elsewhere on the board
unnamed: FB7.1, R29.1
unnamed: U17.2, U17.3
unnamed: U17.6, U17.7
unnamed: C34.1, C35.1, C56.1, R29.2, U17.8 (VCC)
VDDA: FB7.2; also elsewhere on the board

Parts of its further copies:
C36, C38, C40: 100nF; C_0402_1005Metric
C37, C39, C41: 4.7nF; C_0402_1005Metric
C57, C59, C60: 10uF; C_0805_2012Metric
FB8, FB9, FB10: 600@100Mhz; R_0603_1608Metric
R30, R31, R32: 4.7; R_0603_1608Metric
U18, U19, U20: SN74LVC3G04; MSOP-8_3x3mm_P0.65mm

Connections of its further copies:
/T-OscilatorRing1/R_PAD2: U18.1; also elsewhere on the board
/T-OscilatorRing2/R_PAD2: U19.1; also elsewhere on the board
/TD2: U18.5; also elsewhere on the board
/TD3: U19.5; also elsewhere on the board
/TD4: U20.1, U20.5; also elsewhere on the board
GND: C36.2, C37.2, C38.2, C39.2, C40.2, C41.2, C57.2, C59.2, C60.2, U18.4 (GND), U19.4 (GND), U20.4 (GND); also elsewhere on the board
unnamed: FB8.1, R30.1
unnamed: FB9.1, R31.1
unnamed: FB10.1, R32.1
unnamed: U18.2, U18.3
unnamed: U18.6, U18.7
unnamed: C36.1, C37.1, C57.1, R30.2, U18.8 (VCC)
unnamed: U19.2, U19.3
unnamed: U19.6, U19.7
unnamed: C38.1, C39.1, C59.1, R31.2, U19.8 (VCC)
unnamed: U20.2, U20.3
unnamed: U20.6, U20.7
unnamed: C40.1, C41.1, C60.1, R32.2, U20.8 (VCC)
VDDA: FB8.2, FB9.2, FB10.2; also elsewhere on the board

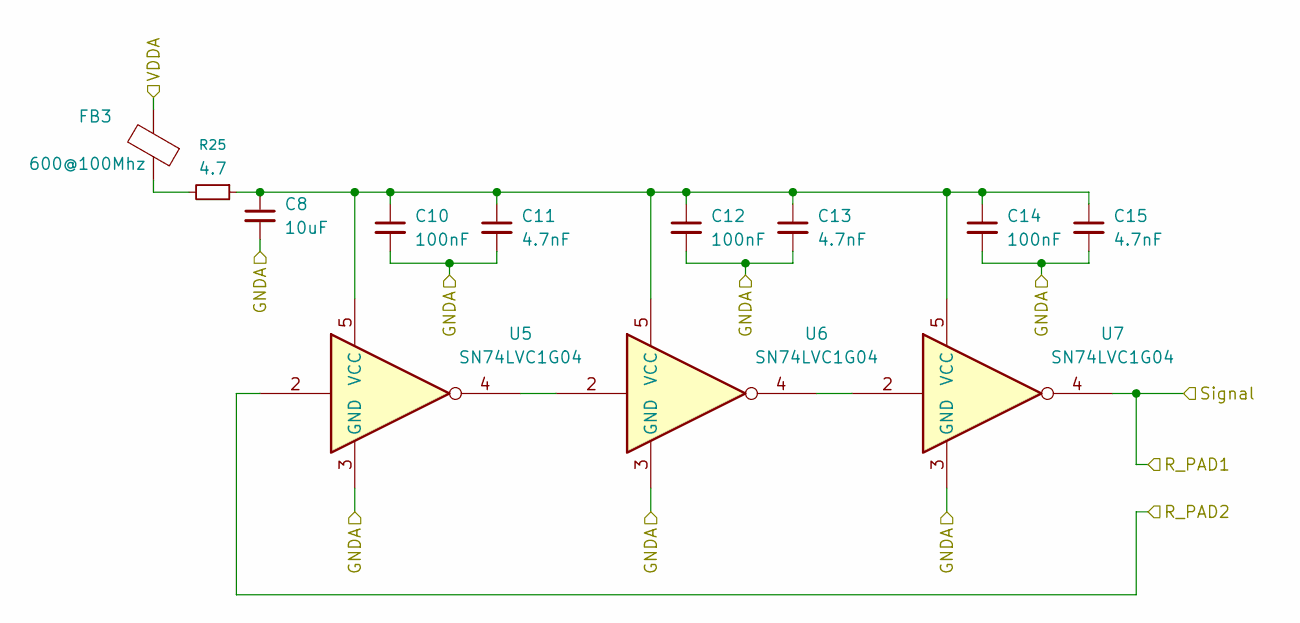
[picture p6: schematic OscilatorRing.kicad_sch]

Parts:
C8: 10uF; C_0805_2012Metric
C10, C12, C14: 100nF; C_0402_1005Metric
C11, C13, C15: 4.7nF; C_0402_1005Metric
FB3: 600@100Mhz; R_0603_1608Metric
R25: 4.7; R_0603_1608Metric
U5, U6, U7: SN74LVC1G04; SOT-353_SC-70-5

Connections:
/D1: U7.4; also elsewhere on the board
/OscilatorRing1/R_PAD2: U5.2; also elsewhere on the board
GND: C8.2, C10.2, C11.2, C12.2, C13.2, C14.2, C15.2, U5.3 (GND), U6.3 (GND), U7.3 (GND); also elsewhere on the board
unnamed: FB3.1, R25.2
unnamed: U5.4, U6.2
unnamed: C8.1, C10.1, C11.1, C12.1, C13.1, C14.1, C15.1, R25.1, U5.5 (VCC), U6.5 (VCC), U7.5 (VCC)
unnamed: U6.4, U7.2
VDDA: FB3.2; also elsewhere on the board

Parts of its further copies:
C9, C44, C45: 10uF; C_0805_2012Metric
C16, C18, C20, C22, C24, C26, C28, C30, C32: 100nF; C_0402_1005Metric
C17, C19, C21, C23, C25, C27, C29, C31, C33: 4.7nF; C_0402_1005Metric
FB4, FB5, FB6: 600@100Mhz; R_0603_1608Metric
R26, R27, R28: 4.7; R_0603_1608Metric
U8, U9, U10, U11, U12, U13, U14, U15, U16: SN74LVC1G04; SOT-353_SC-70-5

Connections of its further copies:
/D2: U10.4; also elsewhere on the board
/D3: U13.4; also elsewhere on the board
/D4: U16.4; also elsewhere on the board
/OscilatorRing2/R_PAD2: U8.2; also elsewhere on the board
/OscilatorRing3/R_PAD2: U11.2; also elsewhere on the board
/OscilatorRing4/R_PAD2: U14.2; also elsewhere on the board
GND: C9.2, C16.2, C17.2, C18.2, C19.2, C20.2, C21.2, C22.2, C23.2, C24.2, C25.2, C26.2, C27.2, C28.2, C29.2, C30.2, C31.2, C32.2, C33.2, C44.2, C45.2, U8.3 (GND), U9.3 (GND), U10.3 (GND), U11.3 (GND), U12.3 (GND), U13.3 (GND), U14.3 (GND), U15.3 (GND), U16.3 (GND); also elsewhere on the board
unnamed: FB4.1, R26.2
unnamed: FB5.1, R27.2
unnamed: FB6.1, R28.2
unnamed: U8.4, U9.2
unnamed: U9.4, U10.2
unnamed: C9.1, C16.1, C17.1, C18.1, C19.1, C20.1, C21.1, R26.1, U8.5 (VCC), U9.5 (VCC), U10.5 (VCC)
unnamed: U11.4, U12.2
unnamed: C22.1, C23.1, C24.1, C25.1, C26.1, C27.1, C44.1, R27.1, U11.5 (VCC), U12.5 (VCC), U13.5 (VCC)
unnamed: U12.4, U13.2
unnamed: U14.4, U15.2
unnamed: C28.1, C29.1, C30.1, C31.1, C32.1, C33.1, C45.1, R28.1, U14.5 (VCC), U15.5 (VCC), U16.5 (VCC)
unnamed: U15.4, U16.2
VDDA: FB4.2, FB5.2, FB6.2; also elsewhere on the board

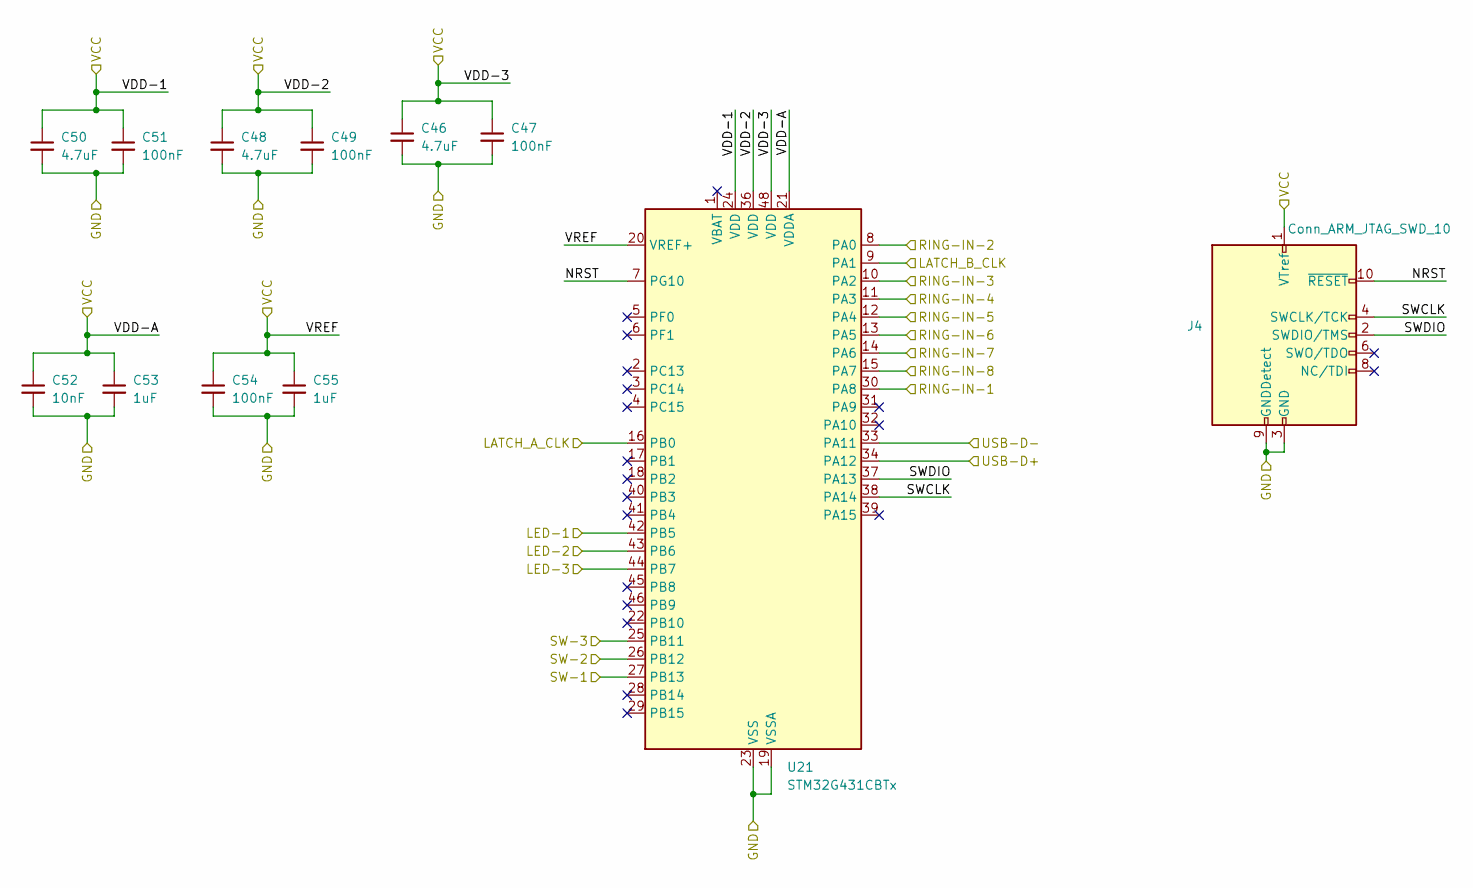
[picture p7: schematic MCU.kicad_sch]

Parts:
C46, C48, C50: 4.7uF; C_1206_3216Metric
C47, C49, C51, C54: 100nF; C_1206_3216Metric
C52: 10nF; C_1206_3216Metric
C53, C55: 1uF; C_1206_3216Metric
J4: Conn_ARM_JTAG_SWD_10; Tag-Connect_TC2050-IDC-NL_2x05_P1.27mm_Vertical
U21: STM32G431CBTx; LQFP-48_7x7mm_P0.5mm

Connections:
/CLK_A: U21.16 (PB0); also elsewhere on the board
/CLK_B: U21.9 (PA1); also elsewhere on the board
/D+: U21.34 (PA12); also elsewhere on the board
/D-: U21.33 (PA11); also elsewhere on the board
/MCU/LED-1: U21.42 (PB5); also elsewhere on the board
/MCU/LED-2: U21.43 (PB6); also elsewhere on the board
/MCU/LED-3: U21.44 (PB7); also elsewhere on the board
/MCU/NRST: J4.10 (~RESET), U21.7 (PG10)
/MCU/SW-1: U21.27 (PB13); also elsewhere on the board
/MCU/SW-2: U21.26 (PB12); also elsewhere on the board
/MCU/SW-3: U21.25 (PB11); also elsewhere on the board
/MCU/SWCLK: J4.4 (SWCLK/TCK), U21.38 (PA14)
/MCU/SWDIO: J4.2 (SWDIO/TMS), U21.37 (PA13)
/Q1: U21.12 (PA4); also elsewhere on the board
/Q2: U21.13 (PA5); also elsewhere on the board
/Q3: U21.15 (PA7); also elsewhere on the board
/Q4: U21.14 (PA6); also elsewhere on the board
/TQ1: U21.30 (PA8); also elsewhere on the board
/TQ2: U21.8 (PA0); also elsewhere on the board
/TQ3: U21.11 (PA3); also elsewhere on the board
/TQ4: U21.10 (PA2); also elsewhere on the board
GND: C46.2, C47.2, C48.2, C49.2, C50.2, C51.2, C52.2, C53.2, C54.2, C55.2, J4.3 (GND), J4.5 (GND), J4.9 (GNDDetect), U21.19 (VSSA), U21.23 (VSS), U21.35 (VSS), U21.47 (VSS); also elsewhere on the board
VCC: C46.1, C47.1, C48.1, C49.1, C50.1, C51.1, C52.1, C53.1, C54.1, C55.1, J4.1 (VTref), U21.20 (VREF+), U21.21 (VDDA), U21.24 (VDD), U21.36 (VDD), U21.48 (VDD); also elsewhere on the board

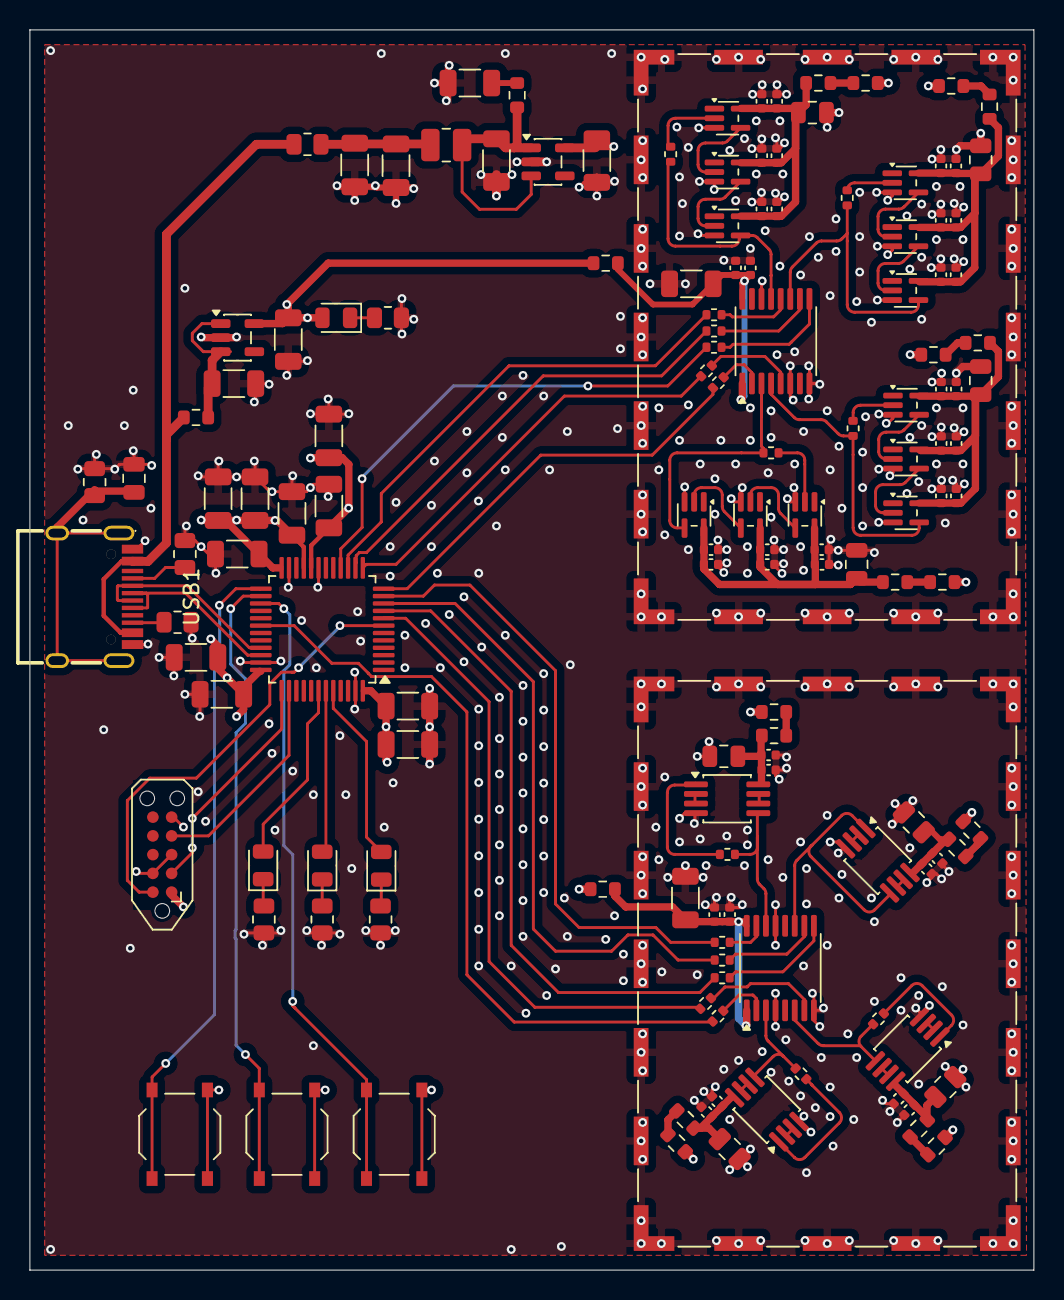
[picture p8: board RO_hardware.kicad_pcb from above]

Board: 4 copper layers, 68.0 x 84.0 mm, 142 parts (0 on the bottom side), 95 nets.

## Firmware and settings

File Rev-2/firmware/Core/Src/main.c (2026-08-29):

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
/* Includes ------------------------------------------------------------------*/
#include "main.h"
#include "usb_device.h"

/* USER CODE BEGIN Includes */
#include "entropy_collector.h"
#include "sender.h"
#include "haptic.h"
#include "buttons.h"
/* USER CODE END Includes */

TIM_HandleTypeDef htim6;

void SystemClock_Config(void);
static void MX_GPIO_Init(void);
static void MX_TIM6_Init(void);
/**
  * @brief  The application entry point.
  * @retval int
  */
int main(void)
{

  /* MCU Configuration--------------------------------------------------------*/

  /* Reset of all peripherals, Initializes the Flash interface and the Systick. */
  HAL_Init();

  /* Configure the system clock */
  SystemClock_Config();

  /* Initialize all configured peripherals */
  MX_GPIO_Init();
  MX_TIM6_Init();
  MX_USB_Device_Init();
  /* USER CODE BEGIN 2 */

  loadConfiguration();
  HAL_TIM_Base_Start_IT(&htim6);
  /* USER CODE END 2 */

  /* Infinite loop */
  /* USER CODE BEGIN WHILE */
	while (1) {
		/* USER CODE END WHILE */

		/* USER CODE BEGIN 3 */
		//look also into usbd_cdc_if.c method CDC_Receive_FS
		//and stm32g4xx_it.c method TIM6_DAC_IRQHandler
		buttonsUpdate();
		if (buttonPressed(BUTTON_SELF_TEST)) {
			startSelfTest();
		}
		if (buttonPressed(BUTTON_RESTART)) {
			restartAcquisition();
		}
		updateCollector();
		updateSender();
		ledUpdate();
	}
  /* USER CODE END 3 */
}

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


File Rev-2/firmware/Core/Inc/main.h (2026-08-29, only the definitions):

#define ring_in2_Pin GPIO_PIN_0
#define ring_in2_GPIO_Port GPIOA
#define latch_b_Pin GPIO_PIN_1
#define latch_b_GPIO_Port GPIOA
#define ring_in3_Pin GPIO_PIN_2
#define ring_in3_GPIO_Port GPIOA
#define ring_in4_Pin GPIO_PIN_3
#define ring_in4_GPIO_Port GPIOA
#define ring_in5_Pin GPIO_PIN_4
#define ring_in5_GPIO_Port GPIOA
#define ring_in6_Pin GPIO_PIN_5
#define ring_in6_GPIO_Port GPIOA
#define ring_in7_Pin GPIO_PIN_6
#define ring_in7_GPIO_Port GPIOA
#define ring_in8_Pin GPIO_PIN_7
#define ring_in8_GPIO_Port GPIOA
#define latch_a_Pin GPIO_PIN_0
#define latch_a_GPIO_Port GPIOB
#define sw3_Pin GPIO_PIN_11
#define sw3_GPIO_Port GPIOB
#define sw1_Pin GPIO_PIN_13
#define sw1_GPIO_Port GPIOB
#define ring_in1_Pin GPIO_PIN_8
#define ring_in1_GPIO_Port GPIOA
#define led1_Pin GPIO_PIN_5
#define led1_GPIO_Port GPIOB
#define led2_Pin GPIO_PIN_6
#define led2_GPIO_Port GPIOB
#define led3_Pin GPIO_PIN_7
#define led3_GPIO_Port GPIOB
#define sw2_boot_Pin GPIO_PIN_8
#define sw2_boot_GPIO_Port GPIOB

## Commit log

2026-07-31 design of hardware, some python tools
    [BOM-RO-Trng.csv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]
2026-08-05 Stabilization of timers, improve speed, reduce IRQ usage
2026-08-10 PCB update
    [BOM-RO-Trng.csv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]
2026-08-10 update capacitors from 12 to 18pF
    [BOM-RO-Trng.csv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]
2026-08-15 Rev 2 of hardware
    [BOM-RO_hardware.csv, MCU.kicad_sch, OscilatorRing.kicad_sch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]
2026-08-29 Rev-2 firmware, measurement tooling and documentation
    Firmware for the Rev-2 board (STM32G431CB, 8 rings in two groups behind two
    74HC174 latches), ported from Rev-1 with the entropy and USB handling kept
    close to 1:1.
    Firmware
    - 8 channels instead of 6; ring outputs are spread over PA0 and PA2..PA8, so
    one GPIOA->IDR read is unpacked by a 512-entry LUT in ring order
    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
    [FRO.sch, WhiteNoise.sch, multi_rng.kicad_pcb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]

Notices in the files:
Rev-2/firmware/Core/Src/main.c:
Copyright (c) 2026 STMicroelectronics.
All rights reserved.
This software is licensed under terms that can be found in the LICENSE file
